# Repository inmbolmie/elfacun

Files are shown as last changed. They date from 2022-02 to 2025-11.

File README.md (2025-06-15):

# Elfacun Chess Interface Module

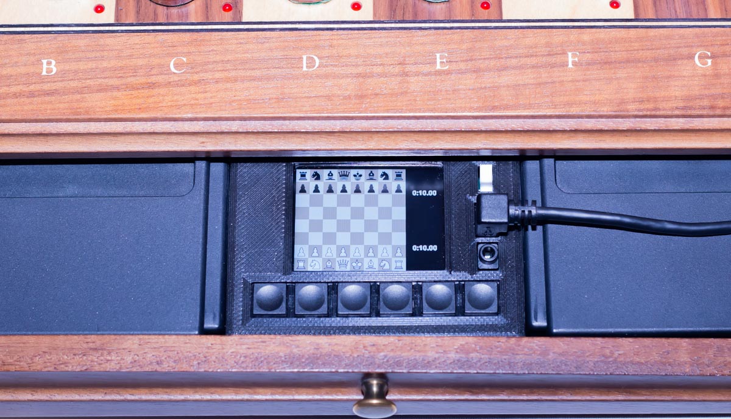
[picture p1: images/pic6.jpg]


## News

__(2025/06/15): Source code and design files for V2 module released: ----- [Make your own module](./SOURCE.md)__

## Elfacun chess module

This is an ongoing hardware project to create a chess module compatible with the old Mephisto modular boards (Exclusive, Modular, München) that will provide connectivity to a wide variety of chess apps and services.

The project currently comprises three devices:

* Elfacun chess module, that is the main module that enables the connectivity of modern apps to the Mephisto chess boards
* Brocoli power module, to be able to power Elfacun, the Mephisto board and some original modules from a regular USB power bank to get a true wireless chess board.
* Diablillo bridge adapter, that allows to connect wirelessly a physical Millennium chess module to Elfacun.

The hardware as well as software developed for it are published here under the GPL license.

To assist in the release of the module, I provide here links to some basic documentation:

* [V1 and V2 modules description and features](./DESCRIPTION.md)
* [Brocoli power module](./BROCOLI.md)
* [Diablillo bridge adapter](./DIABLILLO.md)
* [Compatibility chart](./COMPATIBILITY.md)
* [Limitations and remarks](./LIMITATIONS.md)
* [Operation manual](./MANUAL.md)
* [Make your own module](./SOURCE.md)

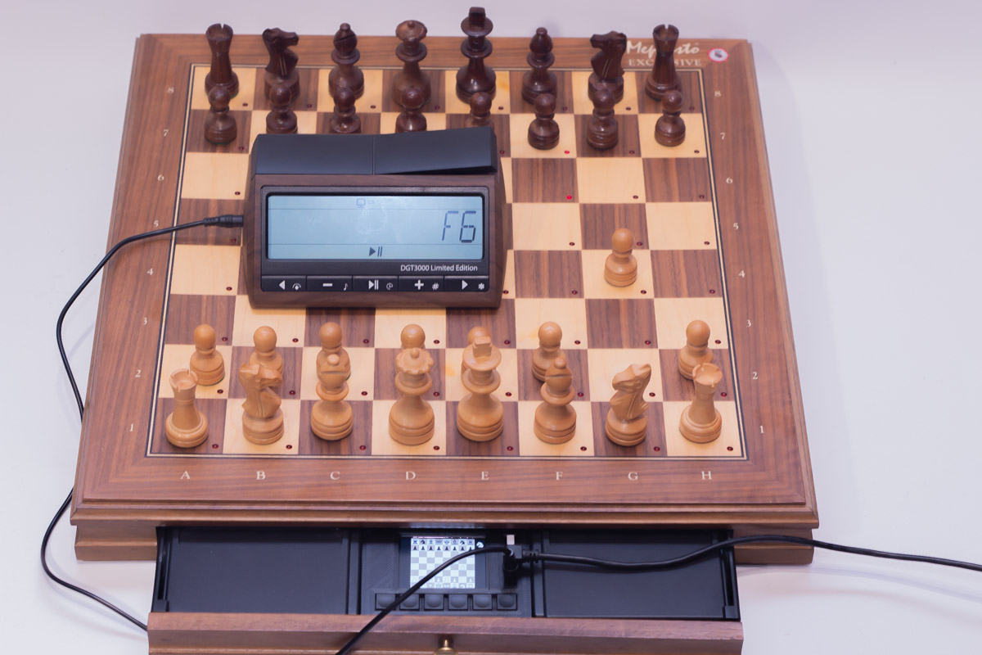
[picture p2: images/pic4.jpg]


## Old News

__(2025/02/23): Elfacun software version R15 released with chess 960 support:__ Link: ----- __[R15 files](https://github.com/inmbolmie/elfacun/releases/tag/R15)__ ----- Installation instructions: ----- __[Update Elfacun](./MANUAL.md#update-elfacun-software)__

__(2025/02/23): Diablillo software version R15 released with bug fixes:__ Link: ----- __[R15 files](https://github.com/inmbolmie/elfacun/releases/tag/R15)__ ----- Installation instructions: ----- __[Update Diabillo](./DIABLILLO.md#update-diablillo-software)__

__(2024/05/26): Elfacun software version R14 released with bug fixes:__ Link: ----- __[R14 files](https://github.com/inmbolmie/elfacun/releases/tag/R14)__ ----- Installation instructions: ----- __[Update Elfacun](./MANUAL.md#update-elfacun-software)__

__(2024/01/19): Elfacun software version R12 released with improvements for Lichess mode:__ Link: ----- __[R12 files](https://github.com/inmbolmie/elfacun/releases/tag/R12)__ ----- Installation instructions: ----- __[Update Elfacun](./MANUAL.md#update-elfacun-software)__

__(2023/09/16): Elfacun software version R11 released with new Chessnut-compatible mode:__ Link: ----- __[R11 files](https://github.com/inmbolmie/elfacun/releases/tag/R11)__ ----- Installation instructions: ----- __[Update Elfacun](./MANUAL.md#update-elfacun-software)__

__(2023/07/13): Elfacun software version R10 released with bug fixes:__ Link: ----- __[R10 files](https://github.com/inmbolmie/elfacun/releases/tag/R10)__ ----- Installation instructions: ----- __[Update Elfacun](./MANUAL.md#update-elfacun-software)__

__(2023/06/12): Elfacun software version R9 released with bug fixes:__ Link: ----- __[R9 files](https://github.com/inmbolmie/elfacun/releases/tag/R9)__ ----- Installation instructions: ----- __[Update Elfacun](./MANUAL.md#update-elfacun-software)__

__(2023/06/07): Elfacun software version R8 released with support for the new _Diablillo_ device:__ Link: ----- __[R8 files](https://github.com/inmbolmie/elfacun/releases/tag/R8)__ ----- Installation instructions: ----- __[Update Elfacun](./MANUAL.md#update-elfacun-software)__

__(2023/03/05): Elfacun software version R7 released with on-screen LED indications in passive mode, board position storage and customizable sound and BLE power level:__ Link: ----- __[R7 files](https://github.com/inmbolmie/elfacun/releases/tag/R7)__ ----- Installation instructions: ----- __[Update Elfacun](./MANUAL.md#update-elfacun-software)__

__(2023/02/08): Elfacun software version R6 released with opponent ELO range on Lichess challenges:__ Link: ----- __[R6 files](https://github.com/inmbolmie/elfacun/releases/tag/R6)__ ----- Installation instructions: ----- __[Update Elfacun](./MANUAL.md#update-elfacun-software)__

__(2023/01/30): Elfacun software version R5 released with some bug fixes:__ Link: ----- __[R5 files](https://github.com/inmbolmie/elfacun/releases/tag/R5)__ ----- Installation instructions: ----- __[Update Elfacun](./MANUAL.md#update-elfacun-software)__

__(2023/01/28): Elfacun hardware version 2 released with new features and improved compatibility with original modules:__ Links: ----- __[V2 features](./DESCRIPTION.md#features)__ ----- __[V2 manual](./MANUAL.md#new-v1-and-v2-features)__ ----- __[V2 compatibility](./COMPATIBILITY.md#v2-with-original-mephisto-modules)__

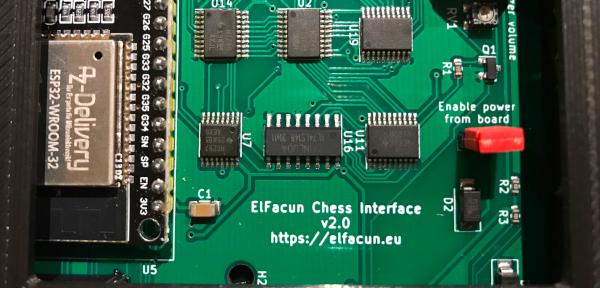
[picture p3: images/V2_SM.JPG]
V2


__(2023/01/28): Brocoli battery power module for Elfacun:__ Link: ----- __[Brocoli power module](./BROCOLI.md)__

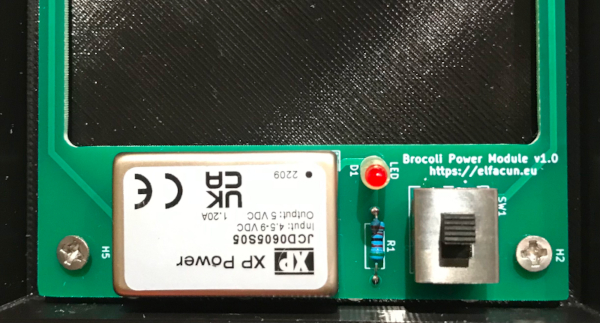
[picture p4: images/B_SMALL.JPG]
Brocoli


__(2022/05/04): Elfacun software version R4 released with some bug fixes: [R4 files](https://github.com/inmbolmie/elfacun/releases/tag/R4)__ Installation instructions: ----- __[Update Elfacun](./MANUAL.md#update-elfacun-software)__

__(2022/09/03): Source code and design files released: ----- [Make your own module](./SOURCE.md)__

_"DGT", "Millennium", "Mephisto", "Chessnut" and "IChessOne" are trademarks of their respective owners.
All the trademarks are used nominatively to indicate compatibility, and do not indicate affiliation to or endorsement by the trademark owners._

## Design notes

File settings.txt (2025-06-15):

#Elfacun settings
#Edit this file (settings.txt) and place it in the root directory of an SD card compatible with SPI mode (most micro-sd aren't)
#Power up the module with the SD inserted (you don't need to have the module inserted into the board)
#The settings will be read and stored in permanent memory
#Remove the SD card and use the module normally
#If you also want to perform a system update place in the SD card root directory the file "update.bin"

#Base MAC address. If not defined, the module will use the default MAC assigned at the factory
#so it is not recommended to modify it unless you have any problem
#Bluetooth MAC will be base MAC plus 2
#
#base.mac.address=12:34:56:78:9A:BC

#Default board mode
#This is the mode the module will boot at by default
#Valid values are: A, B, C, L
#Default value is A
#The serial port will operate at 9600 8N1 in mode A
#The serial port will operate at 38400 bauds 7O1 in mode B
#L is for Lichess mode
#To boot the module in the non-default mode, keep pressed some module buttons while booting:
#For mode A first button
#For mode B second button
#For mode C first + second buttons
#For mode L third button
#
mode.default=A

#Bluetooth name advertised in mode A
#Default value is "ELFACUN CHESS"
#
#mode.a.bt.advertised.name=ELFACUN CHESS

#Bluetooth name advertised in mode B
#Default value is "ELFACUN CHESS"
#
#mode.b.bt.advertised.name=ELFACUN CHESS

#Bluetooth name advertised in mode C
#Default value is "ELFACUN CHESS"
#
#mode.c.bt.advertised.name=ELFACUN CHESS

#Mode A board identification parameters
#Uncomment to get custom board identification values sent to the driver
#mode.a.trademark is an arbitrary string
#serial.number.long has to be exactly 10 characters long
#serial.number.short has to be exactly 5 characters long
#version numbers are numbers between 0 and 255
#
#mode.a.trademark=Elfacun https://elfacun.eu
#mode.a.version.major=0
#mode.a.version.minor=60
#mode.a.clock.version.major=2
#mode.a.clock.version.minor=0
#mode.a.serial.number.long=3.24000000
#mode.a.serial.number.short=00001

#Buzzer enabled
#Valid values are true, false
#Default value is true
#To boot the module with the opposite value, keep pressed the right-most button while booting
#
buzzer.enabled=true

#Buzzer enabled for passive led indications on screen
#Valid values are true, false
#Default value is true
#When in passive mode with original modules Elfacun cannot use the on-board leds
#so it uses the screen to indicate incoming led information. When this is enables the led
#indications on-screen are accompanied by sounds
#
buzzer.enabled.passive.led=true

#Buzzer tones setup 
#You can change the frequency and duration of the sound tones:
#Tone 1 is piece raise
#Tone 2 is piece placement
#Tone 3 is led sound for passive mode
#Frequency is in hertzs
#Duration is in milliseconds
#
#buzzer.tone.1.frequency=2000
#buzzer.tone.1.duration=100
#
#buzzer.tone.2.frequency=1000
#buzzer.tone.2.duration=100
#
#buzzer.tone.3.frequency=1500
#buzzer.tone.3.duration=20

#LEDS enabled
#Valid values are true, false
#Default value is true
#To boot the module with the opposite value, keep pressed the second right-most button while booting
#
leds.enabled=true

#DUAL LEDS enabled (Only V2 modules)
#Valid values are true, false
#Default value is false
#When a V2 module starts in passive mode and this parameter is enables, the module will scan for the
#presence of other Elfacun module (V1 or V2) using BLE. If it finds it, it will start a BLE connection to
#relay its LED status, so both modules will be able to control the board LEDs
#It is disabled by default as it only makes sense if you have two modules and with the feature disabled the
#passive mode startup will be faster
#
leds.dual.enabled=false

#REVELATION-II button order
#Valid values are true, false
#Default value is false
#If set to true, the first button will be the "change lever" button when operating in DGT mode, like in the Revelation-II board
#If set to false, the last button will be the "change lever" button
#
buttons.order.revelation=false

#Lichess mode settings
#Connection settings, you have to uncomment and complete them in order to be able to connect to lichess
#That is, you WIFI settings (ssid and password) and your lichess auth token
#
#lichess.wifi.ssid=YOUR_WIFI_NAME
#lichess.wifi.password=YOUR_WIFI_PASSWORD
#lichess.wifi.authtoken=YOUR_LICHESS_TOKEN
#
#
#Lichess board auto-reverse settings
#If auto-reverse is enabled and you play as black, the board is automatically reversed so you have to put the black pieces on the first rank
#If auto-reverse is disabled and you play as black, the board is not automatically reversed so you have to play black from the back of the board unless you manually reverse the board
#Setting is disabled by default (false)
#lichess.board.autoinvert=false
#
#
#Lichess play mode settings
#While not in a game:
#Buttons 1 to 6 are used to launch a challenge
#Once launched, you can cancel it pressing any button
#While in a game:
#Button 4 pushed twice offers take back
#Button 5 pushed twice offers a draw
#Button 6 pushed twice resigns
#You can edit the default mode definition. All the games are "standard" chess
#Game modes under 5 minutes are not allowed by Lichess being too fast for a physical board
#Game mode variables are:
# time -> Game time in minutes
# time -> Increment per move in seconds
# rated -> if the game is rated ("true") or unrated ("false")
# color -> your pieces color ("white", "black" or "random")
# elo -> The desired ELO range of the opponents ("none" to disable, or a range like "1500-1800")
#
#lichess.mode.1.time=10
#lichess.mode.1.increment=0
#lichess.mode.1.rated=true
#lichess.mode.1.color=random
#lichess.mode.1.elo=none
#
#lichess.mode.2.time=10
#lichess.mode.2.increment=5
#lichess.mode.2.rated=true
#lichess.mode.2.color=random
#lichess.mode.2.elo=none
#
#lichess.mode.3.time=15
#lichess.mode.3.increment=10
#lichess.mode.3.rated=true
#lichess.mode.3.color=random
#lichess.mode.3.elo=none
#
#lichess.mode.4.time=10
#lichess.mode.4.increment=0
#lichess.mode.4.rated=false
#lichess.mode.4.color=random
#lichess.mode.4.elo=none
#
#lichess.mode.5.time=10
#lichess.mode.5.increment=5
#lichess.mode.5.rated=false
#lichess.mode.5.color=random
#lichess.mode.5.elo=none
#
#lichess.mode.6.time=15
#lichess.mode.6.increment=10
#lichess.mode.6.rated=false
#lichess.mode.6.color=random
#lichess.mode.6.elo=none
#

#Screen brightness (Only V2 modules)
#Only for V2 modules, will be ignored on V1 modules
#Overrides the stored default screen brightness
#Valid values: 5-255
#Default value: 64
#
screen.brightness.default = 64

#Disable mode B checksum
#On R8 release checksum checking on incoming mode B messages has been enabled by default
#You can optionally disable it in case it is problematic with any app
#Valid values are true, false
#Default value is false
#
#parity.check.disabled=false

#Bluetooth power
#Set the ble and bluetooth classic power level
#it can help working with devices that are far away from the board
#It is not recommended to change this value unless you have BT reliability issues
#The valid values are 0-7
#The default value is 5
#bluetooh.power=0  -----> Corresponding to -12dbm
#bluetooh.power=1  -----> Corresponding to  -9dbm
#bluetooh.power=2  -----> Corresponding to  -6dbm
#bluetooh.power=3  -----> Corresponding to  -3dbm
#bluetooh.power=4  -----> Corresponding to   0dbm
#bluetooh.power=5  -----> Corresponding to  +3dbm
#bluetooh.power=6  -----> Corresponding to  +6dbm
#bluetooh.power=7  -----> Corresponding to  +9dbm
#
#bluetooth.power=5

#Scally homage
#Valid values are true, false
#Default value is false
#If enabled it will show a short homage screen to Alan 'Scally' Cooper on the module startup
#Alan was a key contributor to this project
#
#scally.homage=true

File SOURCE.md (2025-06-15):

# Elfacun Chess Interface Module

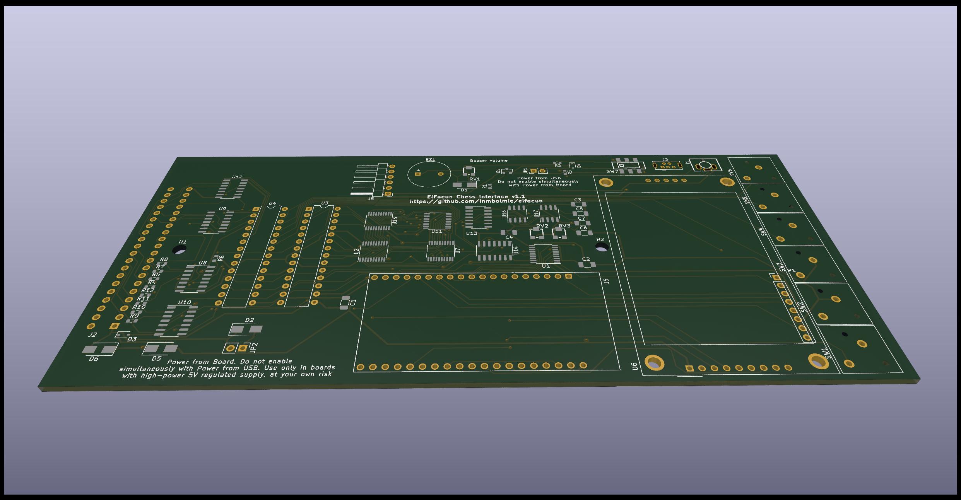
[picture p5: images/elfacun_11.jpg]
Elfacun


## Make your own module

### Introduction

I include here all the resources needed to build a module.

There are separated design files for V1 and V2 hardware. The firmware is the same for both versions though.

The V2 module main improvement is on the board date capture circuit. The board position is now stored on two dedicated RAM chips, and this allows for universal compatibility with any original Mephisto module.

Building a module from scratch is not easy. I will try to give some caveats for each step. You will need to:

* Make a PCB with the provided fabrication files, or customize one from the Kicad design files
* Get all the components and assemble the PCB
* Make a 3D-printed case
* Use the provided firmware or compile one from the Arduino source code
* Upload resources and firmware to the ESP32
* Assemble the PCB into the case

I don't recommend you to make this unless you have knowledge and equipment to debug any problem that could arise. The module is pretty hard to debug with so many SMT components. Having at hand good desoldering equipment is also recommended. The board-module connection, being deep inside the module slot is also hard to reach to be able to sample it with an oscilloscope or logic analyzer.

Anyway if you are into making this you can write me for help to the address __inmbolmie [at] gmail [dot] com__

### PCB design files

Included in the directory _Kicad_ You will need Kicad 6 to open them. I include the schematics and pcb design. [Schematics V1 PDF](./Kicad/v1.1/Elfacun_schematic_v1.1.pdf)  [Schematics V2 PDF](./Kicad/v2.1/Elfacun_schematic_v2.1.pdf)

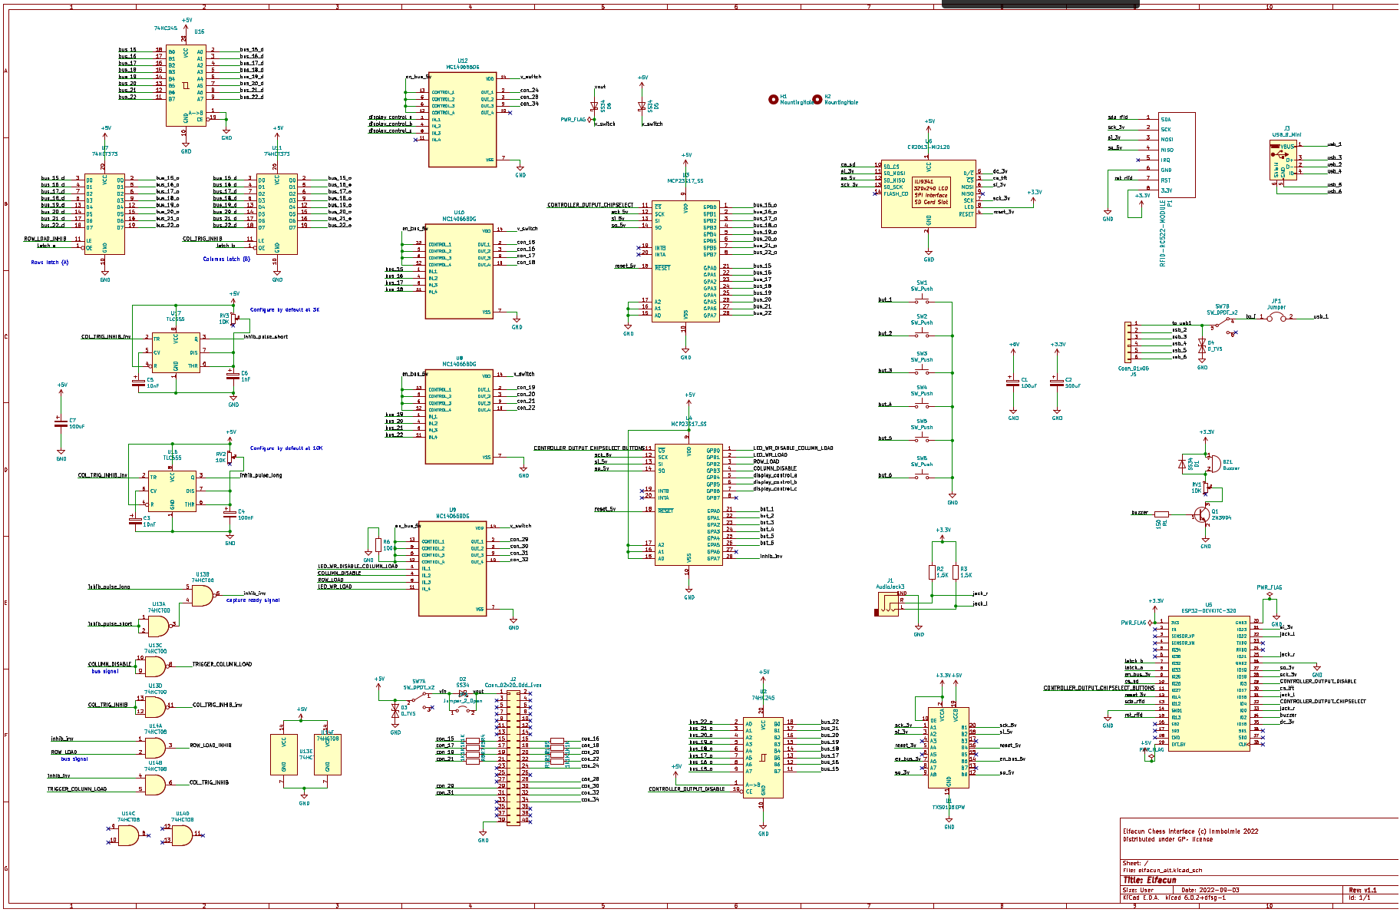
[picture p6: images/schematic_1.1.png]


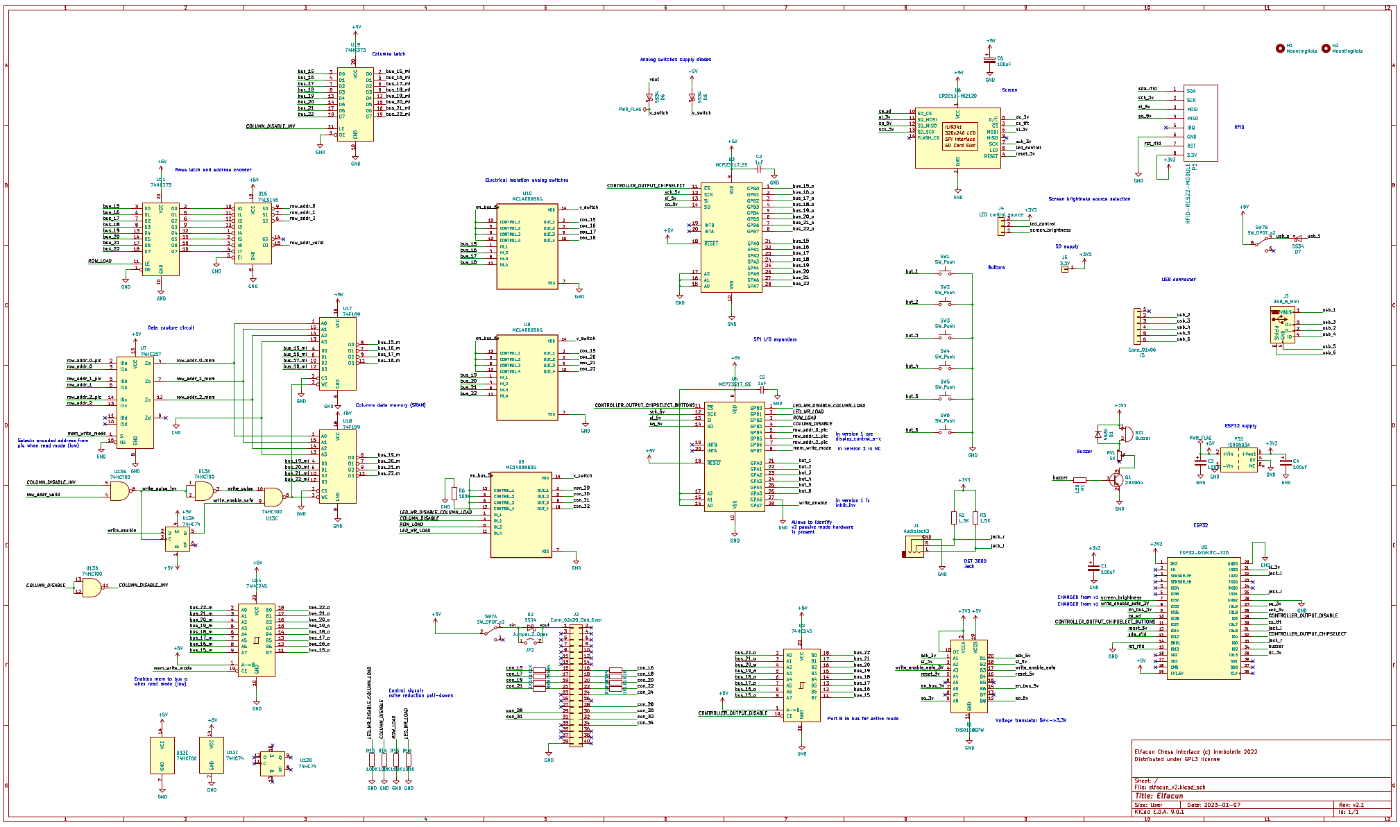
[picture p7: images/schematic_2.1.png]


### PCB Fabrication files

If you want to skip the Kicad step you can use the included gerber, cpl and bom files to order the PCBs. The files are formatted for JLCPCB use but I do not endorse JLCPCB in any way. You can generate files for other fabricators from the Kicad design files though. The SMT mounting service is optional, you can order without it and assemble everything yourself.

### Components

The boards can be ordered pre-assembled and most of the components are referenced in the bom file. Availability of components come and go so sometimes some components will need to be changed.

Those are the additional components that you need not included in the BOM file. I cannot advise or endorse a particular provider for the components

* 2x MCP23S17 DIP (through hole)
* 2x 74F189 DIP (through hole, only V2 module)
* 1x AZDelivery ESP32 WROOM-32 (be aware that there are dozens of similar boards, I cannot advise about compatibility for those)
* 1x ILI9341 2.2 inch screen module
* 6x PB13 Square 12*12mm SPST momentary buttons
* 1x 40-pin 90-degree angled card edge connector (EDAC 395-040-558-212)
* 1x electromagnetic buzzer
* 1x RFID RC522 mini module
* Approx. 1.5m of Wire-wrapping wire to make the RFID antenna
* 1x PJ-359 audio jack connector
* 1x 30cm micro-USB cable
* Angled and straight standard pin headers
* 1x Jumper

### PCB Assembly

A more detailed guide could be made in the future, but some basic steps are:

* Prepare the button assembly  gluing the buttons to the button holder
* Solder all the components except for the screen and RFID module
* Solder the wire-wrapping cable to the RFID module, removing the two central resistors and soldering each cable lead to one of the external pads
* Solder the RFID module in a way that the screen could be properly mounted
* Wrap the antenna around the buttons securing it with something like hot glue
* Solder the screen using a couple of 3D-printed screen holders to hold it at the proper height. If too high the case won't close, if too low the module will look ugly.
* Prepare the internal USB cable cutting it and attaching a 6-pin female Dupont connector with this pinout (seeing from the front of the module, from left to right):
  * Red
  * White
  * Green
  * [empty]
  * Black
  * [empty]

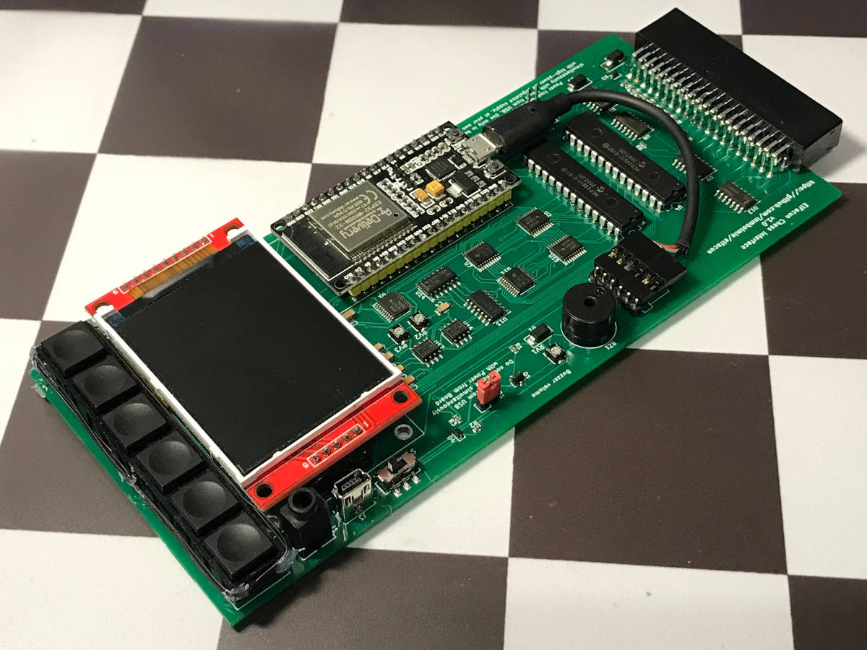
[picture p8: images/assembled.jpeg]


### 3D-printed case

I include the STL files for all the case components. The case was designed with Freecad but I won't provide the current design files as they are not properly made and it would be easier to make them from scratch that to try to modify them.

The needed parts are:

* 1x Top Case. Print (most likely) with supports
* 1x Bottom Case. Print with supports
* 6x poles to be glued to the bottom Case. Print horizontally
* 1x Button holder to raise the buttons
* 1x Switch, print horizontally
* 2x Screen holders, optional to assist in soldering the screen

The case width is critical for the module to slide properly into the board, so the printer has to be properly calibrated to get the same width or slightly less than the original modules.

### Case assembly

Be careful with the poles as the will be most likely more fragile than those in an original module

I print my cases in black PLA but it would be nice to print them in ABS.

### Software

Source code is provided in the _elfacun_ directory. I use Arduino version 1.8.18. The Arduino environment needs a ton of extra customization, I will try to complete this section in the future  with a guide to replicate it.

Needed Arduino libraries:

* ESP32 1.0.6
* BluetoothSerial version 1.0
* MCP23S17 version 1.1.3
* SPI version 1.0
* TFT_eSPI version 2.3.59
* FS version 1.0
* SPIFFS version 1.0
* WiFi version 1.0
* WiFiClientSecure version 1.0
* ArduinoJson version 6.18.5
* SD version 1.0.5
* SDConfig version 1.1
* Ethernet version 2.0.0
* BLE version 1.0.1
* MFRC522 version 1.4.8
* Update version 1.0

Before programming the board you will need to upload SPIFFS resources from the _data_ directory to the ESP32 board. You will need a 8MB ESP32 or use a custom partitioning schema with a 4MB one: __1.8MB with OTA plus 320KB SPIFFS__. The default schemas won't work.

### Additional notes

To power the module I recommend using a mini-USB angled connector to release some stress from the mini-usb connector. With a straight connector you risk ripping it accidentally from the board as it will protrude a lot. The connector has to be angled _up_ for the cable to go to the right and outside the module. A _down_ angled cable will go over the screen, and _left_ and _right_ angled cables will interfere with the on-off switch or the jack connector.

_"DGT", "Millennium", "Mephisto", "Chessnut" and "IChessOne" are trademarks of their respective owners.
All the trademarks are used nominatively to indicate compatibility, and do not indicate affiliation to or endorsement by the trademark owners._

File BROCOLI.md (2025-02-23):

# Elfacun Chess Interface Module

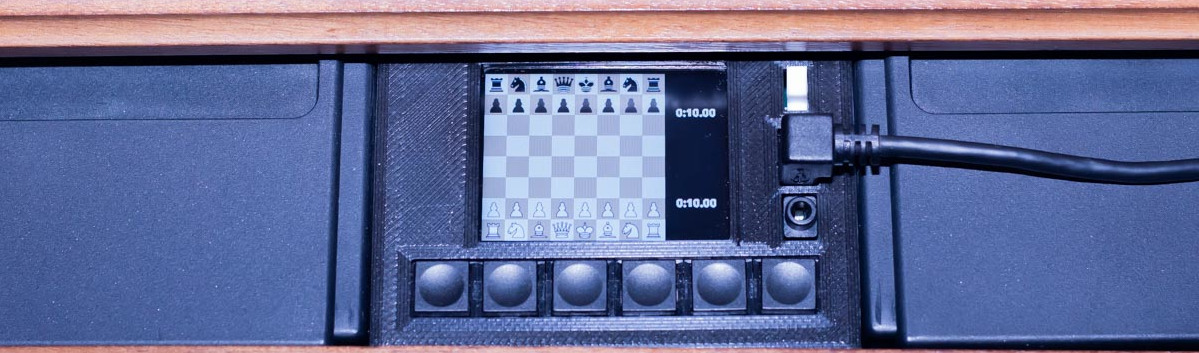
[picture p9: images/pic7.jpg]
Elfacun


## Brocoli Power Module

The Brocoli power module allows you to operate Elfacun wirelessly and in some situations operate the board with the drawer closed. It can work with V1 and V2 modules plus with most original 5V Mephisto modules. Brocoli gets its power from a user-provided standard USB power bank.

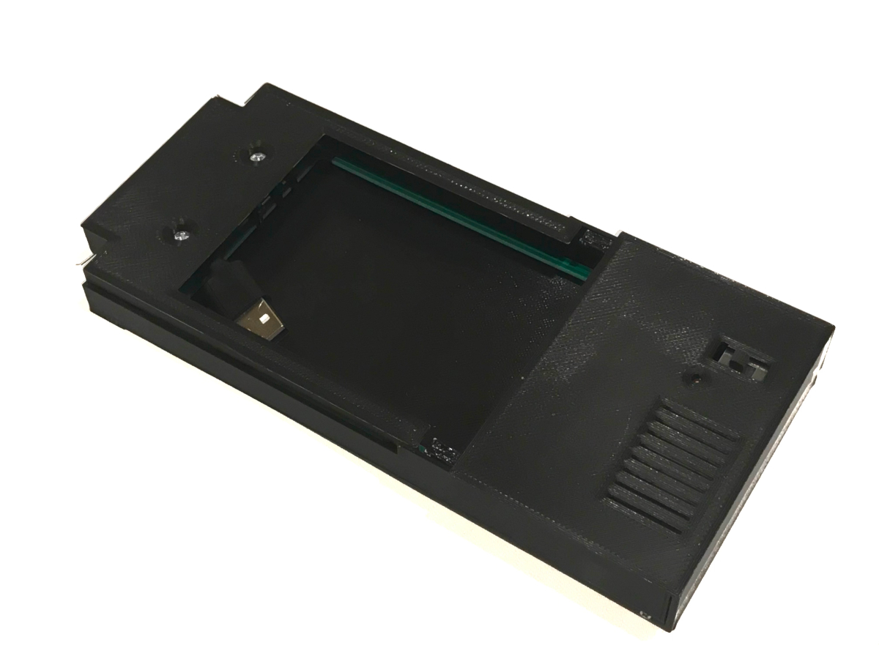
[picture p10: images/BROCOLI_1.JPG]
Brocoli


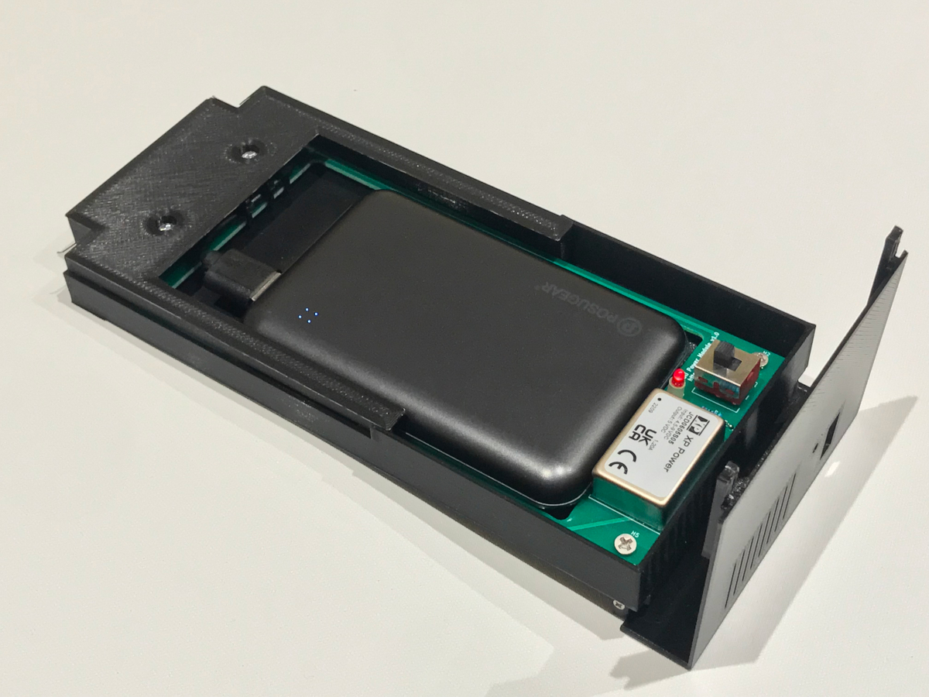
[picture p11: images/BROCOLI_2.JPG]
Brocoli


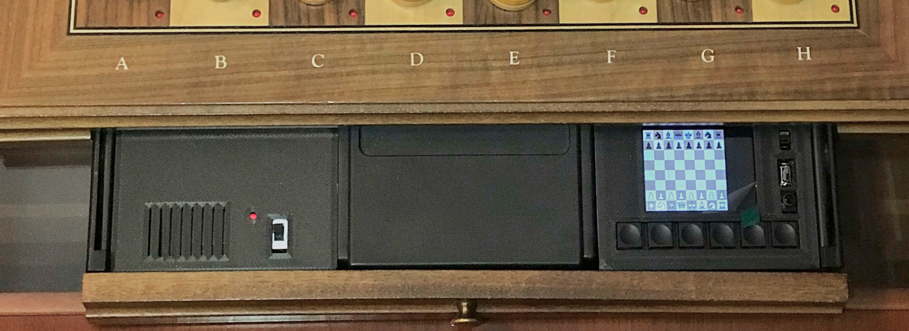
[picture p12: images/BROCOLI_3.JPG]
Brocoli


## Features

The module features are:

* Gets power from a standard USB power bank
* Gives 5V stabilized supply direct to the board and modules
* Provides up to 6W of power (1.2 amps at 5 volts)
* Gives 1.6KV isolation between the USB power bank and the board power rails
* Overcurrent protection for the USB power bank
* Short-circuit protection for the USB power bank
* On-off switch
* On led indicator

## Choosing a suitable power bank

Brocoli is provided without a power bank, the user has to provide his own.

The main limitation for choosing a power bank is that it has to fit inside the Brocoli module. The maximum dimensions for the bank are:

* Width: 68mm
* Depth: 106mm
* Height: 16mm

If the power bank exceeds any of these dimensions it may not fit inside Brocoli, or Brocoli may not fit inside the board.

Most 5.000Mah power banks will fit on these dimensions, but check always anyway. Most 10.000Mah power banks won't fix except for a few that will be a tight fit.

The power bank has to provide a USB-A connector. Also it is better if the bank has the A-type connector sided, as showed on this photo

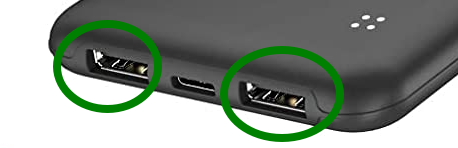
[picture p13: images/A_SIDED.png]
Connector


If the connector is centered it may work anyway but you may have to cut a zip tie on the back of the module to be able to get more play for the cable. The USB cable on the module is not detachable.

The power bank has to be able to provide at least 2 amps at full load (10W) to be on the safe side. If you are using only Elfacun 1 amp is more than enough but you won't be able to power the more power-hungry original modules with that, just Elfacun.

It is better if the power bank is of the type where you don't need to push a button to start it. That way you can just use the power button on the Brocoli module to control the power bank.

It is also a desirable feature that the power bank does not swith off with small loads. Some power banks switch themselves off if they don't detect a high load from a charging device like a phone.

## Tested power banks

These are the power banks that are tested to work.

* Posugear 10.000Mah. Only the kind that has 4 leds forming a square to indicate the charge level. This one has two power connectors on the sides. The center C connector is for charging only

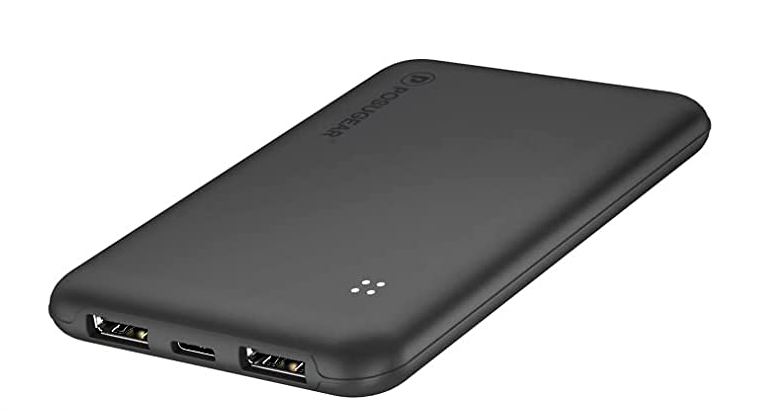
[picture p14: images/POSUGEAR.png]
Posugear


* VEGER 10.000Mah, but this has the USB connector in the center so it is not ideal but it will work.

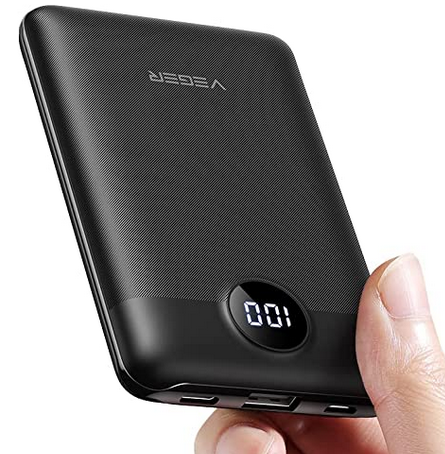
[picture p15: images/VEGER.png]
Veger


## Battery life.

With a 10.000 Mah power bank you can expect 24 hours of continous operation with Elfacun on the default screen brightness configuration, and 12 hours in Lichess mode.

In theory using the USB cable connection to the module you can switch "live" the power bank without a need to switch the module off.

## Instructions

Do not use the power module and power from the board at the same time.

If you are using Brocoli with a high-power original module it is not recommended to close the board drawer to improve cooling. That is recommended anyways with any original module that has vent holes on its case, with or without Brocoli.

## Using Brocoli with V2 modules

To use Brocoli with Elfacun V2 just make sure the front jumper is installed to enable power from the board.

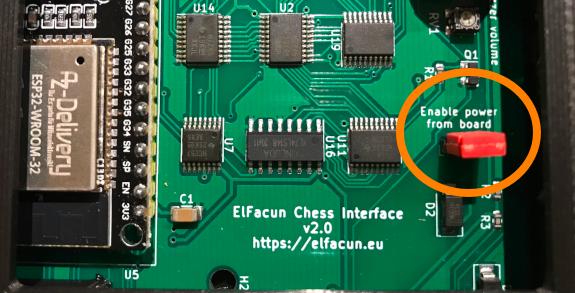
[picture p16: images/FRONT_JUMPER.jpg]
V2 jumper


## Using Brocoli with V1 modules

To use Brocoli with Elfacun V1 the power from the board jumper is on the back side so you have to open the module to install it.

First you need to open the module lid, very carefully beginning on one corner and opening first a complete side and then the other, as the 3D-printed poles are not as sturdy as on the original modules.

Then unscrew the two screws that hold the PCB to the upper case and separate the PCB from the case.

Now you can install a jumper in the pins labelled as "power from the board"

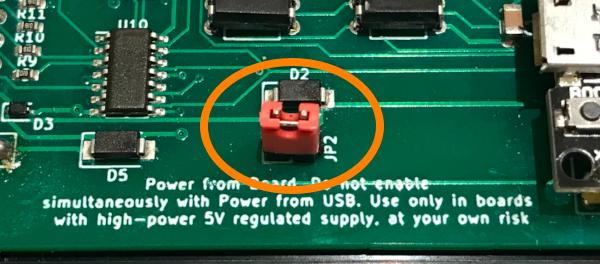
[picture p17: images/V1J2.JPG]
V1 jumper


Be warned that if you want to use later a 6V original module with "power from the board" you may have to open the module again to remove the jumper.

## Using Brocoli with original modules

Brocoli has been tested to work with most 5V original modules. Currently the only untested modules that can suppose a problem are RISC and RISC 2.0. Do not use brocoli with 6V modules unless you modifiy the module to remove the diode that drops the input voltage.

_"DGT", "Millennium", "Mephisto", "Chessnut" and "IChessOne" are trademarks of their respective owners.
All the trademarks are used nominatively to indicate compatibility, and do not indicate affiliation to or endorsement by the trademark owners._

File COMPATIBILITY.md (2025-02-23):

# Elfacun Chess Interface Module

Elfacun

## Compatibility

### Tested apps

Link to the updated compatibility list:

__Tested on 2023/01/28 the Chess.com Android app now seems to be fully functional with Elfacun__

[https://docs.google.com/spreadsheets/d/1rMWfw44kpx4Kv_j8r7nwF5NkYwYT0HwvDeeQWXStNT4/edit?usp=sharing](https://docs.google.com/spreadsheets/d/1rMWfw44kpx4Kv_j8r7nwF5NkYwYT0HwvDeeQWXStNT4/edit?usp=sharing)

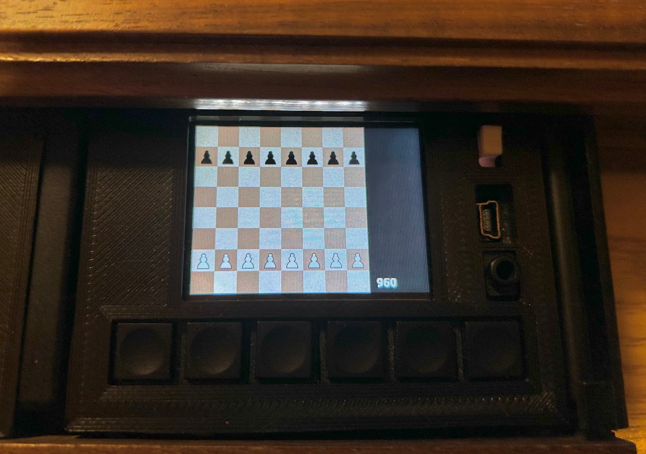
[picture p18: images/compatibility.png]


### V2 with original Mephisto modules

The passive mode on V2 is now much improved from V1 and can be considered that it will work with any original Mephisto module that physically makes sense to work alongside.

The module has been explicitly tested or reported to work with the following original modules (Thanks to the user Scally for his invaluable help in testing V1 and V2 modules):

* Glasgow 68000
* Amsterdam 68000
* Dallas 68000
* Roma 68000
* Roma II 68000
* Almería 68000
* London 68000
* Genius 68030
* Mirage
* MMI
* MMII
* B&P
* MMIV
* MMV
* MMV 10Mhz
* MMVI
* Polgar
* Senator
* Magellan
* Elfacun V1
* Elfacun V2

The V2 module also can work alongside other Elfacun unit, V1 or V2 in the same board.

If V2 is operated with V1, make sure that V1 is started before V2, as V2 has to be the module that enters into passive mode.

Boards tested to work:

* Mephisto Exclusive
* Mephisto Modular
* Mephisto München
* Mephisto Impos Royal

Some considerations about passive mode on V2 follows:

#### Original modules that need 3 slots

On modules that need 3 slots (for example Amsterdam) as you have to leave a slot for Elfacun you will have to operate without one of the modules, and either lose screen or keyboard functionality. In that case it is preferrable to lose the display, as the keyboard is normally needed to manage pawn promotion.

#### Power from USB

On V2 power from USB is always enabled.

#### 6V Boards

To operate reliably on a 6V board with 6V modules (like MMII, B&P or Rebell 5.0) you may have to [disable power from board removing the jumper](./MANUAL.md#enable-or-disable-power-from-board), and power the original module from the board with the original power supply and Elfacun via USB. Normally you can operate a 6V module on 5V boards by removing one diode on the module, but that modification is out of the scope of this document.

#### 5V Boards

With 5V boards/modules you have more options:

* Power everything from the board if the power suppy gives enough power. This most likely will only work with the more powerful original power bricks, and it is not guaranteed to work at all on a particular setup.

* Power the original module from the board with the original power supply and Elfacun from USB, with or without the jumper installed. This is the standard setup.

* Power everything from the board with the Brocoli power module. The drawback of this option is that you lose an additional board slot.

__Do not try to power an original module from USB only. The module most likely won't work and you can overload the USB port.__

#### Force passive mode

Depending on you power setup the original modules may freeze during Elfacun startup due to the sudden voltage drop. If that happens you have to [force passive mode while starting Elfacun](./MANUAL.md#force-passive-mode), and the reset the original module after Elfacun has started up.

If the original module freezes during Elfacun startup and you do not force passive mode, Elfacun will not detect the other module and will enter active mode, so the scanning will behave erratically or not work at all.

### V1 with original Mephisto modules

The passive mode on V1 (the possibility of Elfacun operating alongside the original Mephisto modules) should be considered experimental, and it cannot be guaranteed to work beyond what it has been tested.

Currently this mode has been tested to work with the following modules and boards:

Modules tested to work:

* Mephisto MMII
* Mephisto MMIV
* Mephisto MMV
* Mephisto MMV 10Mhz
* Mephisto Polgar (thanks to Scally for the testing and report)

Modules tested that DO NOT currently work:

* Mephisto Senator (thanks to Scally for the testing)
* Mephisto Glasgow (incompatible)
* Mephisto Amsterdam (incompatible)
* Mephisto Dallas (incompatible)
* Mephisto Roma (incompatible)

Boards tested to work:

* Mephisto Exclusive
* Mephisto Modular
* Mephisto München
* Mephisto Impos Royal (Thanks to Scally for the testing)

In all the cases **the original modules have been powered from the board**, while Elfacun has to be powered from USB. It is important to power up the Mephisto module before powering up Elfacun, so that Elfacun can detect that the module is operating while it is starting up.

Elfacun needs dedicated hardware to be able to capture the communication between the original module and the board. That data capture is timing-critical, and different modules will have different timings that cannot be predicted and have to be measured on the real hardware. The board scanning and LED driving signals needs also to be differentiated for proper operation, and modules beyond those that have been tested could operate differently, and be not compatible with the current implementation.

There are a couple of potentiometers on-board that can be adjusted to try to compensate for timing differences up to a point but that doesn't provide a total guarantee that you will be able to adjust them to operate with any module.

The critical timings are:

* Short delay, that is the delay from the time row data is available to the time we can start to capture column data
* Long delay, that is the time we will wait since we end capturing column data until we can start the capture process for the following row.

That delays can be adjusted with the RV2 and RV3 variable resistors

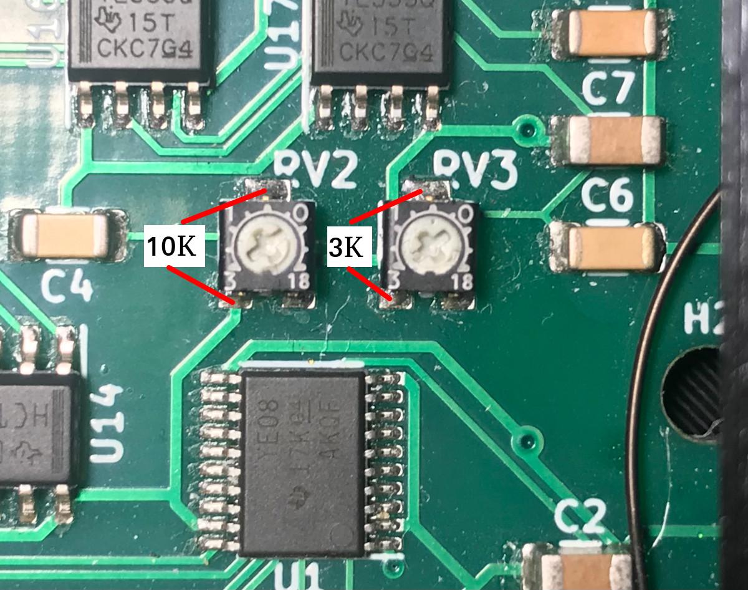
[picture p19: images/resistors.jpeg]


The default adjusted values are:

* RV2: 10Kohm (long delay)
* RV3: 3Kohm (short delay)

### ChessLink (IOS, Android)

The LED lights are not operational as they are shown with a big delay for unknown reasons. Until solved, it is recommmended to disable the LEDs if you are going to use the module with this app. That can be done by default with SD-card configuration, or temporarily booting the module with its fifth button pressed.

### HIARCS (Windows)

HIARCS Chess Explorer on Windows (versión 1.4) and MacOS have been reported to work fine with the module.

### ARENA (Windows)

The clock data doesn't work well with Arena with Elfacun in DGT mode.

### Picochess

Picochess works fine with Elfacun but you will have to force the Revelation-II mode with a small code modification if you want to have LED support enabled.

[Using Elfacun with Picochess](MANUAL.md#using-elfacun-with-picochess)

### Rabbitplugin (Windows)

Some apps like Shredder Classic don't work at all interfacing Elfacun with Rabbitplugin, but work fine with the replacement Graham O'Neill DGT or Millennium drivers. You can get them here:

[https://goneill.co.nz/chess.php](https://goneill.co.nz/chess.php)

_"DGT", "Millennium", "Mephisto", "Chessnut" and "IChessOne" are trademarks of their respective owners.
All the trademarks are used nominatively to indicate compatibility, and do not indicate affiliation to or endorsement by the trademark owners._

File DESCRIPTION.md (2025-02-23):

# Elfacun Chess Interface Module

Elfacun

## Description

Elfacun hardware is based on popular standard-of-the-shelf components. That means that it will be relatively easy for anyone to get the components to make one, and be able to fix the modules when needed in the future. The module is buit around the ESP32 microcontroller, that provides most I/O, computing and communications capabilities.

The module as initially available will be provided with the following elements:

* Elfacun chess module PCB pre-programmed and ready to use.
* 3D-printed case.
* USB to Mini-USB angled cable.
* 75 RFID tags for the chess pieces, enough to equip two piece sets.
* SD card for software update and user configuration.

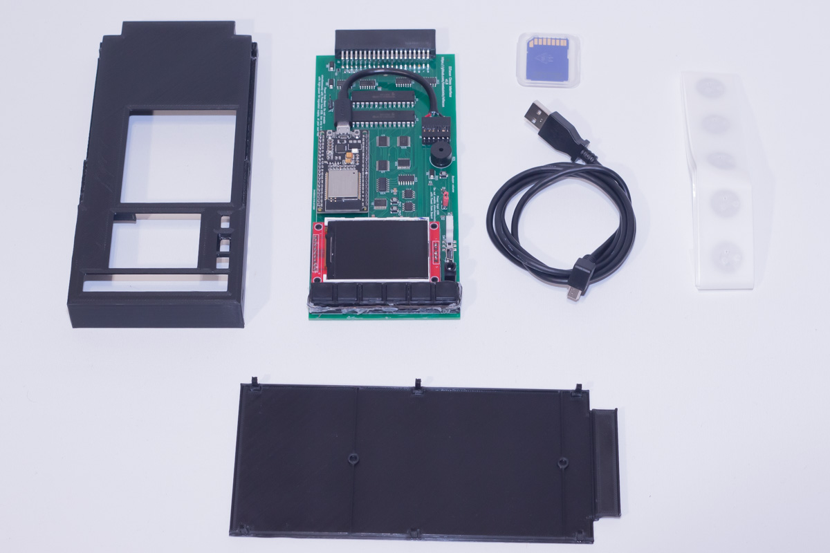
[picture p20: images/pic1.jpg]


## Features

Tha main module features are:

__V2 new features:__

* V2 is compatible with all original Mephisto modules. (V1 can play alongside some original Mephisto modules)
* On the V2 module the screen brightness can be adjusted.
* V2 is designed to be more reliably powered from the board, specially alongside the Brocoli power module, so it is more suitable to get a totally wireless Mephisto board.
* On the V2 module you have access in passive mode to the dual LED mode, where you can have two Elfacun modules controlling the board leds simultaneously. Both chess apps will be able to signal its computer moves using the board leds.

__V2 and V1 features:__

* Compatible with Modular, Exclusive, München and Impos Royal boards.
* Plug and play. The module is configurable but basic operation can be performed without any configuration.
* Compatible with most DGT-compatible apps.
* Compatible with most ChessLink-compatible apps.
* Compatible with most Chessnut-compatible apps (starting on R11 firmware)
* Supports Chess 960/Fischer Random starting positions (starting on R15 firmware)
* USB Connectivity to chess apps.
* Bluetooth Connectivity to chess apps.
* Bluetooth Low Energy (BLE) connectivity to chess apps.
* WIFI support for direct connection to Lichess.org.
* 2.2'' 320x240 TFT color screen with board position and clock info where available.
* Compatible with the DGT-3000 clock.
* Can emulate a DGT 3000 clock (mode 25 only) with DGT-compatible apps.
* Board LEDs operation supported.
* The module can scan RFID tag equipped pieces.
* The module can track the pieces over the board without a need to scan them.
* It can take back movements without a need to scan the pieces.

Video demonstrating the module functionality:

[https://youtu.be/sNqQtBvz1Ds](https://youtu.be/sNqQtBvz1Ds)

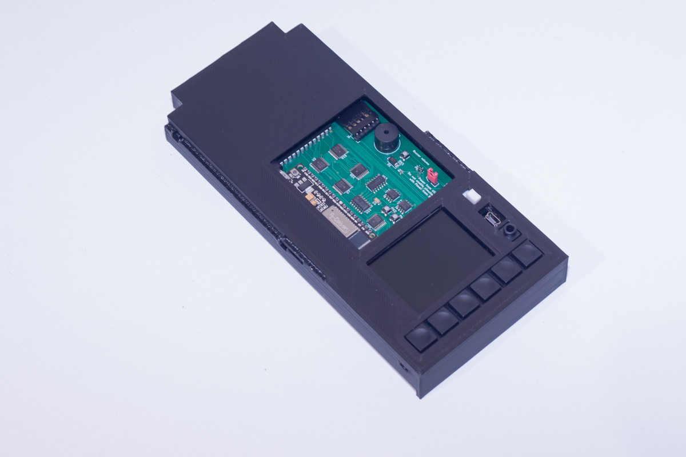
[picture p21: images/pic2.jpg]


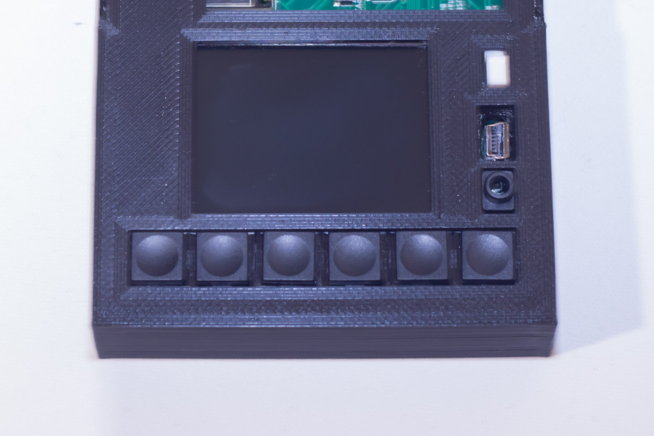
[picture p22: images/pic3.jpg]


Elfacun

_"DGT", "Millennium", "Mephisto", "Chessnut" and "IChessOne" are trademarks of their respective owners.
All the trademarks are used nominatively to indicate compatibility, and do not indicate affiliation to or endorsement by the trademark owners._

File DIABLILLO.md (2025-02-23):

# Elfacun Chess Interface Module

Elfacun

## Diablillo chess bridge adapter

The Diablillo bridge adapter allows you to connect a physical Millennium chess module to Elfacun wirelessly.

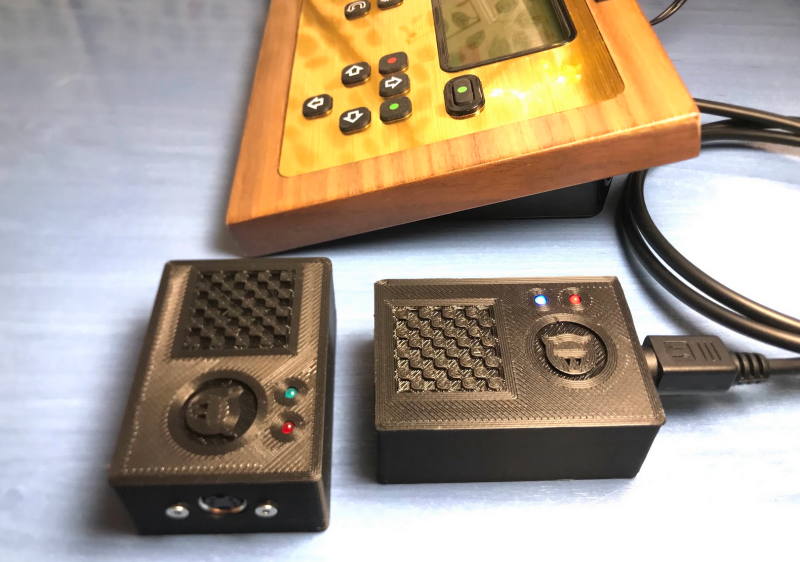
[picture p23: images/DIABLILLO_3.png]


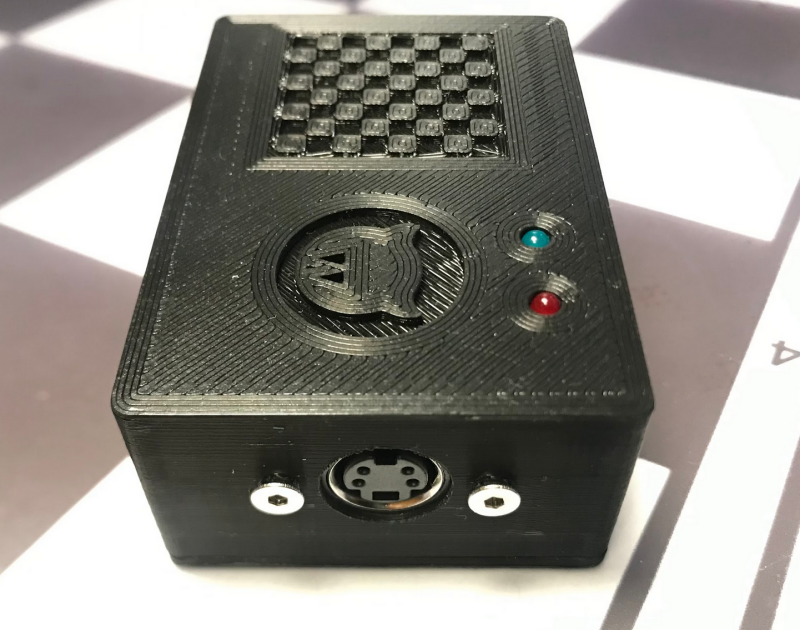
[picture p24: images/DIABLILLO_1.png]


## Usage

Diablillo is a zero-configuration device. To use it, just plug it to the Millennium using your original mini-DIN4 cable (the cable you would use to connect the Millennium module to a standard Millennium board). Then start your Elfacun module. The Diablillo will just connect to the module and you can start using it.

The module has two LED lights:

* The red light indicates that the adapter is powered on.
* The blue led when blinking slowly indicates that it is searching for a suitable board to connect to.
* The blue led when it is on all the time indicates that a connection with a board has been established.

If the connection to the board is lost it will automatically start looking for another board to connect to.

## Update diablillo software

The Diablillo module is updated through a Elfacun module using its SD card reader.

The update file for Diablillo will look like "remote_0xcfcfbb2f.bin" The update files will be deleted from the SD card by the module after each successful update.

To update it simply boot Elfacun in mode A with the SD card inserted containing the "remote_0xXXXXXXXX.bin" update file, and then connect the Diablillo to any Millennium module to power it on.

The diablillo will connect to Elfacun and start updating. Elfacun will be freezed during the process. While updating, the Diablillo blue LED will blink fast indicating that an update is in process. The process will take between 2 and 4 minutes. __The Diablillo shouldn't be too far away from Elfacun and try to keep the mini-DIN4 cable tightly plugged and the power on for both Elfacun and the Diablillo during the process__.

When finished one of two things may happen:

* The Diablillo reboots, starts searching for a module and connects back to Elfacun, at that point the blue LED will stay on solid. This indicates a successful update.
* The blue LED stays off and nothing happens. This indicates an update error. It can be a transmission error or that the file on the SD card is corrupted.

After a successful update you can start using the Diablillo normally.

_"DGT", "Millennium", "Mephisto", "Chessnut" and "IChessOne" are trademarks of their respective owners.
All the trademarks are used nominatively to indicate compatibility, and do not indicate affiliation to or endorsement by the trademark owners._

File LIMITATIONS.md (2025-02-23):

# Elfacun Chess Interface Module

Elfacun

## Known Limitations

### General operation

Piece sliding is not recommended at this point, you should always lift and place the pieces you move. Future updates could allow or improve piece sliding support.

For taking pieces it is irrelevant if you lift first the taking or the taken piece, it will work both ways. To take back movements where a piece has been taken, you have to undo the movement before placing back the taken piece though.

### 3D-printed case

A custom 3D printed case is provided for the module. It has been designed to be mechanically similar to the original module cases, but adapted to the button and screen layout of Elfacun.

A 3D printed case is easy and cheap to produce for a small-scale project like this, but has some drawbacks:

* Aesthetically will be always worse than a injection-molded case

* The small hooks that fit together the top and bottom parts are more fragile than in the original modules. For that reason the module has an opening on top of the case for the user to have access to the SD card slot and adjustable potentiometers withoud a need to remove the module from the case. So it is better not to try to open the case, or at least being very careful if it needs to be done. In case some of the hooks snapped, it wouldn't affect the module integrity at all, because when inserted into the board slot the two parts will be held in place together anyway.

### Connectivity

Elfacun uses the on-board USB, WIFI and Bluetooth resources of the ESP32 module, so it will be able to connect to any system as far as that system is compatible with the ESP32 WIFI and Bluetooth modes. More details can be found here:

[http://esp32.net/](http://esp32.net/)

    Wi-Fi: 802.11 b/g/n/e/i (802.11n @ 2.4 GHz up to 150 Mbit/s)
    Bluetooth: v4.2 BR/EDR and Bluetooth Low Energy (BLE)

### Passive mode operation

Pasive mode is disabled while in Lichess mode, as it would be against their rules to receive computer assistance from a module while in a game.

While in passive mode it can be tricky to fix mangled board positions or take back movements. Think that you have two separate systems (Elfacun and the original module) listening to the piece movements, so anything you make will be applied equally in both sides at the same time, and can be interpreted differenty by the modules if they have different rules. So when in passive mode try to be very careful moving pieces and try not to make worng movements or drop any pieces, because that mistakes could be difficult to fix while in a game.

For pawn promotion, usually the original modules will require you to press a button to indicate the piece you promote to.

In passive mode the original module controls the board leds, so you need to get the opposing movements somewhere else, like in the app you have connected to Elfacun or in the DGT3000 clock messages if operating in DGT mode.

### Lichess mode

Lichess mode is based on the public Lichess Board API. This API has some limitations. Other limitations come from the limited resources available in the ESP32 to implement this mode. These limitations only apply to the native Lichess mode (via WIFI), so if you play Lichess through a connected app (like White Pawn) the limitations don't apply.

The Lichess Board API doesn't allow to launch games with blitz time controls. The minimum recommended time control to play on a board is 10+0 and over. If you try to launch a challenge with an invalid time control from the board, the challenge could be rejected or launched on a different time control.

The Lichess TV stream does not contain game result data, and it would be complicated to make additional requests to get that data, so no game results are displayed in Lichess.tv mode. When a game ends the module will simply start to show the next game.

### Updating software

Software update through USB is not directly supported. Part of the ESP32 module programming hardware has been disabled due to incompatibilities with some apps in Windows when connecting to them through USB. If you ever want to program the ESP32 via USB you would have to manually enter programming mode and reset the module. This should not be a problem to regular users because the module supports software update using the SD card reader.

### V2 PCB

The first revision of V2 PCB has two patched mistakes that doesn't affect the module functionality, and will be fixed in subsequent releases.

### PCB

The first version PCB has two patched mistakes that doesn't affect the module functionality, and will be fixed in subsequent releases:

* The buzzer transistor had to be reversed as it was installed in the wrong orientation
* There is a patch wire that enables the bus switches directly from +5V. It was found during testing that the original 3,3V signal was not high enough to enable them in some cases (when using on 6V board power supplies).

_"DGT", "Millennium", "Mephisto", "Chessnut" and "IChessOne" are trademarks of their respective owners.
All the trademarks are used nominatively to indicate compatibility, and do not indicate affiliation to or endorsement by the trademark owners._

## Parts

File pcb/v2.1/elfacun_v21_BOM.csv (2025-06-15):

Comment | Designator | Footprint | LCSC
100uF | C1,C3,C4,C6 | Capacitor_SMD:C_1206_3216Metric | C15008
1uF | C2,C5 | Capacitor_SMD:C_0603_1608Metric | C15849
SS34 | D1,D2,D5,D6,D7 | Diode_SMD:D_SMA | C8678
USB_B_Mini | J3 | Connector_USB:USB_Mini-B_Tensility_54-00023_Vertical | C13453
2N3904 | Q1 | Package_TO_SOT_SMD:SOT-23 | C18536
150 | R1 | Resistor_SMD:R_0603_1608Metric | C22808
1,5K | R2,R3 | Resistor_SMD:R_0603_1608Metric | C22843
1K | R4,R5,R7,R8,R9,R10,R11,R12 | Resistor_SMD:R_0603_1608Metric | C21190
100K | R6,R13,R14,R15,R16 | Resistor_SMD:R_0603_1608Metric | C25803
5K | RV1 | potent:RES-ADJ-SMD_G32AT | C128119
SW_DPDT_x2 | SW7 | dpdt_2:SW-TH_K3-2235S-K1 | C145845
TXS0108EPW | U1 | Package_SO:TSSOP-20_4.4x6.5mm_P0.65mm | C53406
74HC373 | U11,U19 | Package_SO:TSSOP-20_4.4x6.5mm_P0.65mm | C132998
74HC74 | U12 | Package_SO:SO-14_3.9x8.65mm_P1.27mm | C39990
74HCT00 | U13 | Package_SO:SOIC-14_3.9x8.7mm_P1.27mm | C6764
74LS148 | U16 | Package_SO:SOP-16_3.9x9.9mm_P1.27mm | C521196
74HC245 | U2,U14 | mis_partes:SOIC-20_L13.3-W5.5-P1.27-LS7.8-BL | C133641
74HC257 | U7 | Package_SO:SOIC-16_3.9x9.9mm_P1.27mm | C7645
MC14066BDG | U8,U9,U10 | Package_SO:SOIC-14_3.9x8.7mm_P1.27mm | C52828

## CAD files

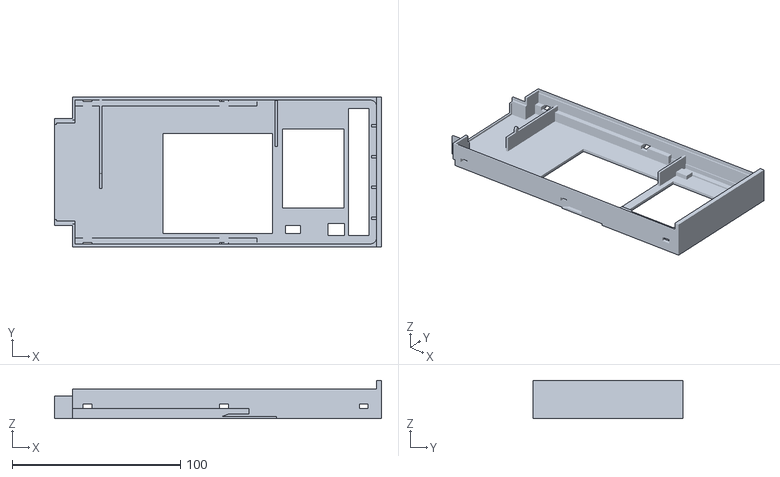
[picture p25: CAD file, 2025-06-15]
3dcase/v2/top.stl
194.6 x 89.0 x 22.7

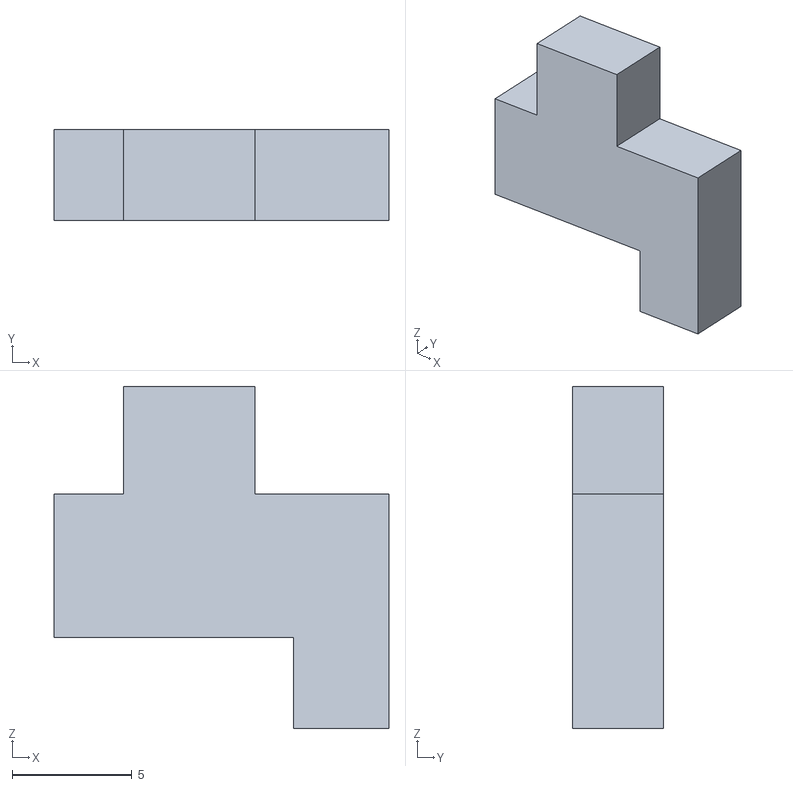
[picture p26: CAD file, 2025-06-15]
3dcase/v2/switch.stl
14.0 x 3.80 x 14.3

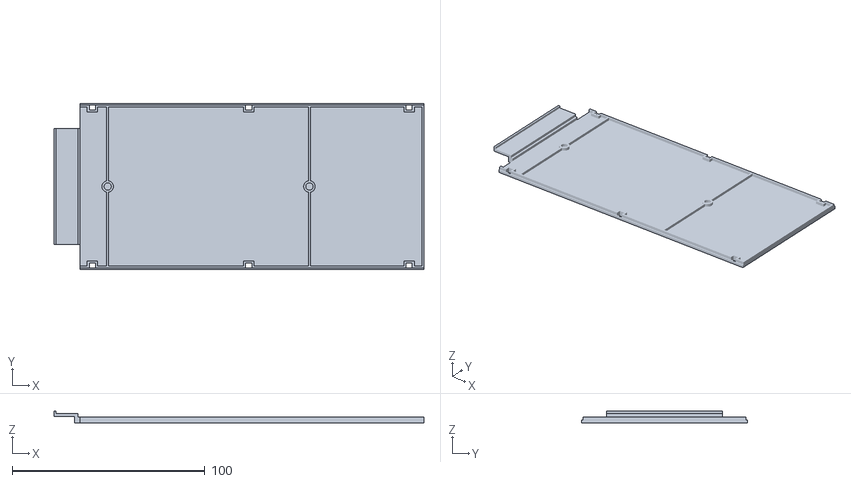
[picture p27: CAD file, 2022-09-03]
3dcase/v2/bottom.stl
192.0 x 86.2 x 6.40

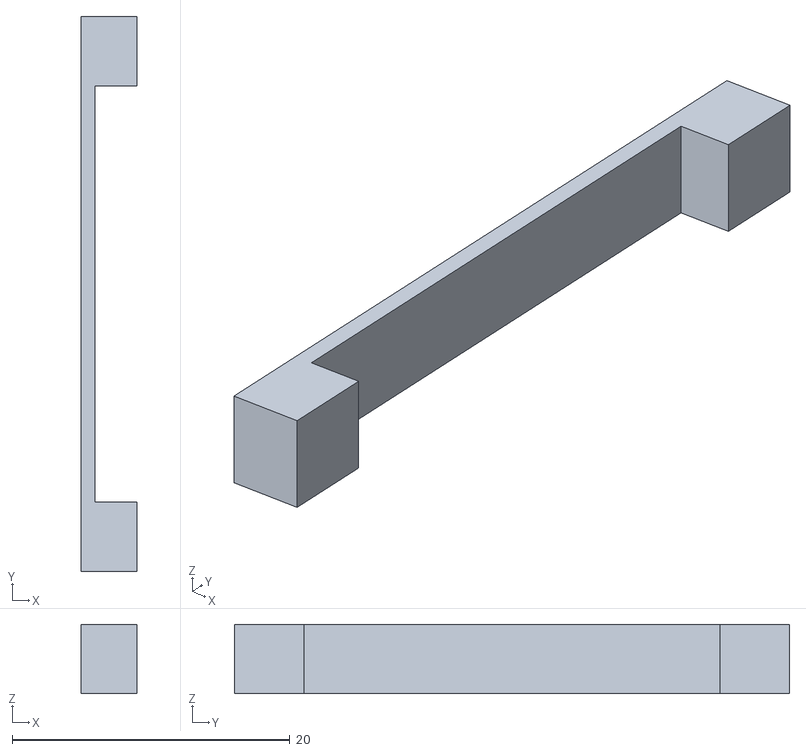
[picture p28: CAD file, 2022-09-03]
3dcase/v2/screen holder.stl
4.00 x 40.0 x 5.00

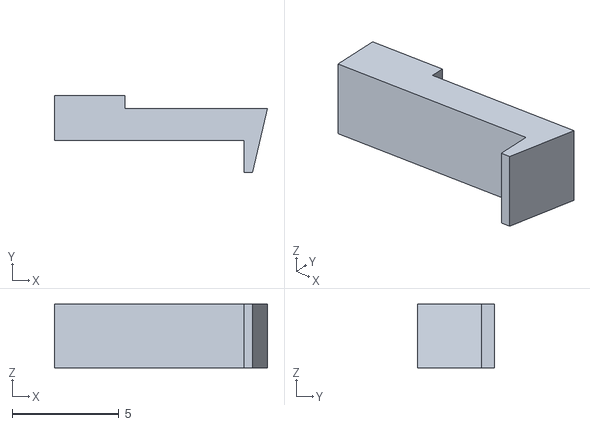
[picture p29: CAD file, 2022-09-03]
3dcase/v2/pole.stl
10.0 x 3.60 x 3.00

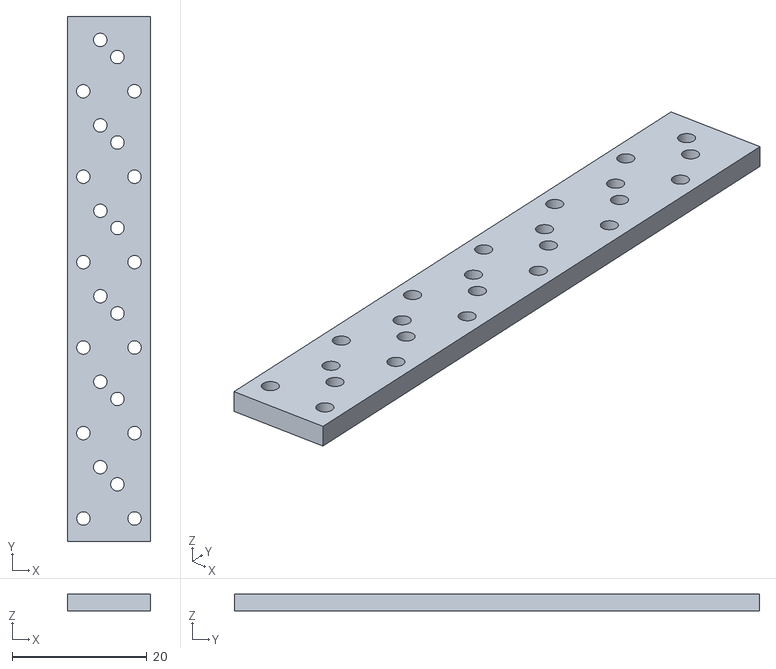
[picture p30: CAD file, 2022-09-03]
3dcase/v2/buttons_support.stl
12.4 x 78.0 x 2.50

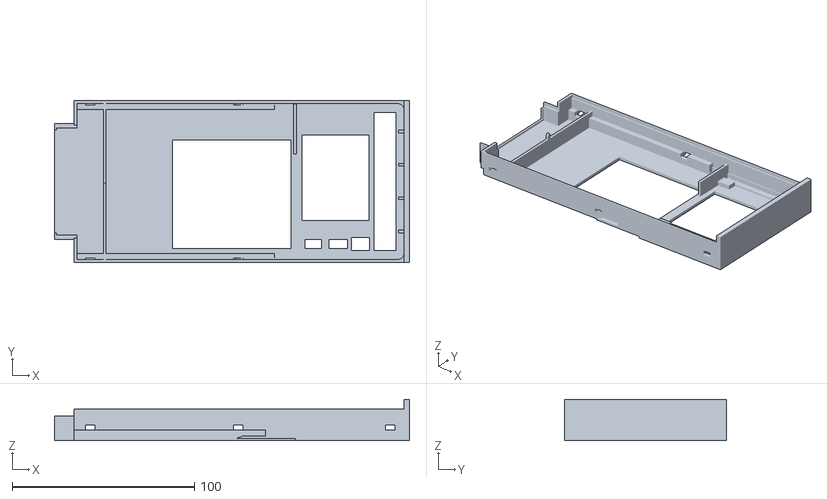
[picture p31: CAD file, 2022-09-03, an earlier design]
3dcase/v1/top.stl
194.6 x 89.0 x 22.7

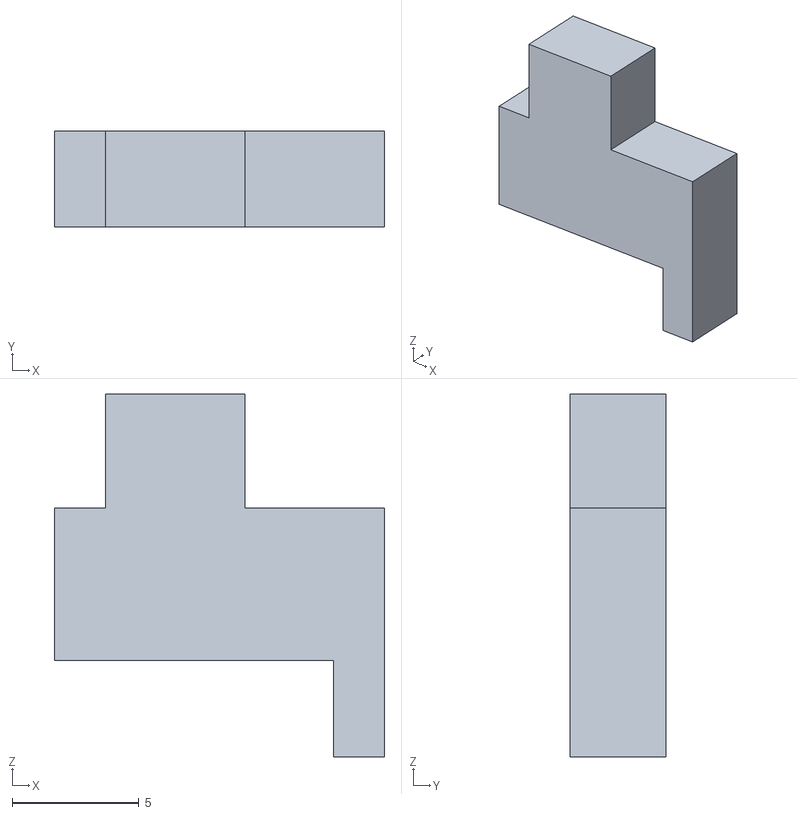
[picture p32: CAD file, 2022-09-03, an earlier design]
3dcase/v1/switch.stl
13.0 x 3.80 x 14.3

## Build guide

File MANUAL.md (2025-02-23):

# Elfacun Chess Interface Module

Elfacun

## Operation manual

### Table of contents:

1. [Powering the module](#powering-the-module)
2. [Startup and modes of Operation](#startup-and-modes-of-operation)
3. [Configure the module](#configure-the-module)
4. [Piece preparation](#piece-preparation)
5. [Piece programming](#piece-programming)
6. [Setting up the board](#setting-up-the-board)
7. [Play with Reversed board](#play-with-reversed-board)
8. [Moving pieces](#moving-pieces)
9. [Promotion](#promotion)
10. [Take back movements](#take-back-movements)
11. [Using with a DGT 3000 clock](#using-with-a-dgt-3000-clock)
12. [Lichess mode](#lichess-mode)
13. [Using Elfacun with Picochess](#using-elfacun-with-picochess)
14. [Connecting via USB](#connecting-via-usb)
15. [Connecting via Bluetooth](#connecting-via-bluetooth)
16. [Connecting via BLE](#connecting-via-ble)
17. [Adjusting buzzer volume](#adjusting-buzzer-volume)
18. [Update Elfacun Software](#update-elfacun-software)
19. [Using Elfacun with Graham O'Neill drivers](#using-elfacun-with-graham-oneill-drivers)
20. [Force passive mode](force-passive-mode)
21. [Hold mode](#hold-mode)
22. [Adjust BLE power](#adjust-ble-power)
23. [Adjust sound tones](#adjust-sound-tones)
24. [On-screen led indications](#on-screen-led-indications)
25. [Chessnut mode](#chessnut-mode)
26. [Scally homage screen](#scally-homage-screen)
27. [Chess 960 mode](#chess-960-mode)
28. [Dual leds mode](#dual-leds-mode)
29. [Adjust screen brightness](#adjust-screen-brightness)
30. [Enable or disable power from board](#enable-or-disable-power-from-board)

### Powering the module

Once inserted into the board, there are two major possible configurations to power the module:

In __standalone mode__, you will have only Elfacun plugged into the board. You need to __power the module from its USB port__, regarless of if you are connecting an app via USB or you aren't. The module can be powered from a computer USB port as well as from a regular USB wall adapter. You can also have the board powered if you want to, but power from the board won't be used by the module.

In __passive mode__ you will have Elfacun plugged alongside an original module. In that situation you will need __both, power from Elfacun USB port and powering the board__ as you would regulary do to operate the original module. Be sure that you start the original module before you start Elfacun, because it will need to detect that the original module is operating to be able to enter in this special mode. If you start Elfacun before starting the original module, both will be trying to scan the board at the same time and neither will work properly.

There are some Mephisto boards (identified as type 4b in the schach-computer.info wiki) that aren't voltage-regulated and put the full wall adapter voltage into the modules. I don't recommend using Elfacun with those boards powered, as it will have to support an unknown voltage and cannot be guaranteed to work or not to be damaged. More information about the boards power supplies can be found here: [https://www.schach-computer.info/wiki/index.php?title=Stromversorgung_Mephisto_Modulare_Reihe](https://www.schach-computer.info/wiki/index.php?title=Stromversorgung_Mephisto_Modulare_Reihe)

### Startup and modes of Operation

The module can be started in three different modes:

* __Mode A__, compatible with most apps (except Millennium-compatible apps via USB)
* __Mode B__, compatible with most __Millennium-compatible__ apps, including USB
* __Lichess mode__

The main difference between modes A and B is that in mode A the serial port is initialized to 9600 bauds, while in mode B it is initialized to 38400 bauds. If you are using the module with Bluetooth or BLE, all the apps should work the same on mode A, as the appropiate protocol will be automatically detected.

So it is recommended to start the module on mode A unless you want to use __Millennium-compatible apps via USB__, in wich case mode B is mandatory.

The default mode can be changed by the user (see "Configuration"). If you want to boot the module in a non-default mode you can make so by __keeping pressed while starting__ one or more of the module buttons:

* Keep pressed __first button__: Start in __mode A__
* Keep pressed __second button__: Start in __mode B__
* Keep pressed __third button__: Start in __Lichess mode__

Additionally you can keep pressed the following buttons to modify sound and LED operation

* Keep pressed __fifth button__: Start with __board LEDs disabled__
* Keep pressed __sixth button__: Start with __sound disabled__

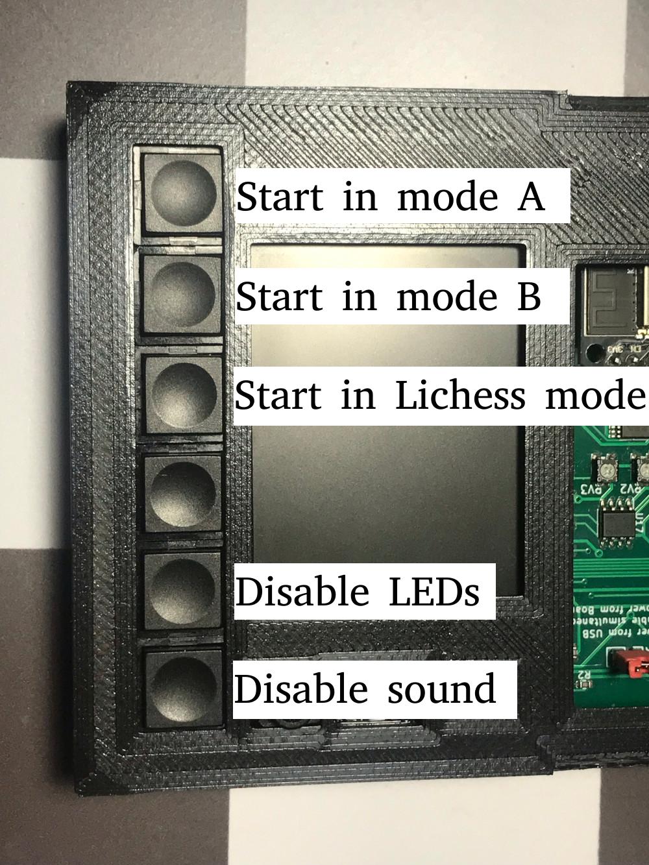
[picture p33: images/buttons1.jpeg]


### Configure the module

You can make permanent changes to the module configuration by editing a [settings.txt](./settings.txt) text file, putting it into the SD card and starting the module with the card inserted. When started, the values from the file will be permanently stored in the module.

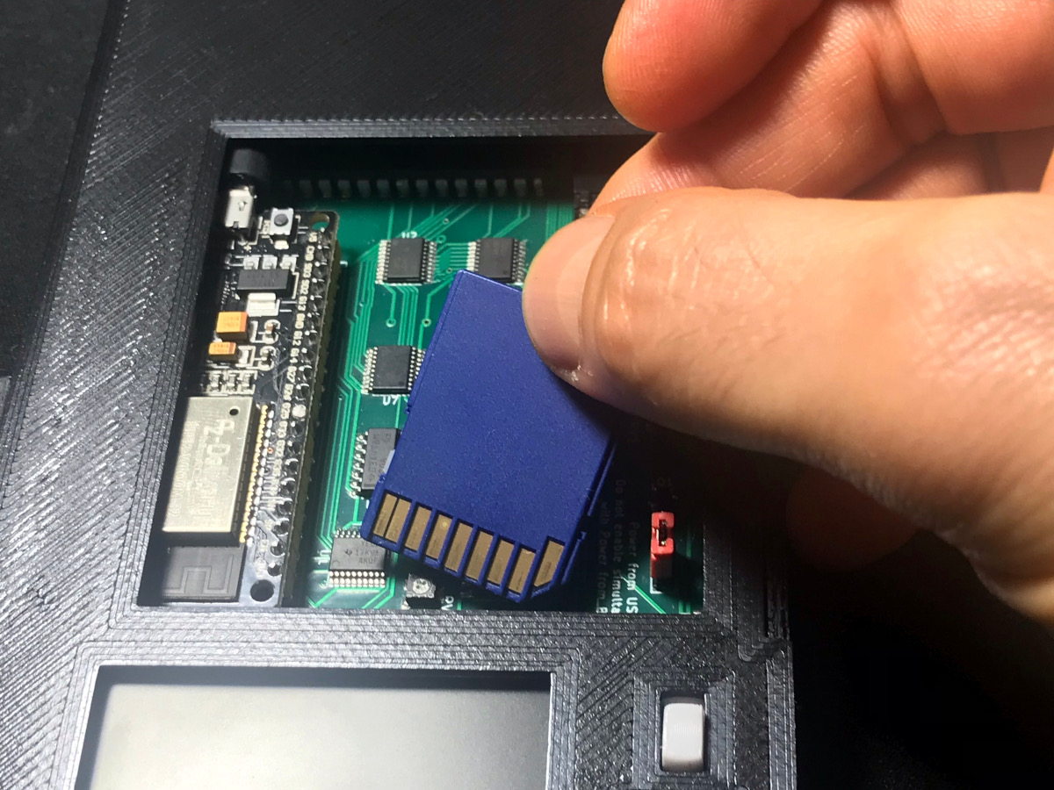
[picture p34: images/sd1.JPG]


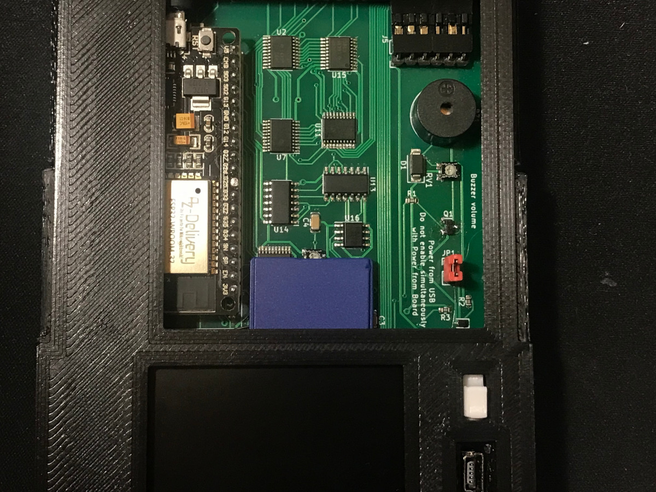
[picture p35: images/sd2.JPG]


__The piece scanning won't work while the SD card is inserted, so please remove the card after successfully configuring the module.__

A minimal configuration is needed if you want to use Lichess mode, that is your WIFI ssid and credentials, and your Lichess API token.

The values you can edit in that file are:

* __base.mac.address__: If you want to change the hardware address of the module
* __mode.default__: default mode
* __mode.a.bt.advertised.name__: The name you will see when pairing the module via Bluetooth in mode A
* __mode.b.bt.advertised.name__: The name you will see when pairing the module via Bluetooth in mode B
* __buzzer.enabled__: Enable or disable sound by default
* __leds.enabled__: Enable or disable the board LEDs by default

Some parameters that modify how Elfacun identifies itself in mode A. Usually you won't need to change this:

* __mode.a.trademark__
* __mode.a.version.major__
* __mode.a.version.minor__
* __mode.a.clock.version.major__
* __mode.a.clock.version.minor__
* __mode.a.serial.number.long__
* __mode.a.serial.number.short__

Settings needed for Lichess mode, see Lichess Mode manual section for more information

* __lichess.wifi.ssid__
* __lichess.wifi.password__
* __lichess.wifi.authtoken__
* __lichess.board.autoinvert__

Settings to customize each of the 6 pre-defined challenges for Lichess. When in Lichess.TV you can launch one of those predefined challenges using the corresponding key (the first key is the leftmost one).

* __lichess.mode.X.time__
* __lichess.mode.X.increment__
* __lichess.mode.X.color__
* __lichess.mode.X.rated__
* __lichess.mode.X.elo__

A more detailed description and a list of valid values for each parameter are included in the sample [settings.txt](./settings.txt) file

When you edit _settings.txt_, do not leave spaces between the keys, equals and values. This is OK:

    lichess.board.autoinvert=false

This is NOT OK:

     lichess.board.autoinvert = false

_While experimenting with Lichess settings, I recommend you have at hand a connected app or the session initiated on the web site, as if you launch challenges repeatedly and don't play the games, you could be temporarily banned._

### Piece preparation

This is optional and only required if you want to be able to scan your pieces with the module.

You have been provided with 50 RFID tags that can be programmed and read by the module. You need to modify your pieces to place one tag under each piece.

In case you want to buy more tags, the tag specification is __NTAG213, 18mm diameter__.

The provided tags are 18mm. wide, so they are a good fit for the Exclusive and München original pieces, but maybe a little big for the Modular pieces, specially for the pawns.

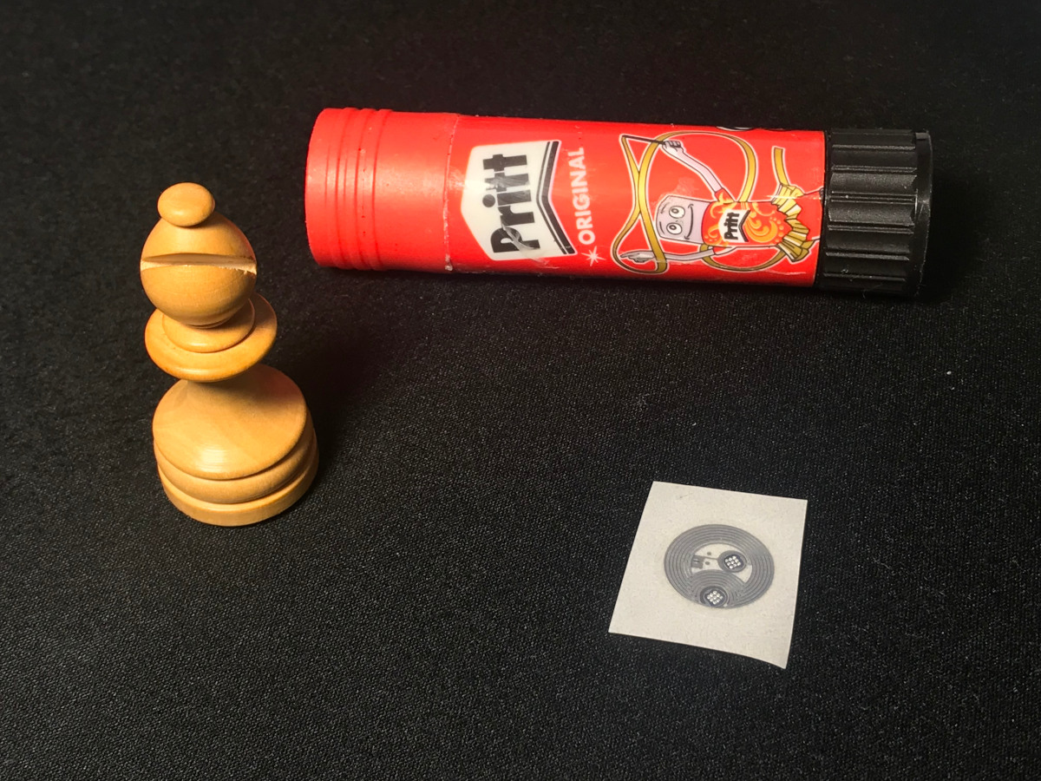
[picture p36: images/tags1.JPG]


For fitting the tags you need to remove the felt under your piece. If you are careful you will be able to glue back the same felt later. You can use something like a small flat screwdriver to gently pull the felt in little steps without shredding the felt or damaging the piece.

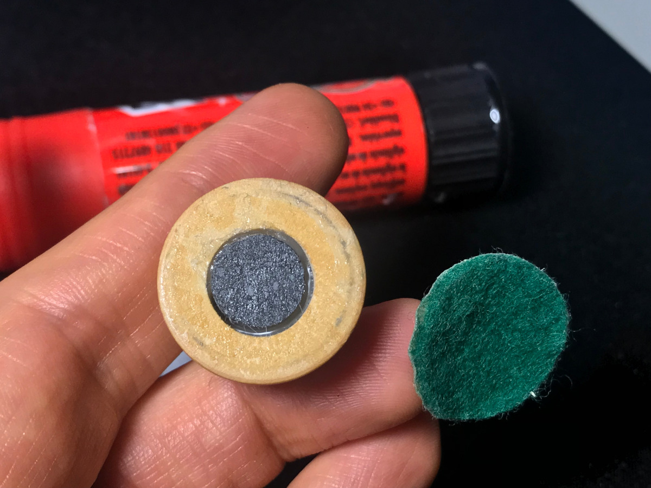
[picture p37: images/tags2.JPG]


With the felt removed, stick one tag under the piece. The tags are auto-adhesive.

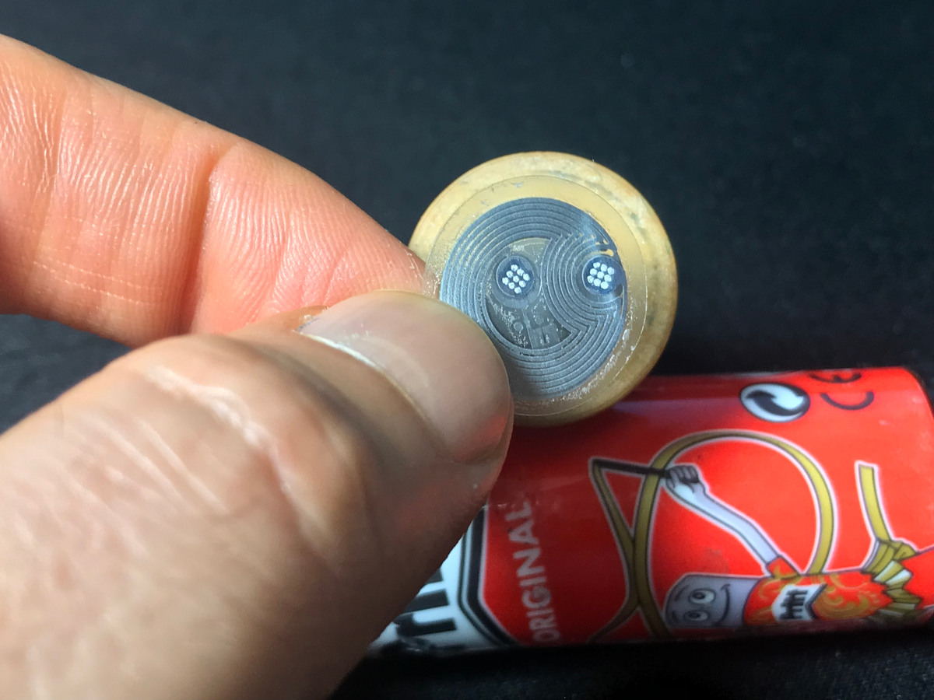
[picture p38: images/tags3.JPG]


Finally glue the felt back under your piece, and that piece is ready to be used with the module. Of course you can also replace the old felt with new felt if you want to.

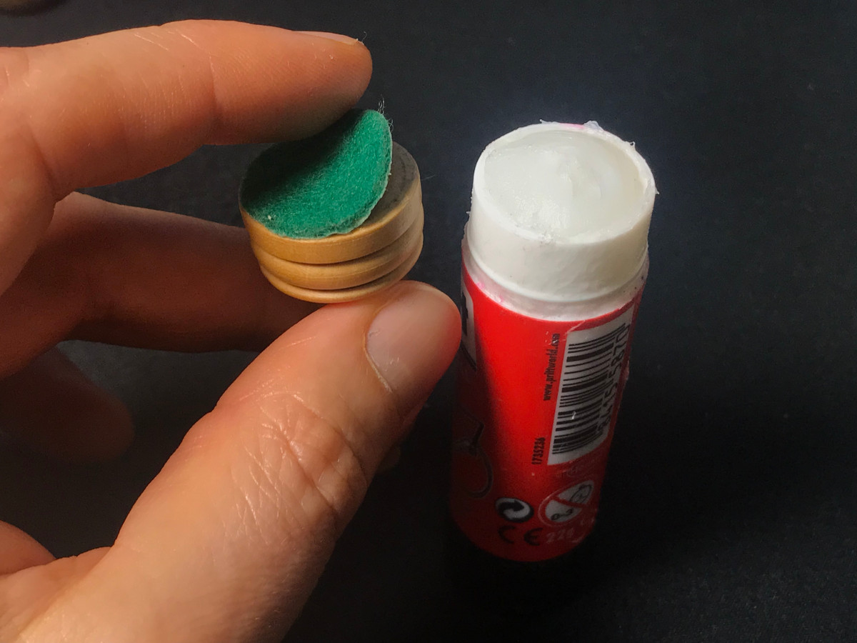
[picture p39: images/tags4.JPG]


### Piece programming

Once you pieces have been RFID-equipped, place them in the regular starting position on the board and switch on the module. Once the module is started, take one piece and place it near the module. You will hear a triple beep sound that indicates that the piece has been programmed. Place the piece back into its position and repeat the operation with the other 31 pieces.

This procedure needs to be done only once as the tags keep their programming forever, but the tags can be programmed as many times as you want.

You can test the piece programming by clearing the board, taking a piece, placing it near the module, then you will hear a single beep sound that indicates that the piece has been scanned. Then place it on the board and the correct piece should show up on the screen.

### Setting up the board

When you start the module, if the pieces are placed in the regular starting position the module will recognize them all, and you can play normally from there.

Anytime the module detects that all the 32 pieces are in the 1st,2nd,7th and 8th rows, it will assume that you are setting up the starting position and recognize all the pieces, and you can play normally from there.

Anytime the module detects that there are no pieces outside the 1st,2nd,7th and 8th rows, and you are placing more unknown pieces in the 1st,2nd,7th and 8th rows, after 4 unknown pieces have been placed it will assume that you are setting up a starting position, and the pieces will be automatically recognized from that point on.

Of course you can set-up a different position by clearing all the board, taking one piece, scanning it and placing it on the board. Repeat the operation with as many pieces as you want to set-up the complete position.

### Play with Reversed board

To play with a reversed board (play with black pieces in the first rows) place the pieces normally on the board with the black pieces in front of you. Then take the two kings off the board and place them back. The board will then be reversed and that will be shown on the screen, and you can play normally from there.

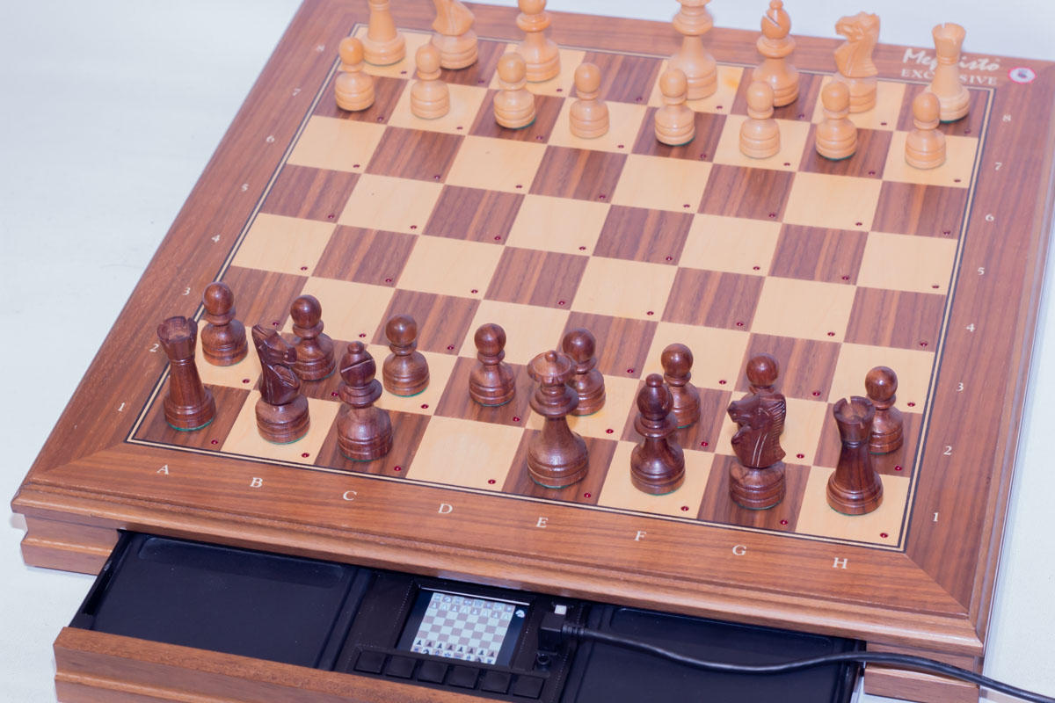
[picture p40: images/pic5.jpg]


### Moving pieces

Try to place the pieces as centered as possible in its squares. This is a general requirement for Mephisto boards.

The module will make a beep sound everytime you lift a piece and everytime you place a piece. If you play logical movements it will always identify correctly the piece at its destination square and show it accordingly on the screen.

Piece slide is not recommended at this point, you should always lift and place the pieces you move. Future updates could allow or improve piece sliding support.

For taking pieces it is irrelevant if you lift first the taking or the taken piece, it will work both ways.

### Promotion

When promoting a pawn to a queen, advance the pawn to the last row and then take it off the board and place the queen (or any other piece that will act as a queen) in its place.

When promoting a pawn to a piece diffent than a queen, advance the pawn to the last row and then take it off the board. Then you need to scan with the module the piece you want to promote to. Take that piece and place it on the module, you will hear a beep sound to indicate that it has been scanned. Then place it on the board in the appropiate square.

When promoting a pawn to a piece diffent than a queen in a situation where you don't hava a piece to scan (for example, to promote to a knight when you already have your two knights on the board) you can temporary take a similar piece to scan (in the example one of your knights), scan it, place it back and then place any other piece instead of the promoted pawn. That other piece will act as the desired piece.

### Take back movements

The module will detect all the played movements and you will be able to take them back. When taking back a capture, complete first the back movement and then place the taken piece back. The taken piece will appear on the screen when you complete then back movement to indicate it has to be placed on the board. Be careful not to misplay any back movement, as the module may lose track of the movements in that case.

### Using with a DGT 3000 clock

You can use a DGT-3000 clock with DGT-compatible apps like Picochess. With Elfacun turned off connect the clock to the module using a stereo mini-jack to mini-jack cable. Shorter cables are recommended as the I2C signal will not work with longer cables. Someting like a 50cm cable will work. Someting like a 2m cable won't work. Something in between may or may not work.

When you turn on the module, the clock will be automatically detected and used with the apps.

To indicate the correct clock orientation, the clock lever should be up at white's side at module startup. This cannot be changed when the module is already started. If you play with a [reversed position](#play-with-reversed-board) the clock times will be automatically switched to the right side.

The clock buttons will be functional, as well as the module buttons emulating the clock buttons.

The first 5 module buttons (stating on the leftmost) emulate the 5 DGT-3000 front buttons. The sixth module button emulates the clock lever (changes the lever position with every button press).

If you don't plug a real DGT-3000 clock, the module will emulate one while in mode A. The module buttons will be fully operational and messages and times will be shown on the screen.

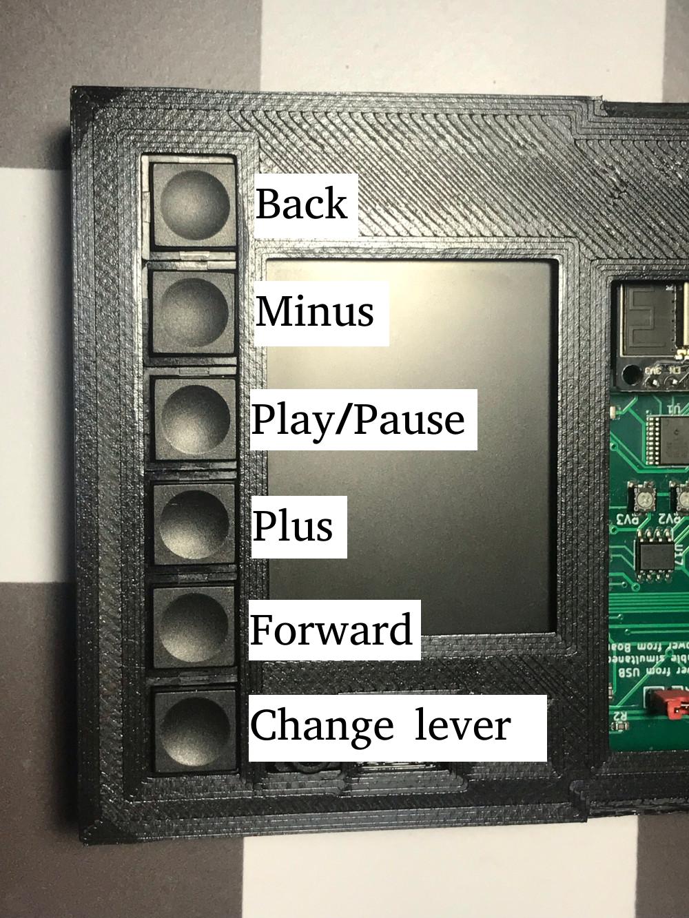
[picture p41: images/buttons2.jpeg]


### Lichess mode

To use Lichess mode you will need to generate an authentication token in the website.

Log into lichess.org and enter into your "preferences" menu option:

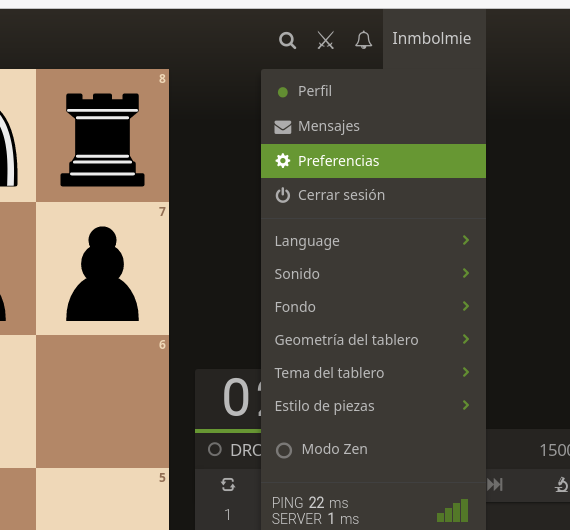
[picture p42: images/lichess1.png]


On the side menu select "API access tokens"



Click on "generate a personal access token"

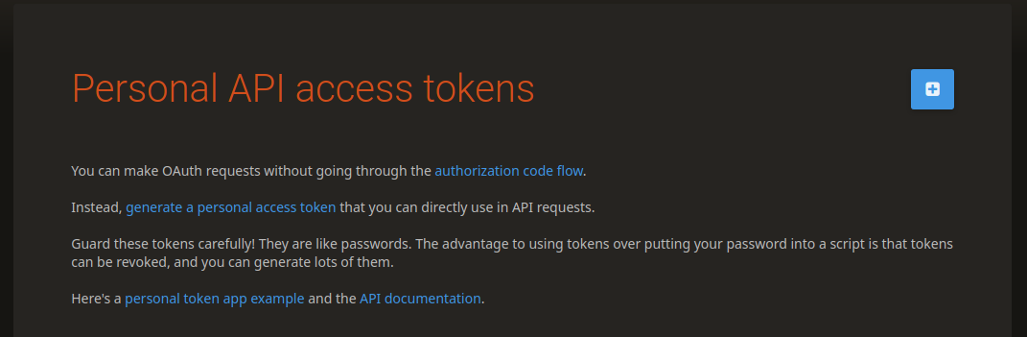
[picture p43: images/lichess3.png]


Give the token access to the following features:

* Read preferences
* Read incoming challenges
* Create, accept, decline challenges
* Play Games with the board API

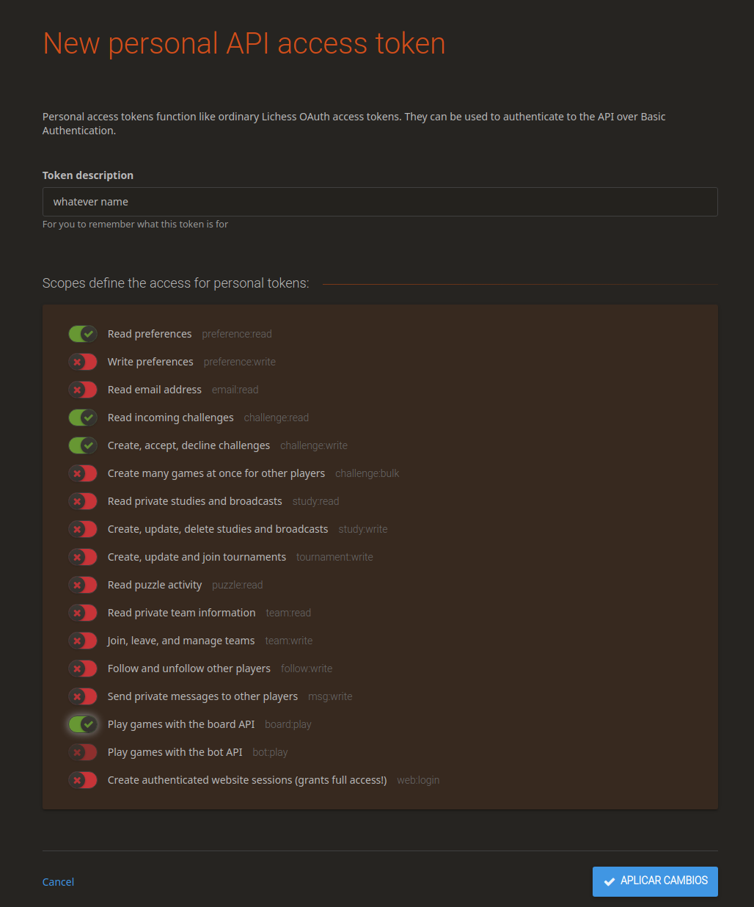
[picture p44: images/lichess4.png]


Press "apply" and now you have generated your access token, that you will have to copy into Elfacun configuration. Make sure you write it down somewhere as you won't be able to see it again on the website.

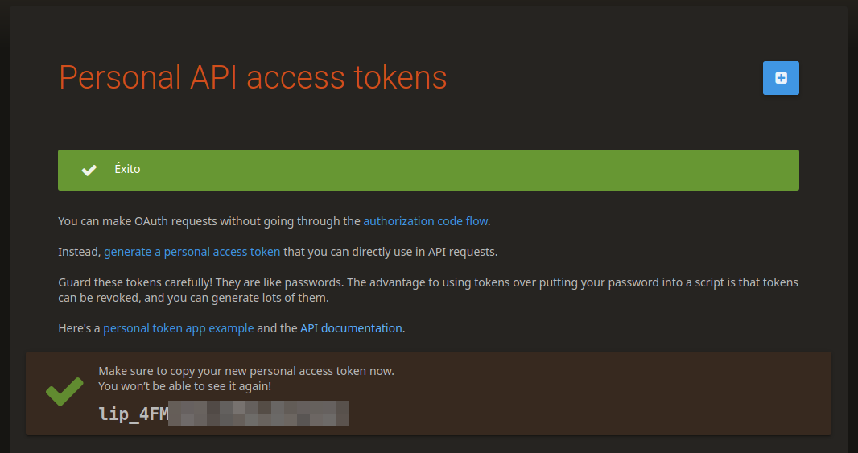
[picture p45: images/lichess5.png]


Now that you have a token, you will have to configure it [using the _settings.txt_ file in a SD card](###Configure-the-module). The mandatory parameters for Lichess mode are:

* __lichess.wifi.ssid__: Your WIFI ssid
* __lichess.wifi.password__: Your WIFI password
* __lichess.wifi.authtoken__: Authentication token generated from your lichess.org account
* __lichess.board.autoinvert__: If board will be automatically inverted when you play as black

After configuring that parameters, when starting in Lichess mode, the module will automatically connect and start streaming Lichess.tv games. The stream will continue until a new game is detected. A new game can be started by:

* Starting a game outside the module, for example on the web or in a mobile app.
* Launching a challenge from the module.

You can launch a challenge from LichessTV pressing twice one of the six module buttons. Every button represents one play mode that can be configured by the user via _settings.txt_ and SD card.

Only "rapid" and "classic" games are supported on the Lichess board interface. The "blitz", "bullet" or "correspondence" games cannot be played on Elfacun and won't be shown on the module, even if you start a game on another interface. Also only the "standard" chess games are supported.

For example, to configure the first button to lauch a rated 10+0 game as random colour you will configure in _settings.txt_:

    lichess.mode.X.time=10
    lichess.mode.X.increment=0
    lichess.mode.X.color=random
    lichess.mode.X.rated=true

__Note that after September 2024, non-random coloured challenges are no longer supported by Lichess, so if you configure a non-random coloured challenge it will be launched as a random-coloured one.__

If you pressed one button but don't want to launch the challenge, simply press a different button to cancel.

After the challenge is launched, if is successfully paired the game will be automatically detected and started.

While in a game, you can control with the module buttons some actions:

* __Fourth button__: Ask the opponent for __taking back__ the last movement.
* __Fifth button__: Offer draw to the opponent.
* __Sixth button__: __Resign__.

You need to push the button twice for the action to be effective.

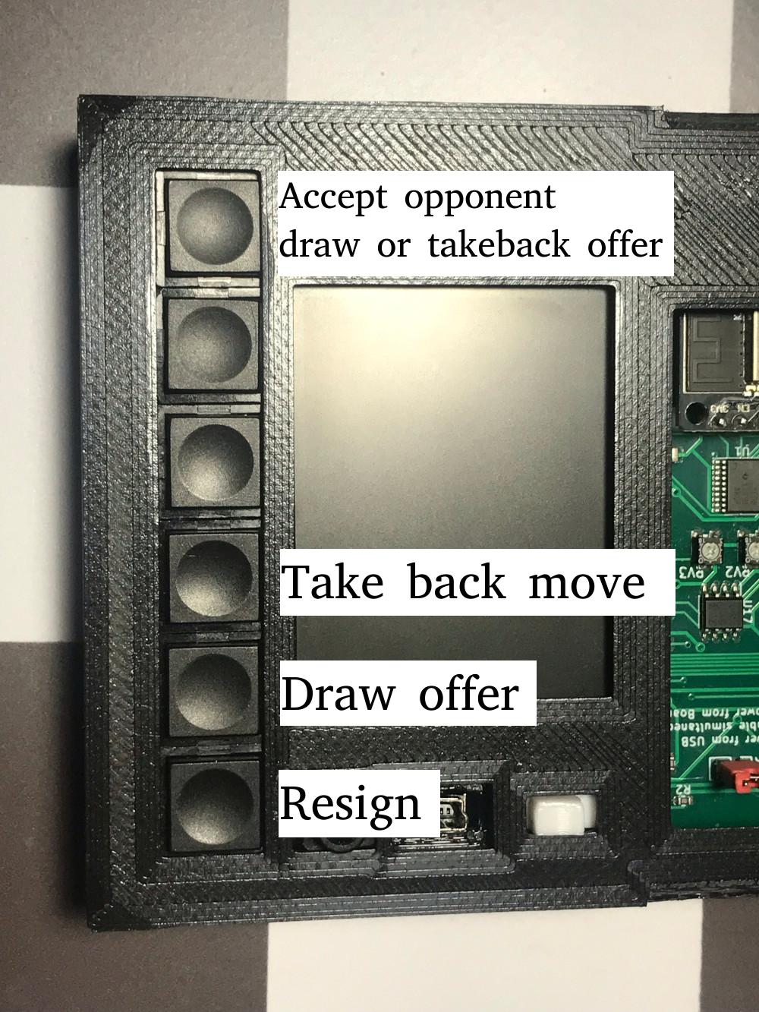
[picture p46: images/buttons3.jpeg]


The opponent draw and takeback offers will be shown on the screen as well. You can accept them using the first button or decline it with any other button or making a piece movement.

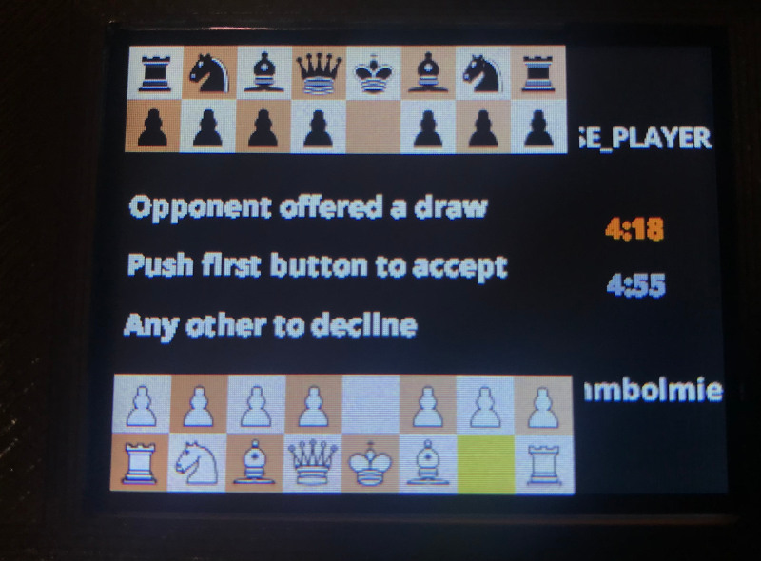
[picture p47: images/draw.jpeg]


When a game ends, the module will show the result and LichessTV mode will automatically start again. You have to reach the final position for that to happen or press any module button after the game result has been shown.

While experimenting with Lichess settings, I recommend you have at hand a connected app or the session initiated on the web site, as if you launch challenges repeatedly and don't play the games, you could be temporarily banned. Also if you want to accept or offer a rematch you won't have time to set-up the board and make the first movement before the game is cancelled, so in that case you have to make the first move on the other interface and then you can set-up the board with that position that will be indicated on the screen.

On Lichess mode there is no "piece recognition" as such. The pieces simply have to be in the same positions that the screen shows, that is the position on Lichess servers.

The LEDs will flash:

* To indicate an incoming movement (origin square, destination square)
* When a piece is on a square that should be empty
* When no piece is on a square that should be occupied

On Lichess mode your movements are not instantly reflected on the screen because the screen is updated only after the new position is received from Lichess and the confirmed position received back by the module. A good WIFI signal strength is recommended to make this process faster.

Note that sometimes if you make a valid move, even if the rest of the position is bad on the board, the move will be accepted and made on Lichess. Afterwards the true position on Lichess will be reflected on the screen, as the screen has to show what is on Lichess servers. So it is important while on Lichess mode to be careful moving your pieces and the opponent pieces as you are playing against humans and all the moves you make are definitive.

**Promotion and underpromotion**

About promotion in Lichess by default when you put the pawn in the eight rank the module will assume that you want to promote it to a queen. If you want to underprote it to a different piece, you have to scan with the module the piece you want to promote to before placing the piece on the last rank. __It is important to remember that you have to scan the piece BEFORE placing it on the last rank, and do not place the pawn__, just place the piece instead of the pawn. Once placed, if you haven't scanned the piece beforehand, the module will assume that you want to promote a queen and will be too late to change your mind as the movement will be already sent.

To scan the destination piece, you actually can use a piece of the other colour. So for example, to promote to a white knight you can scan a white knight as well as a black knight if you want to.

**On-screen Wifi signal quality indicator**

It is vital for the module to operate properly to have proper Wifi signal strength. This is a particular device in the sense that the Wifi antenna is located very inconveniently, as it lies flat inside the module that is inserted in the board under a very thick chessboard PCB that blocks part of the signal coming from and going to the Wifi access point. So in general you can expect a much lower range for the module than you can get on other devices like your mobile phone and so.

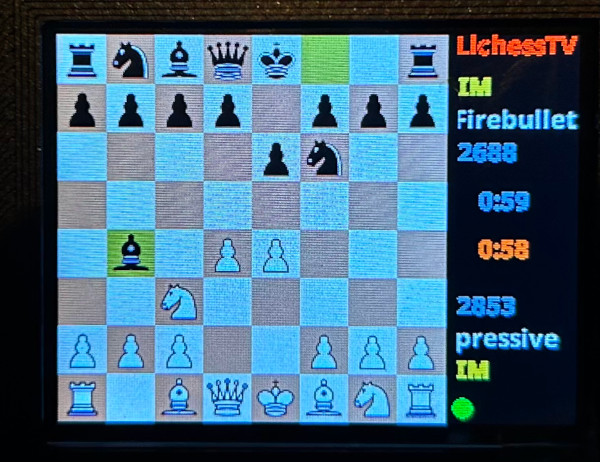
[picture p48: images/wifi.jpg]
wifi quality


So to have good feedback about the signal quality the module is experiencing I have added an on-screen signal quality indicator when on Lichess mode. It is a coloured dot next to the lower part of the board picture:

- Green dot indicates good signal
- Orange dot indicates weak signal
- Red dot indicated bad or intermittent signal

This way you will be able to distinguish if an issue is just a signal quality issue and you just have to be closer to your access point, or if it is something else:

You objective should be to get a green most of the time, mostly green with some orange will be OK
Mostly orange means you may have issues, the module can operate slower than ideal.
If you see red, you most likely will have problems. If you can’t get closer to the access point you should consider switching to an external app like White Pawn, or installing a Wifi repeater in the room where you have the board.

**Automatic recovery of Lichess games**

In the event of power loss or module reboot while on a Lichess game, the module will automatically start on Lichess mode and reconnect to continue the game where it was, no need to press any button. You still can force it to boot on another mode by pressing the buttons if you want to.

### Using Elfacun with Picochess

We will show how Picochess can be configured to connect to Elfacun using Bluetooth. A Raspberry pi 3B+ or 4 is recommended for running Picochess. Of course you can also connect Elfacun to picochess using USB.

For this test an image of Picochess V3 on a Raspberry PI 3B+ has been used.

[https://groups.google.com/g/picochess/c/jCuWSm0EDH8?pli=1](https://groups.google.com/g/picochess/c/jCuWSm0EDH8?pli=1)

You will need access to a Picochess command line, you can get it on its desktop, or remotely via VNC or SSH.

First you need to know the module MAC address. With Elfacun started in mode A, open a console in Picochess and execute the following command:

    sudo hcitool -i hci0 lescan

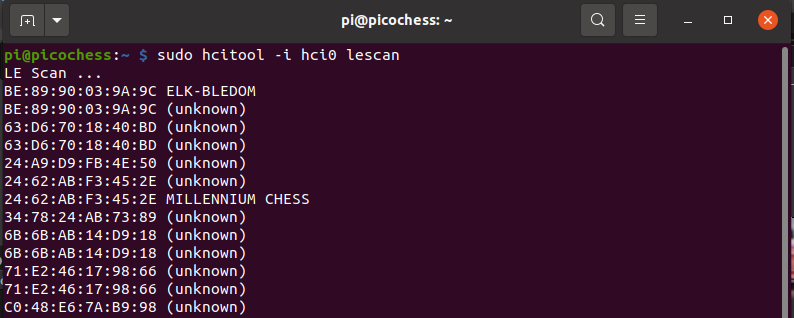
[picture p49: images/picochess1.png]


Here you see that Elfacun MAC address is 24:62:AB:F3:45:2E. The address will be different on each Elfacun module.

Into the same console execute the following command where you need to indicate your module MAC address.

    sudo rfcomm bind 0 XX:XX:XX:XX:XX:XX

For example if your module MAC were 11:22:33:44:55:66 you would need to execute:

    sudo rfcomm bind 0 11:22:33:44:55:66

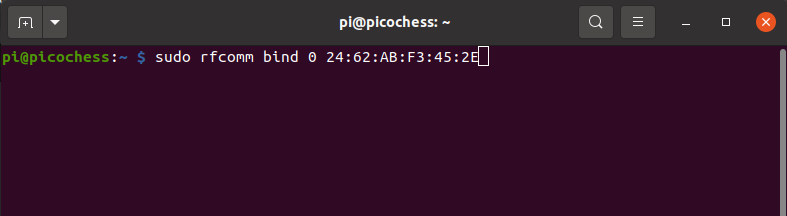
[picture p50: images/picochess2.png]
    

And now Picochess should detect the module, if it isn't, restart picochess

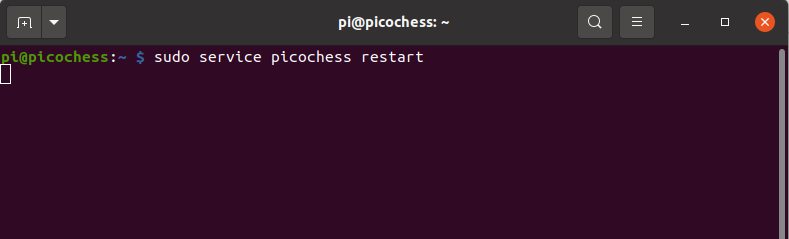
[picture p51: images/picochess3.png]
  

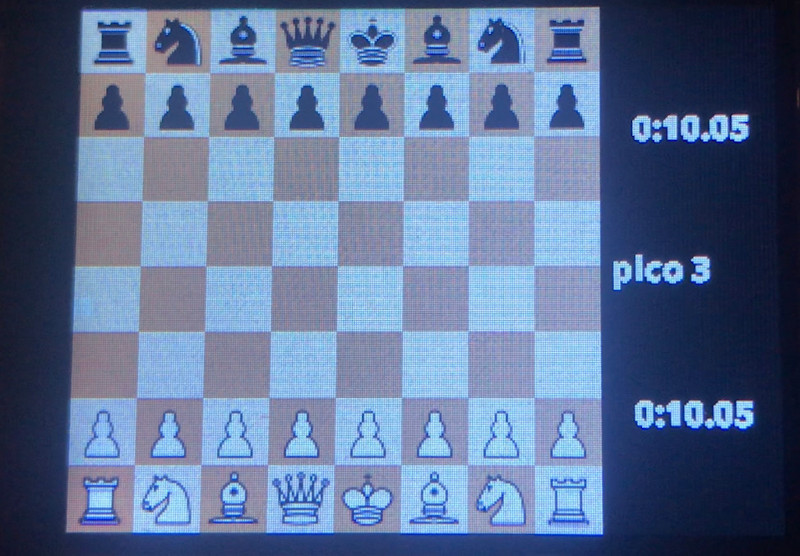
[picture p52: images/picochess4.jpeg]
  

If you want Revelation-II leds to be enabled you need to make a small code modification in Picochess.

Open a text editor with _vi_ or the text editor of your choice and edit this file:

    /opt/picochess/dgt/board.py

You need to modify this line so that self.is_revelation = True and self.is_pi = True

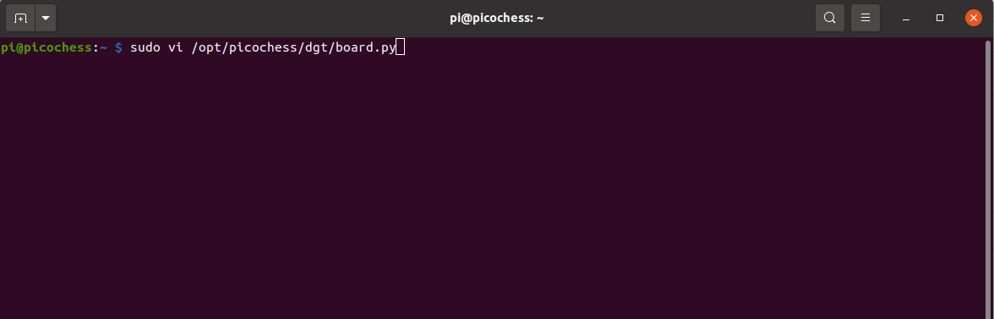
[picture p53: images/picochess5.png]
  

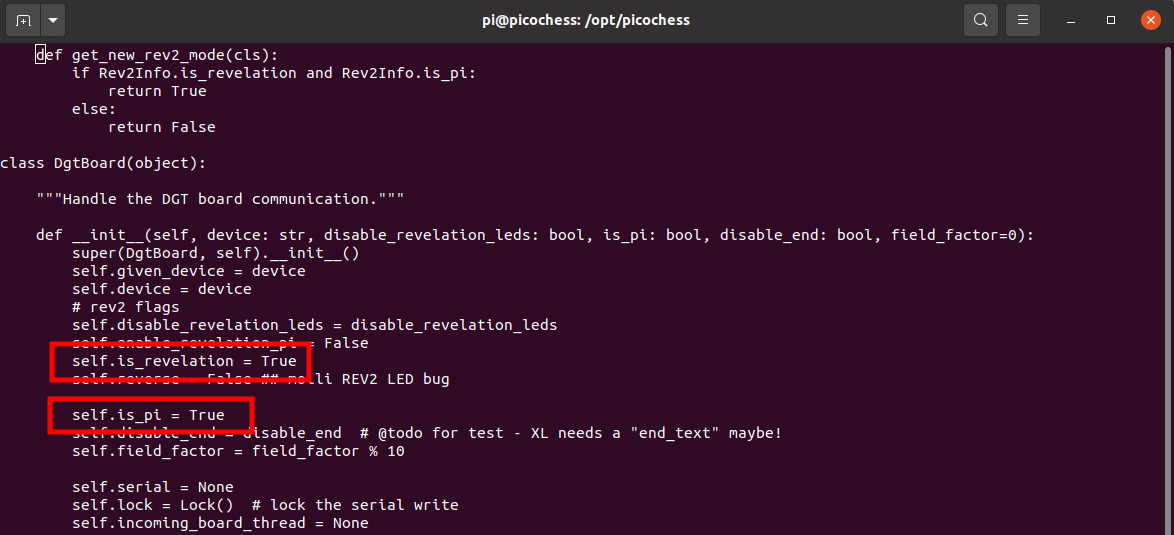
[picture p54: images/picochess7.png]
  

Once modified, save the file and restart Picochess, and now Revelation II LED support should be enabled and the computer movements will be indicated on the board.

### Connecting via USB

No special configuration is needed. Simply start the module in mode A or B depending on the protocol you want to use.

On windows machines you may need to install the USB-to-serial driver for the ESP32. If so, follow the instructions here to install it: [https://docs.espressif.com/projects/esp-idf/en/latest/esp32/get-started/establish-serial-connection.html](https://docs.espressif.com/projects/esp-idf/en/latest/esp32/get-started/establish-serial-connection.html). For the ESP32 boards I've been using so far, the relevant driver is the CP210x driver.

### Connecting via Bluetooth

We will show an example of how to configure a Bluetooth connection in LucasChess Windows. The configuration for Rabbitplugin or other programs should be similar.

Open the Bluetooth configuration and push the button to add a new device. Start Elfacun in mode A.

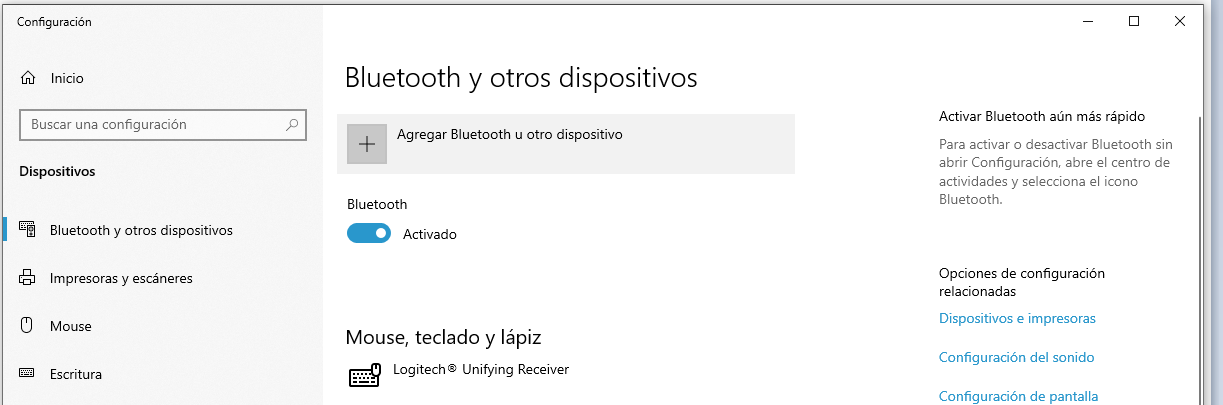
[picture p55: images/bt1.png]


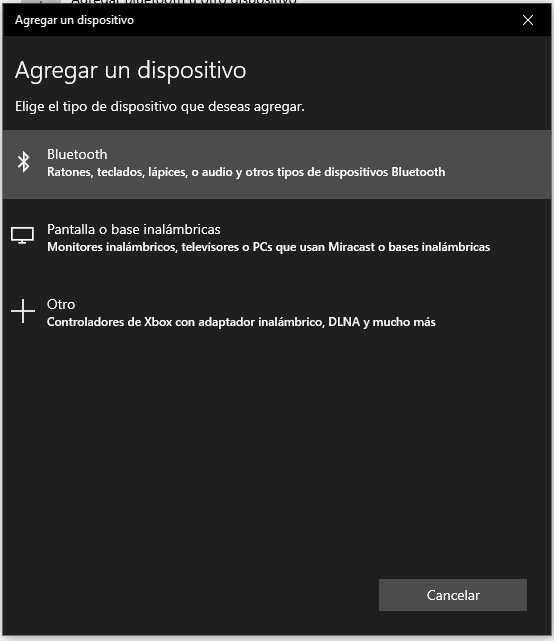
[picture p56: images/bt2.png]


The module should appear on the list of detected devices. If more than one device appears it should be that one marked with a "computer" icon

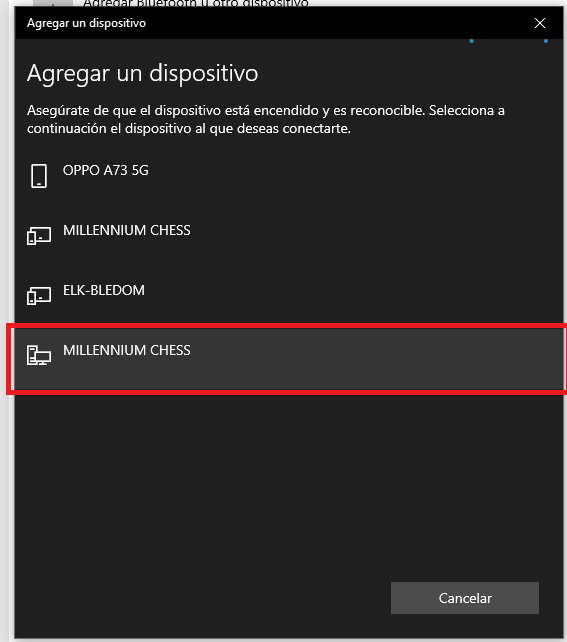
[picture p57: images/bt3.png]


Push the device to add it.

Now that the module has been paired, a couple of serial ports should have appeared in the device manager under "COM and LPT ports" section. One of those ports is the port you have to indicate in the driver configuration.

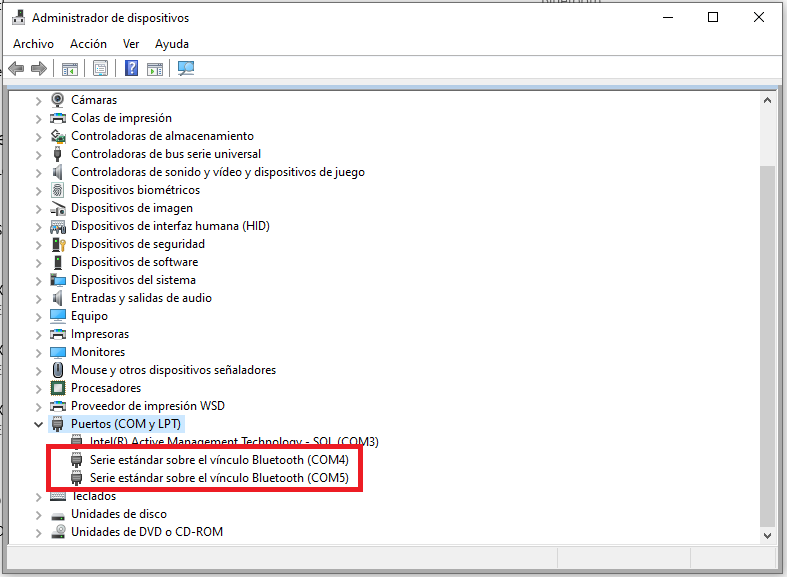
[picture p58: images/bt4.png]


Once we have configured the port in LuchasChess it detects the module and it is ready to go.

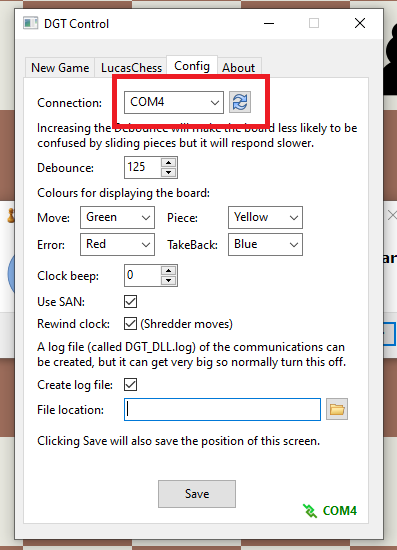
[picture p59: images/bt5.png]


### Connecting via BLE

Using Elfacun with BLE connectivity cannot be easier. Just turn on the module in mode A or mode B and the module will be detected by any compatible application. Be warned that some applications expect the module to identify with a specific Bluetooth name. The name that the device uses to identify itself can be configured by the user.

### Adjusting buzzer volume

The buzzer volume can be modified adjusting the variable resistor RV1. It can also be entirely turned off via configuration. The resistor is a little tricky to adjust as it is very sensitive, so it can be difficult to get it to the desired volume.

### Update Elfacun Software

You can update the module software putting an update file into an SD card, inserting the SD into the module and turning the module on.

It is recommended that the module is not inserted into the board for the update, you only need to power it up from the USB cable.

__Make sure the SD card you are using is NOT write-protected__.

Download the update file and place it in the root directory of the SD card. The update file name will be something like _update_0x6ee0d617.bin_. Make sure you download the file in its entirety.

Insert the SD card into its slot behind the module screen with the contacts facing upwards like this:

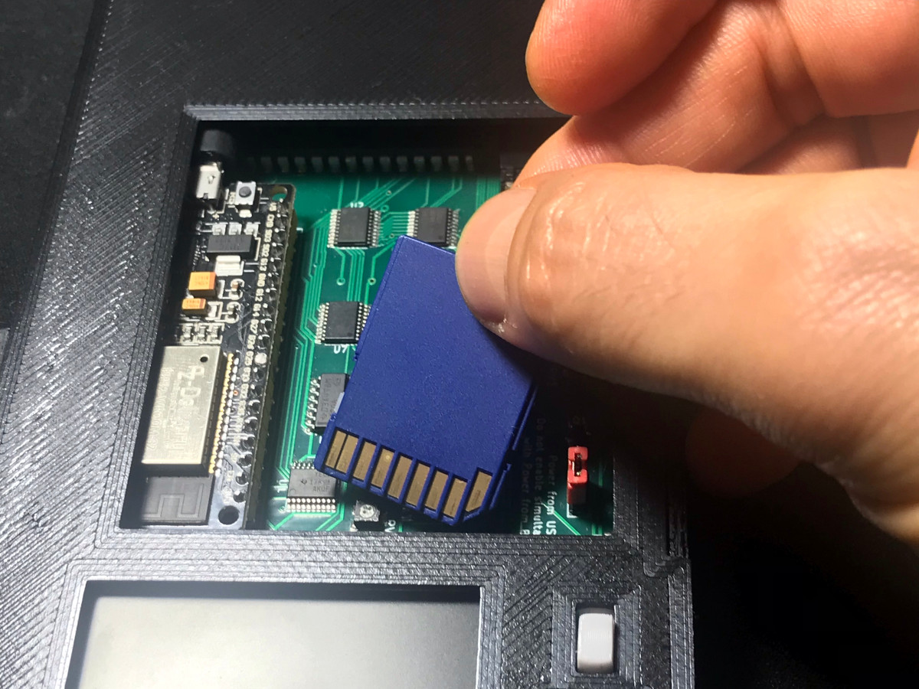
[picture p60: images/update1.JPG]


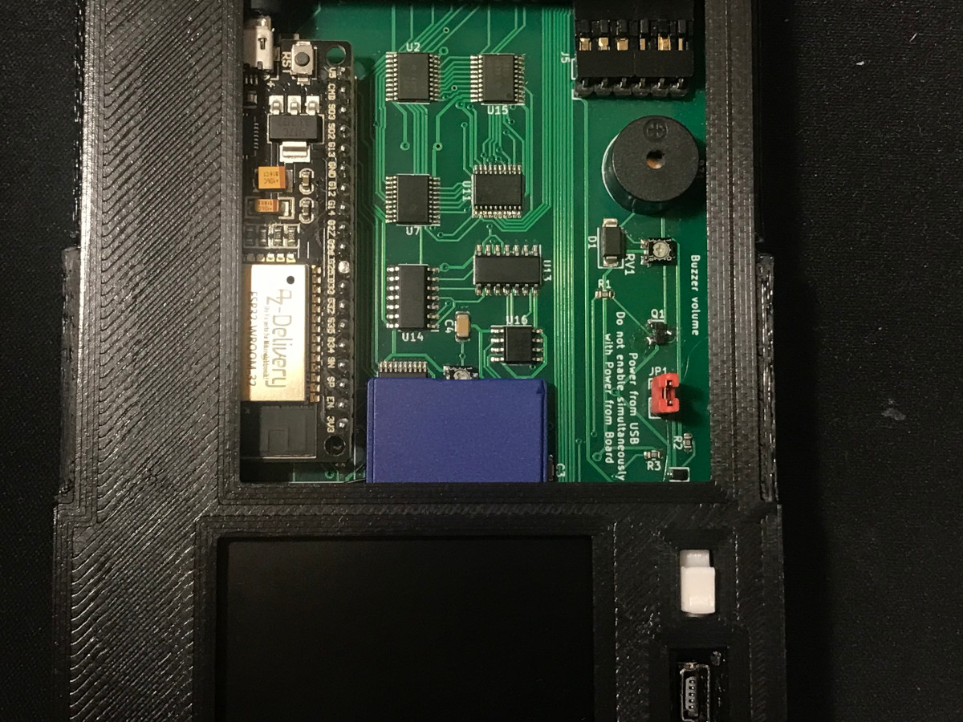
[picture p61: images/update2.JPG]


Plug the USB cable and turn the module on, if the module finds an update file into the SD card it will check it for integrity. If the integrity check failes make sure you download the correct file in its entirety. The checking process will take some time.

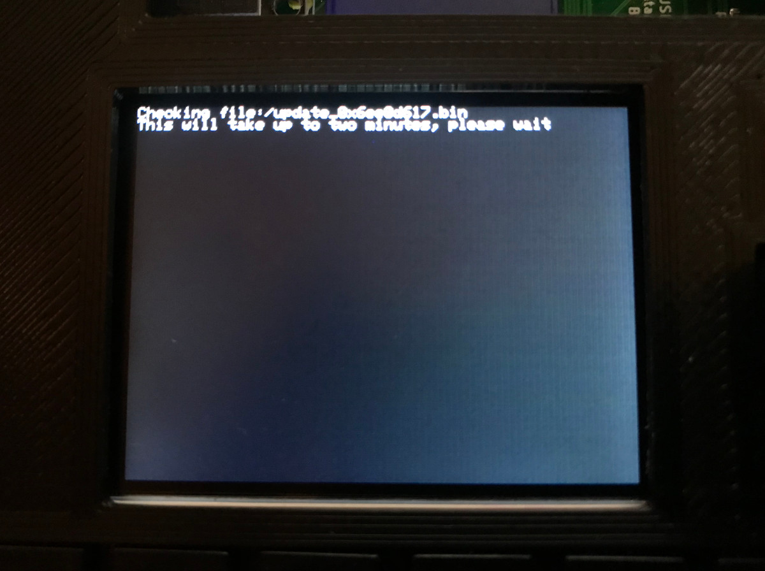
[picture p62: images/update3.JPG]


If the update file is correct, you will be prompted to confirm the update. To do so press __simultaneously__ the two leftmost module buttons. The update process will begin.

__While updating please, do not turn off the module or remove its power, as you can brick the module doing so__.

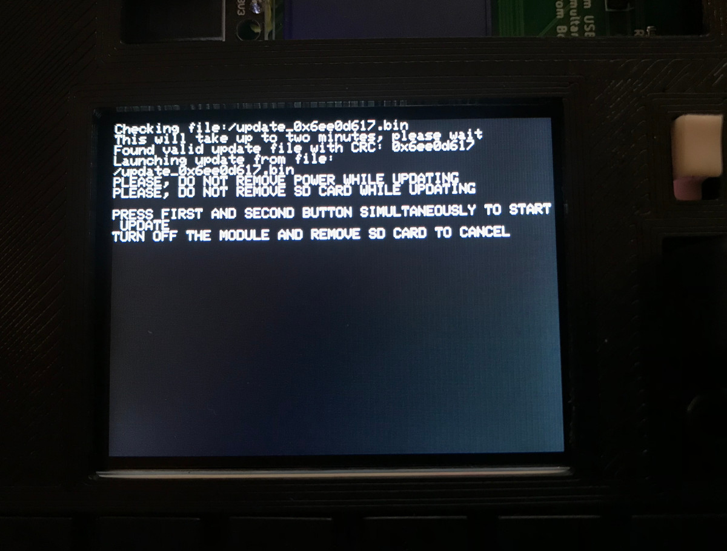
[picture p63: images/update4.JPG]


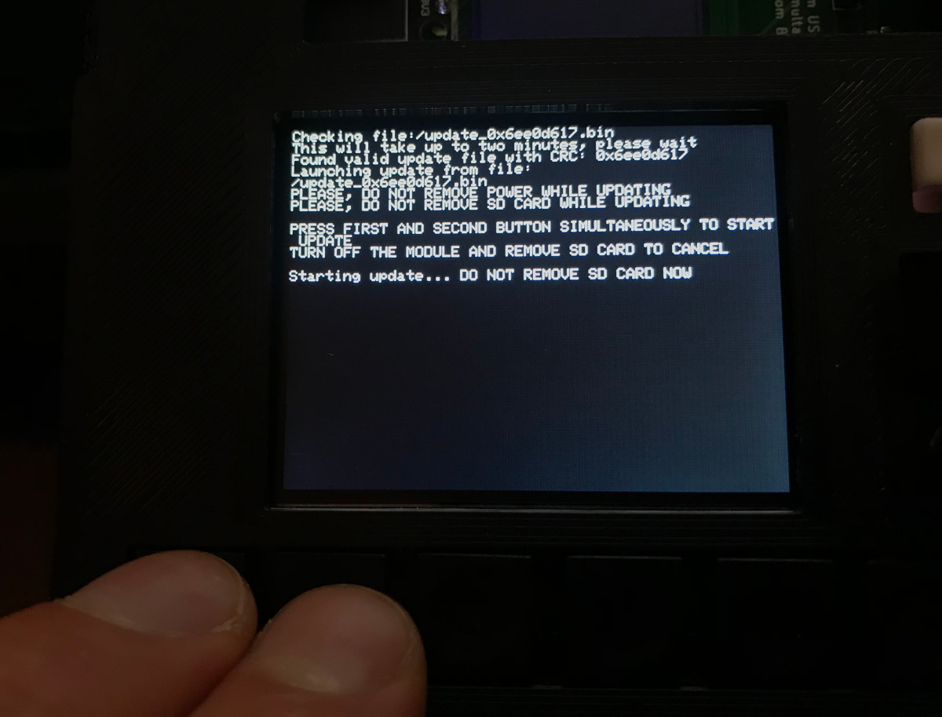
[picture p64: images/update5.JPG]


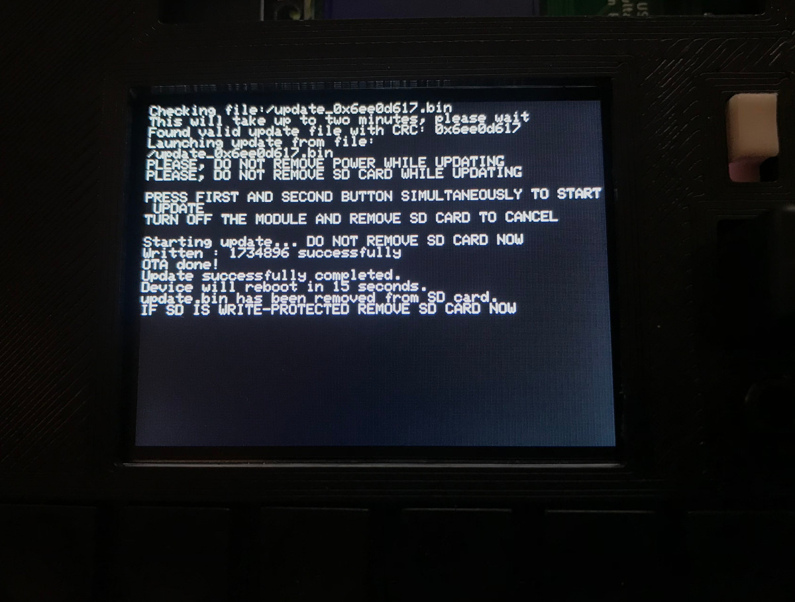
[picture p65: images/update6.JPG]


When the update is finished, the module will remove the _update.bin_ file from the SD card, and reboot after 15 seconds. Now you can remove the SD card and use the updated module normally.

Be careful when removing the card, as it is a tight fit and can take some time. Pull it backwards in small steps grabbing it from the sides.

The SD card should not be left inserted into the module, as it could prevent the RFID reader from operating correctly.

### Using Elfacun with Graham O'Neill drivers

Elfacun is compatible with Grahan O'Neill drivers via USB, Bluetooth and BLE. You can get them here:

[https://goneill.co.nz/chess.php](https://goneill.co.nz/chess.php)

_"DGT", "Millennium" and "Mephisto" are trademarks of their respective owners.
All the trademarks are used nominatively to indicate compatibility, and do not indicate affiliation to or endorsement by the trademark owners._

## New V1 and V2 features

### Force passive mode

You can force passive mode if you start the module keeping the fourth leftmost button pressed. You can release the button when you see the "mode logo" screen ("mode a" or "mode b").

Forcing passive mode is useful if Elfacun has problems to identify an external module, or if the external module freezes on startup.

### Hold mode

You can enter "hold mode" by keeping at any time for a couple of seconds the second leftmost button pressed. While on hold mode, the module will stop scanning the board, keep the position and a message will be displayed that indicates that the module can be removed from the board.

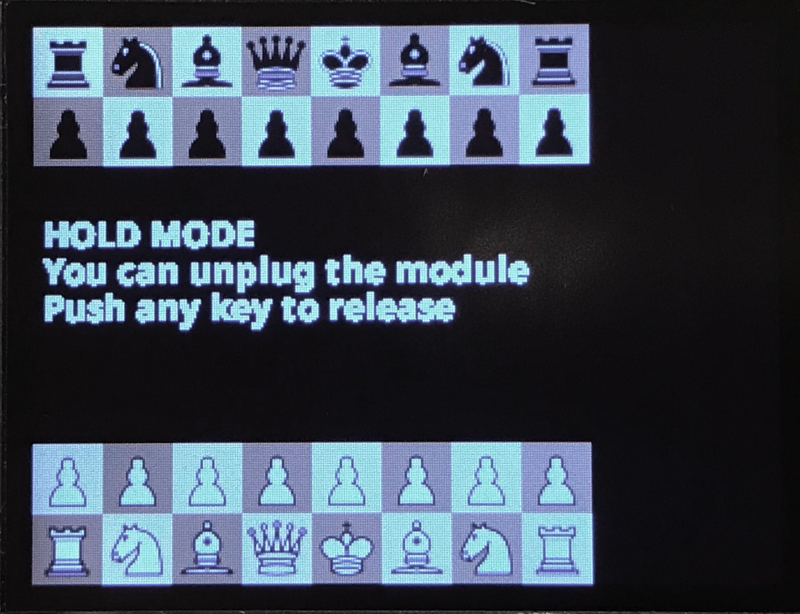
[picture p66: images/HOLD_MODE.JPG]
Hold mode


The module has to be connected to power with the USB cable to be able to be safely removed.

When you insert the module back in the board you can re-enable board scanning by pressing any button. When inserting back the module make sure that the pieces over the board are still on the same positions.

__If you have software version R7 or higher as a plus if you turn off the module while on "hold mode" it will remember and restore the position on the next module startup, as long as you don't move the pieces on the board while the module is off__. To use this feature you have to remove any SD card you have inserted in the module because the stored position will be deleted on startud in that case.

### Adjust BLE power

With software release R7 or higher you can now adjust the BLE signal power on the SD configuration adding this section:

    #Bluetooth power
    #Set the ble and bluetooth classic power level
    #it can help working with devices that are far away from the board
    #It is not recommended to change this value unless you have BT reliability issues
    #The valid values are 0-7
    #The default value is 5
    #bluetooh.power=0  -----> Corresponding to -12dbm
    #bluetooh.power=1  -----> Corresponding to  -9dbm
    #bluetooh.power=2  -----> Corresponding to  -6dbm
    #bluetooh.power=3  -----> Corresponding to  -3dbm
    #bluetooh.power=4  -----> Corresponding to   0dbm
    #bluetooh.power=5  -----> Corresponding to  +3dbm
    #bluetooh.power=6  -----> Corresponding to  +6dbm
    #bluetooh.power=7  -----> Corresponding to  +9dbm
    #
    #bluetooth.power=5

The default signal level is 5 for +3dbm. A higher level could help getting more range for a BLE connection. It is not recommended to change this value unless you have any problem with BLE range. The default level should work fine for devices on the same room as the module.

### Adjust sound tones

With software release R7 or higher you can adjust the tone and duration of the sounds emitted by the module on the SD configuration adding this section:

    #Buzzer tones setup
    #You can change the frequency and duration of the sound tones:
    #Tone 1 is piece raise
    #Tone 2 is piece placement
    #Tone 3 is led sound for passive mode
    #Frequency is in hertzs
    #Duration is in milliseconds
    #
    #buzzer.tone.1.frequency=2000
    #buzzer.tone.1.duration=100
    #
    #buzzer.tone.2.frequency=1000
    #buzzer.tone.2.duration=100
    #
    #buzzer.tone.3.frequency=1500
    #buzzer.tone.3.duration=20

### On screen LED indications

With software release R7 or higher when the module is operating in passive mode alongside an original module, the flashing LEDs from the remote app connected to Elfacun will be indicated on-screen as flashing squares and sounds.

When Elfacun is used with an original module, the original module is in full control of the board leds so it is not possible to show the remote app LEDs onboard. Now you will be able to watch them on-screen so that you can have remote movement indications without looking at the remote app interface.

If you don't want the sounds that indicate the remote flashing leds you can disable them on the SD `settings.txt` adding or modifying this section:

    #Buzzer enabled for passive led indications on screen
    #Valid values are true, false
    #Default value is true
    #When in passive mode with original modules Elfacun cannot use the on-board leds
    #so it uses the screen to indicate incoming led information. When this is enables the led
    #indications on-screen are accompanied by sounds
    #
    buzzer.enabled.passive.led=true

### Chessnut mode

With software release R11 or higher you can enable at startup a new mode of operation "Mode C". While on "Mode C" any Chessnut-compatible app should be able to connect to the module via Bluetooth BLE.

To start the module in "Mode C" Keep pressed simultaneously the first and second buttons while booting.

While on "Mode C" you won't be able to connect to the module using the Chesslink protocol.

Then once started you should be able to connect using BLE from any Chessnut-compatible app.

### Scally homage Screen

Alan 'Scally' Cooper was a key contributor of this project. His help was crucial to get the V2 universal compatibility, the Diablillo interface and a lot of the firmware improvements over the time. He sadly passed away in 2024, and as a homage to him I have included a brief homage screen to appear on every module startup starting on release R14. To enable this screen you have to add this to your settings.txt configuration and load it on the module with the SD card:

    scally.homage=true

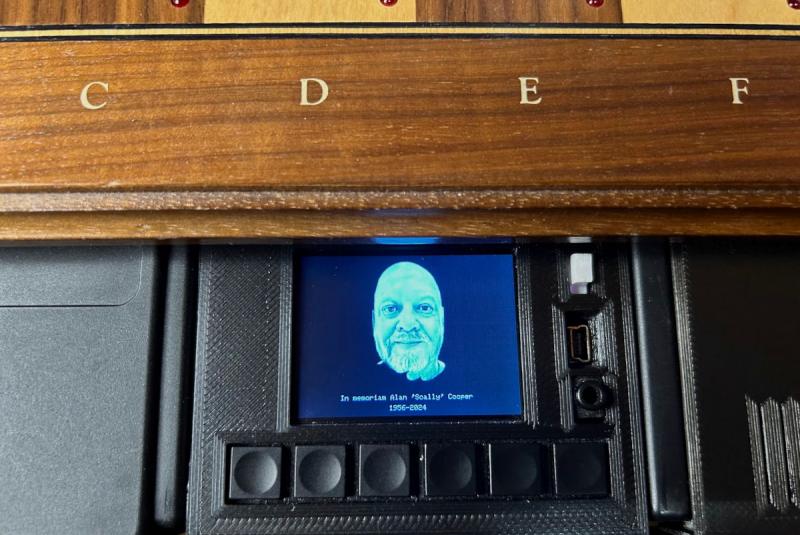
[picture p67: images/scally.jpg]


### Chess 960 mode

With software release R15 or higher you can enable the Chess 960 mode and play Chess 960/Fischer Random starting positions with any compatible app.

To enable this mode you have to keep pushed the third leftmost button for 1-2 seconds. The screen will indicate "960" when this mode is activated. If you want to play with the black pieces on front, you have to keep the button pushed for longer, like 4-5 seconds to enter the "board inverted 960 mode".

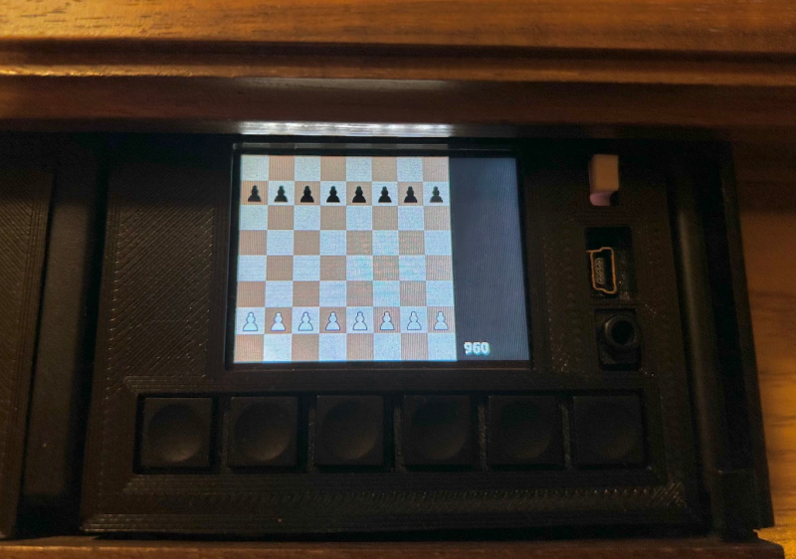
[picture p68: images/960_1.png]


To configure the starting position, once in 960 mode you have to place first all the pawns, white and black on the second and seventh ranks, like this:

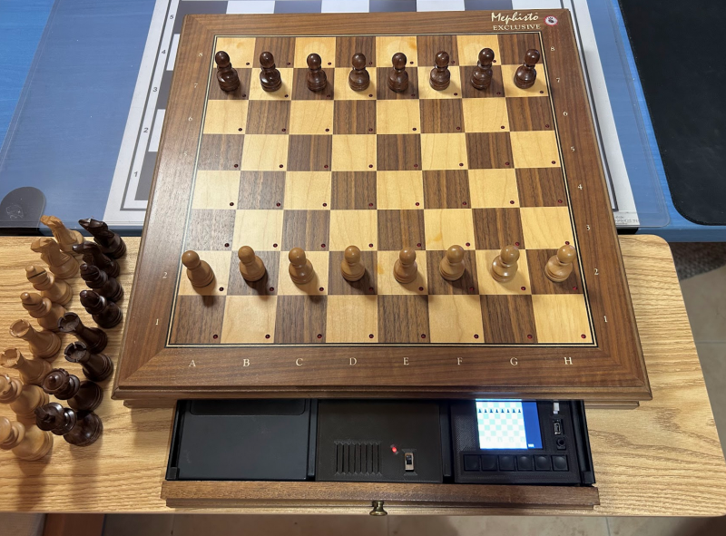
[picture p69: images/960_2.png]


Now you can place all the pieces, but you have to do it __exactly in the following order__:

1. King
2. Queen
3. Both rooks
4. Both bishops
5. Both knights

You can place first the white pieces or first the black pieces, the orden in colour doesn't matter.

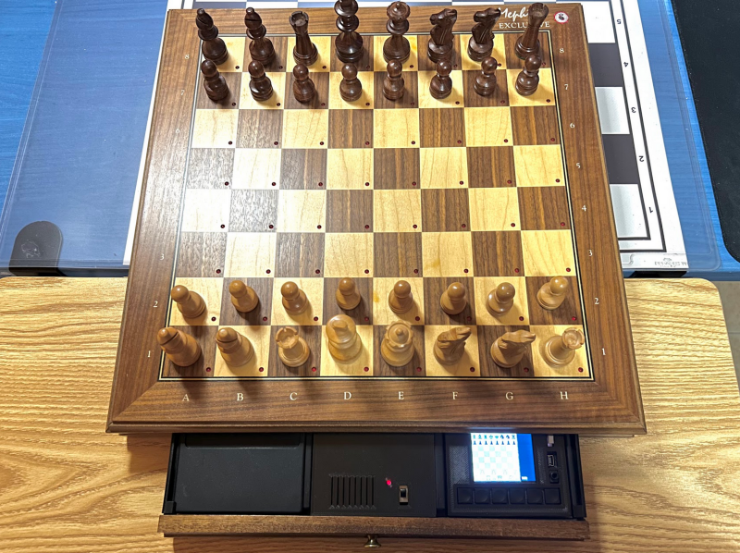
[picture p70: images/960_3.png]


Once placed, if you got it wrong or you want to change the position, you have to remove the pieces and start again from the "only pawns" position and follow again the indicated order.

There are several online sites where you can generate Chess 960/Fischer Random positions like this one: https://wlabe.com/chess960

You can return to the "regular chess" mode by keeping pushed again the third leftmost button for 1-2 seconds.

## V2 only features

### Dual leds mode

_To use dual leds, you need at least one V2 module. Dual leds will work with V1+V2 or V2+V2, but not with two V1 modules._

When you use two Elfacun modules compatible with this feature in the same board, the passive module will recognize the active one on startup and it will send to it LED updates via BLE during the game. That way both chess apps willbe able to indicate their moves on the board leds.

If you are using V1 and V2 modules you have to start V1 first. If using only V2 modules the boot order is irrelevant .

You have to make sure that no app connects to the modules via BLE before both modules are fully started. If that happens the feature won't work but the modules will work otherwise fine. When the connection is established you will see an "X" LED pattern for a couple of seconds, then all the LEDs will turn off. After that you are free to connect apps to the modules the way you want.

You have to enable this feature using a new parameter on the SD card's `settings.txt` file. This feature is disabled by default because it makes the module startup a little slower.

    #DUAL LEDS enabled (Only V2 modules)
    #Valid values are true, false
    #Default value is false
    #When a V2 module starts in passive mode and this parameter is enables, the module will scan for the
    #presence of other Elfacun module (V1 or V2) using BLE. If it finds it, it will start a BLE connection to
    #relay its LED status, so both modules will be able to control the board LEDs
    #It is disabled by default as it only makes sense if you have two modules and with the feature disabled the
    #passive mode startup will be faster
    #
    leds.dual.enabled=false

### Adjust screen brightness

* To increase screen brightness keep pressed the module's rightmost button.
* To decrease screen brightness keep pressed the module's leftmost button.
* The setting will be stored and remembered on startup.

You can override the stored setting using a new parameter on the SD card's `settings.txt` file.

    #Screen brightness (Only V2 modules)
    #Only for V2 modules, will be ignored on V1 modules
    #Overrides the stored default screen brightness
    #Valid values: 5-255
    #Default value: 64
    #
    screen.brightness.default = 64

### Enable or disable power from board

On V2 modules you can enable power from board installing a jumper clearly marked on the user-accesible side of the PCB.

On V1 modules follow the instructions [here](./BROCOLI.md#using-brocoli-with-v1-modules)

_"DGT", "Millennium", "Mephisto" and "Chessnut" are trademarks of their respective owners.
All the trademarks are used nominatively to indicate compatibility, and do not indicate affiliation to or endorsement by the trademark owners._

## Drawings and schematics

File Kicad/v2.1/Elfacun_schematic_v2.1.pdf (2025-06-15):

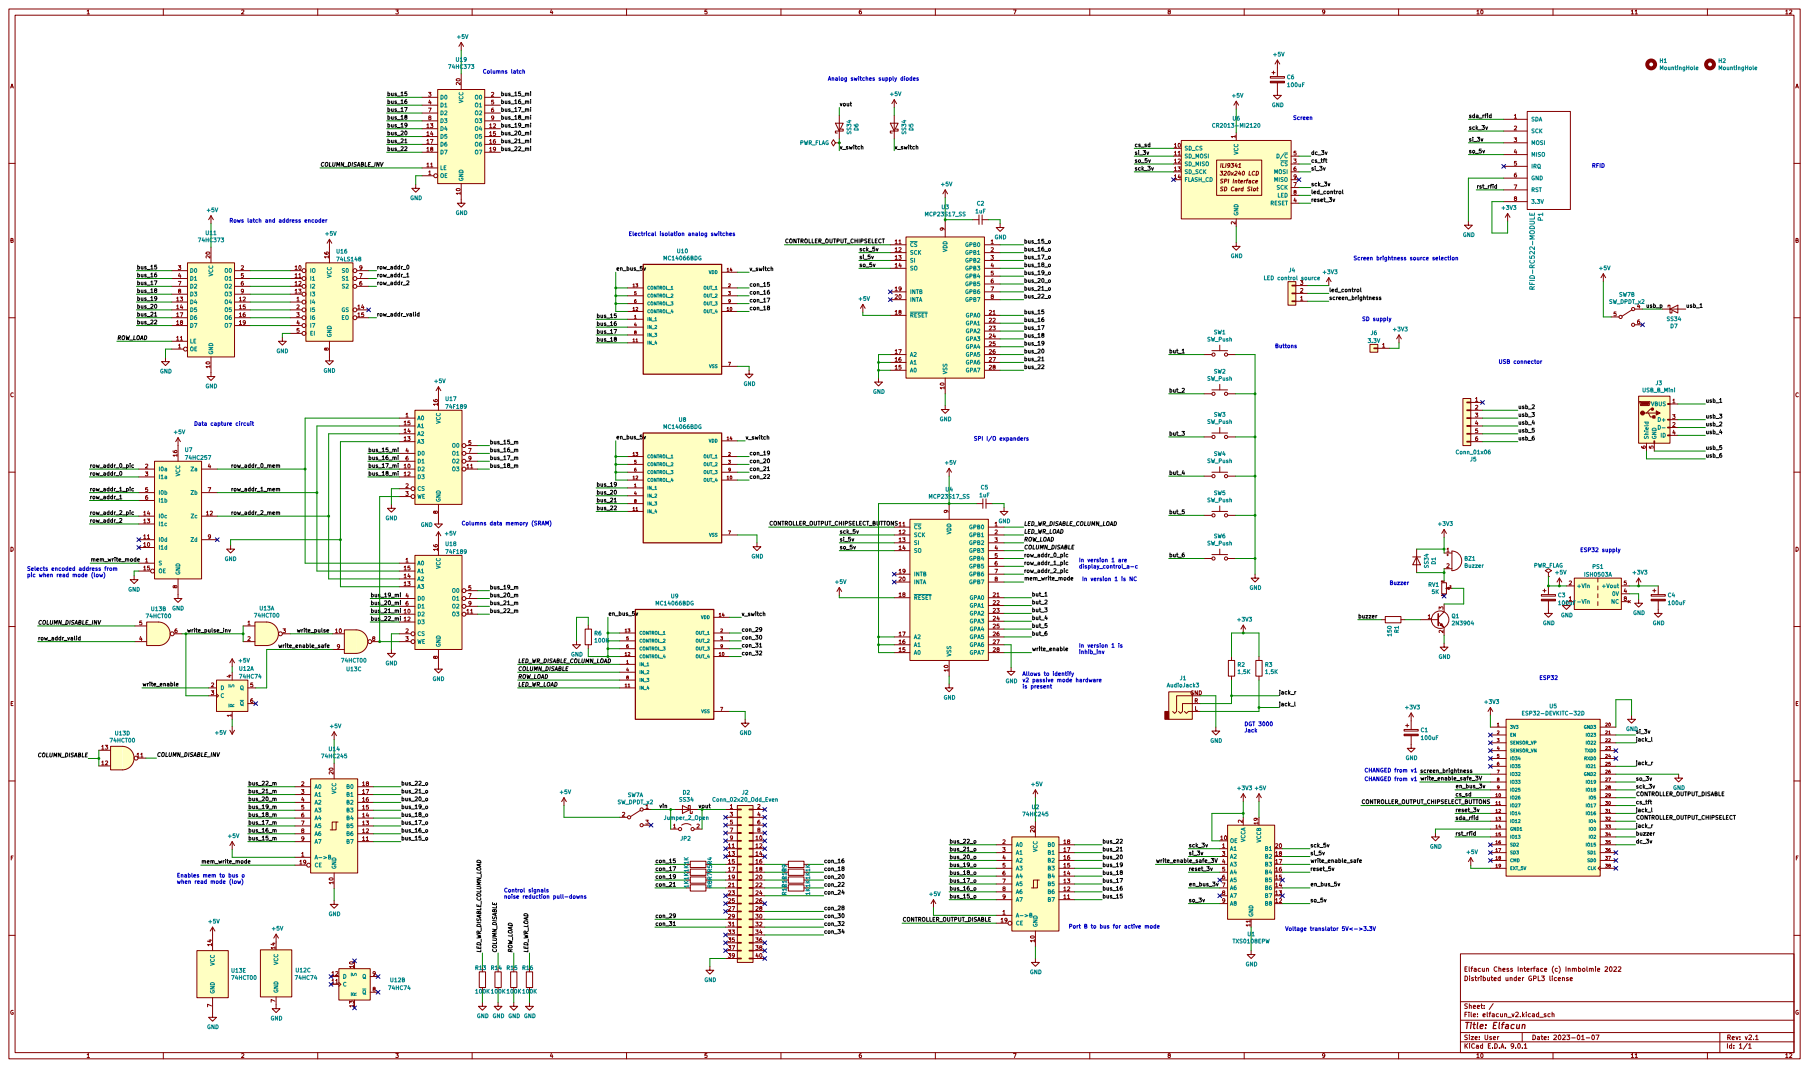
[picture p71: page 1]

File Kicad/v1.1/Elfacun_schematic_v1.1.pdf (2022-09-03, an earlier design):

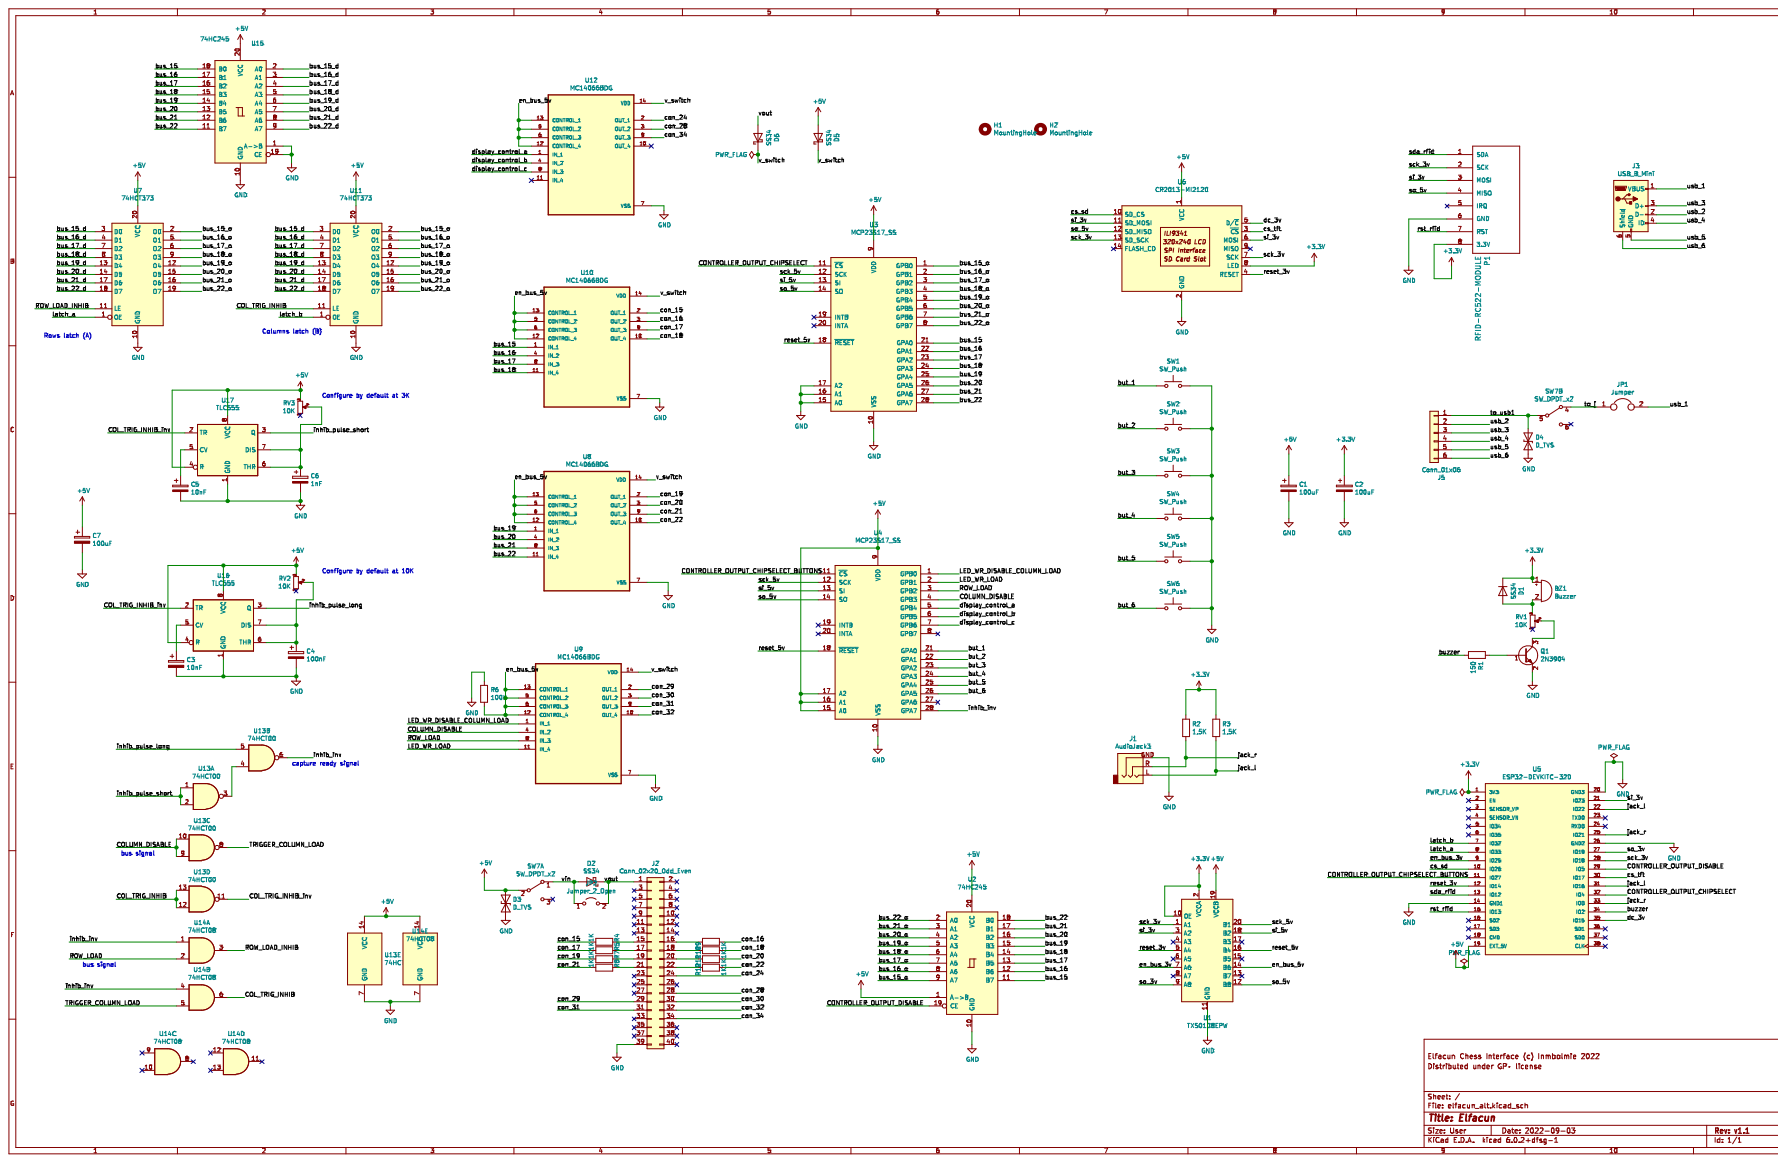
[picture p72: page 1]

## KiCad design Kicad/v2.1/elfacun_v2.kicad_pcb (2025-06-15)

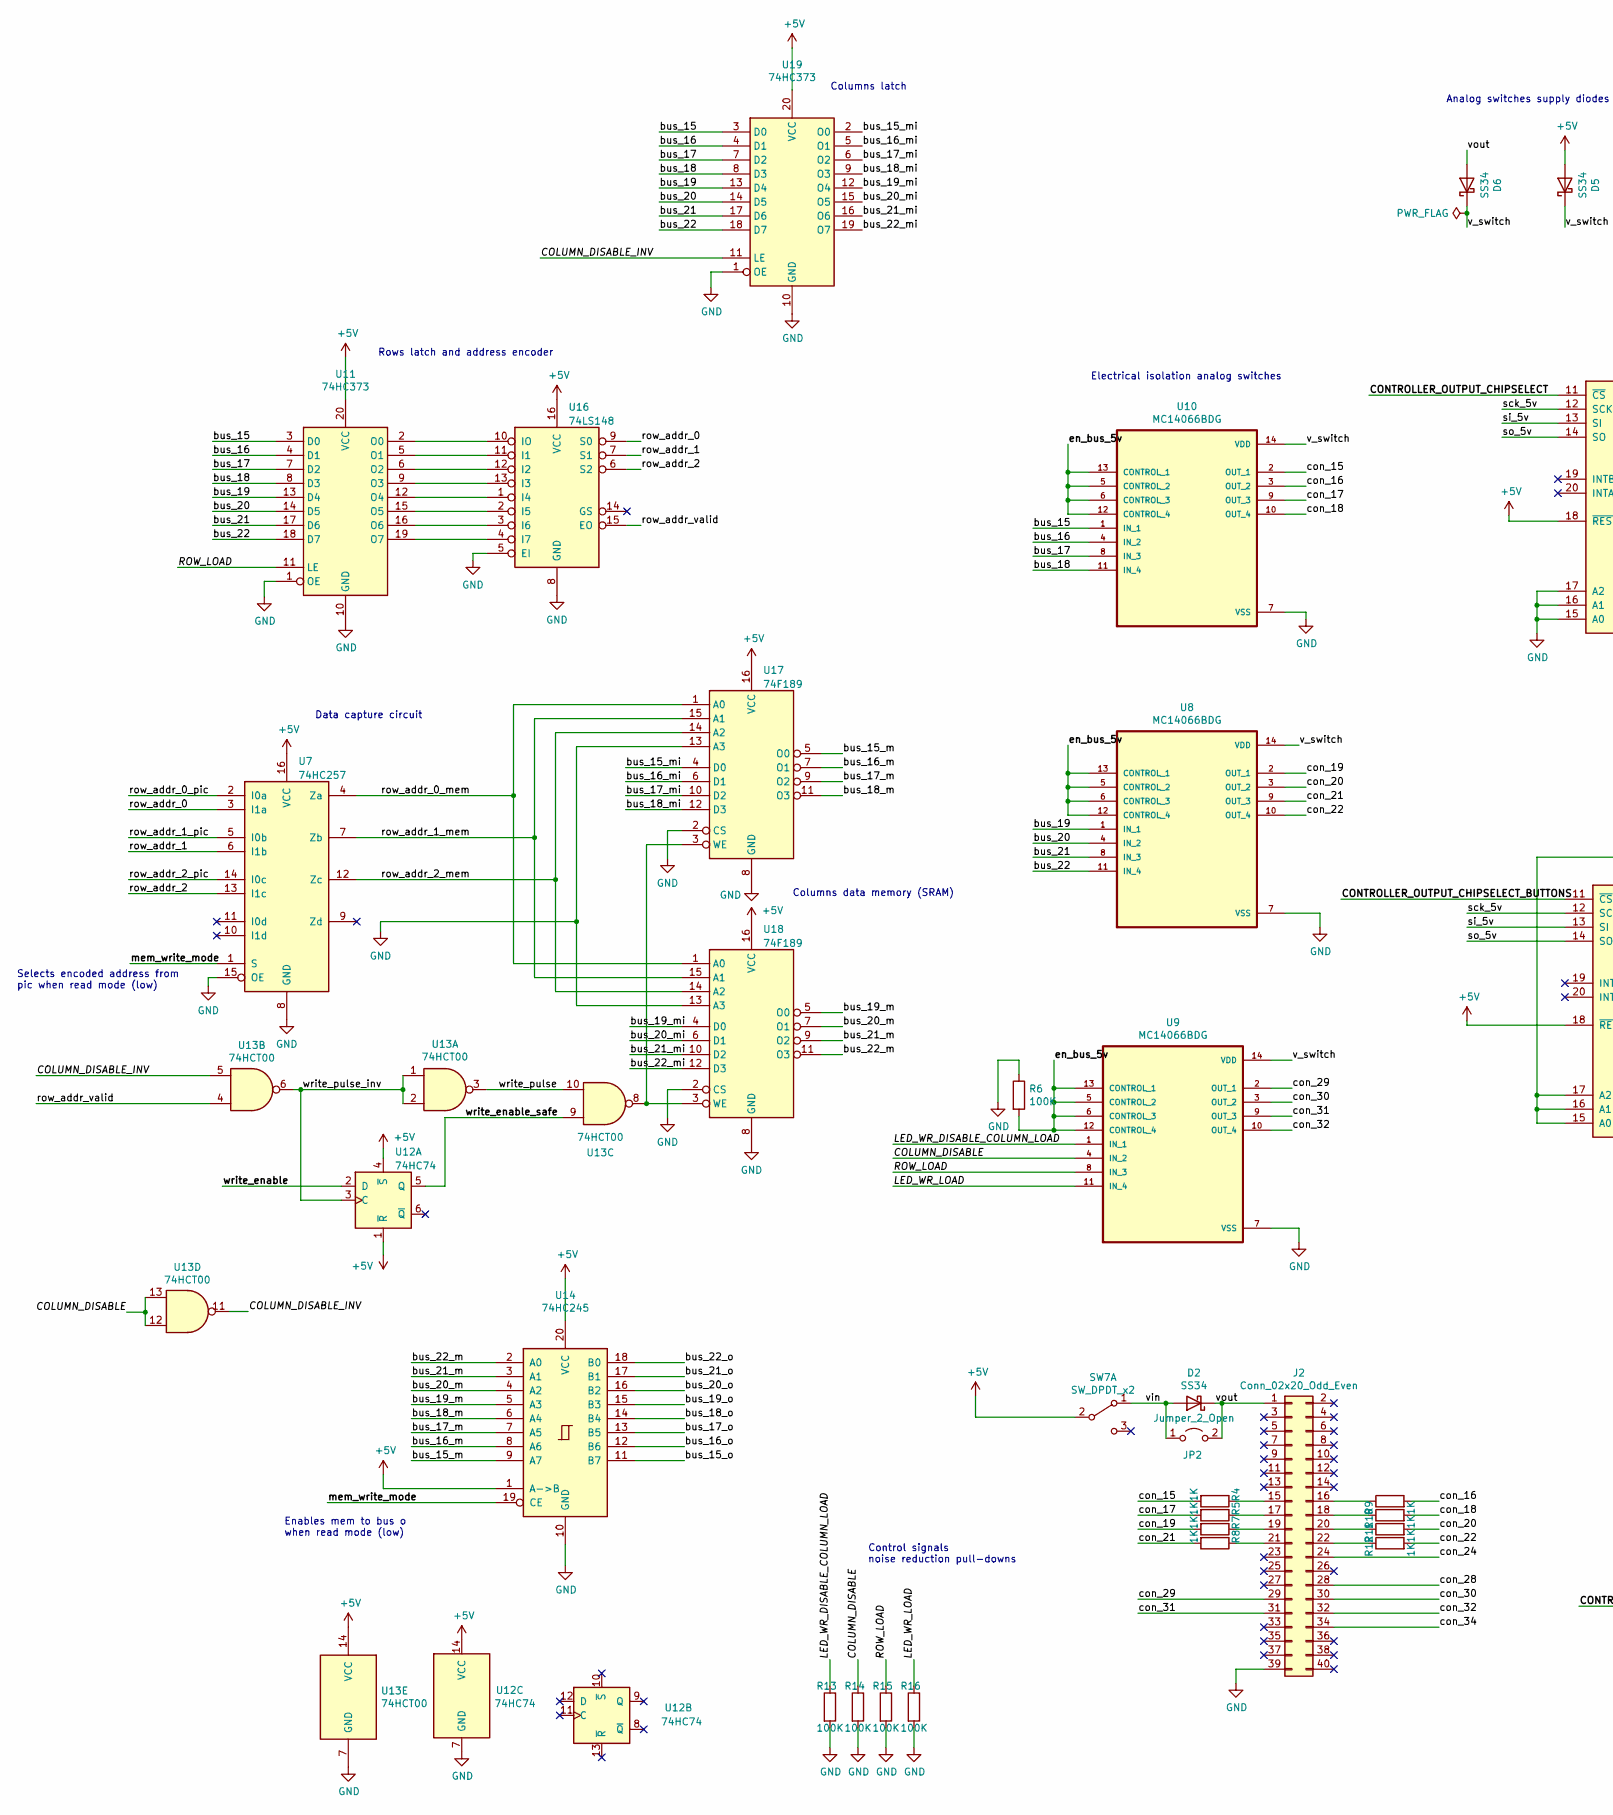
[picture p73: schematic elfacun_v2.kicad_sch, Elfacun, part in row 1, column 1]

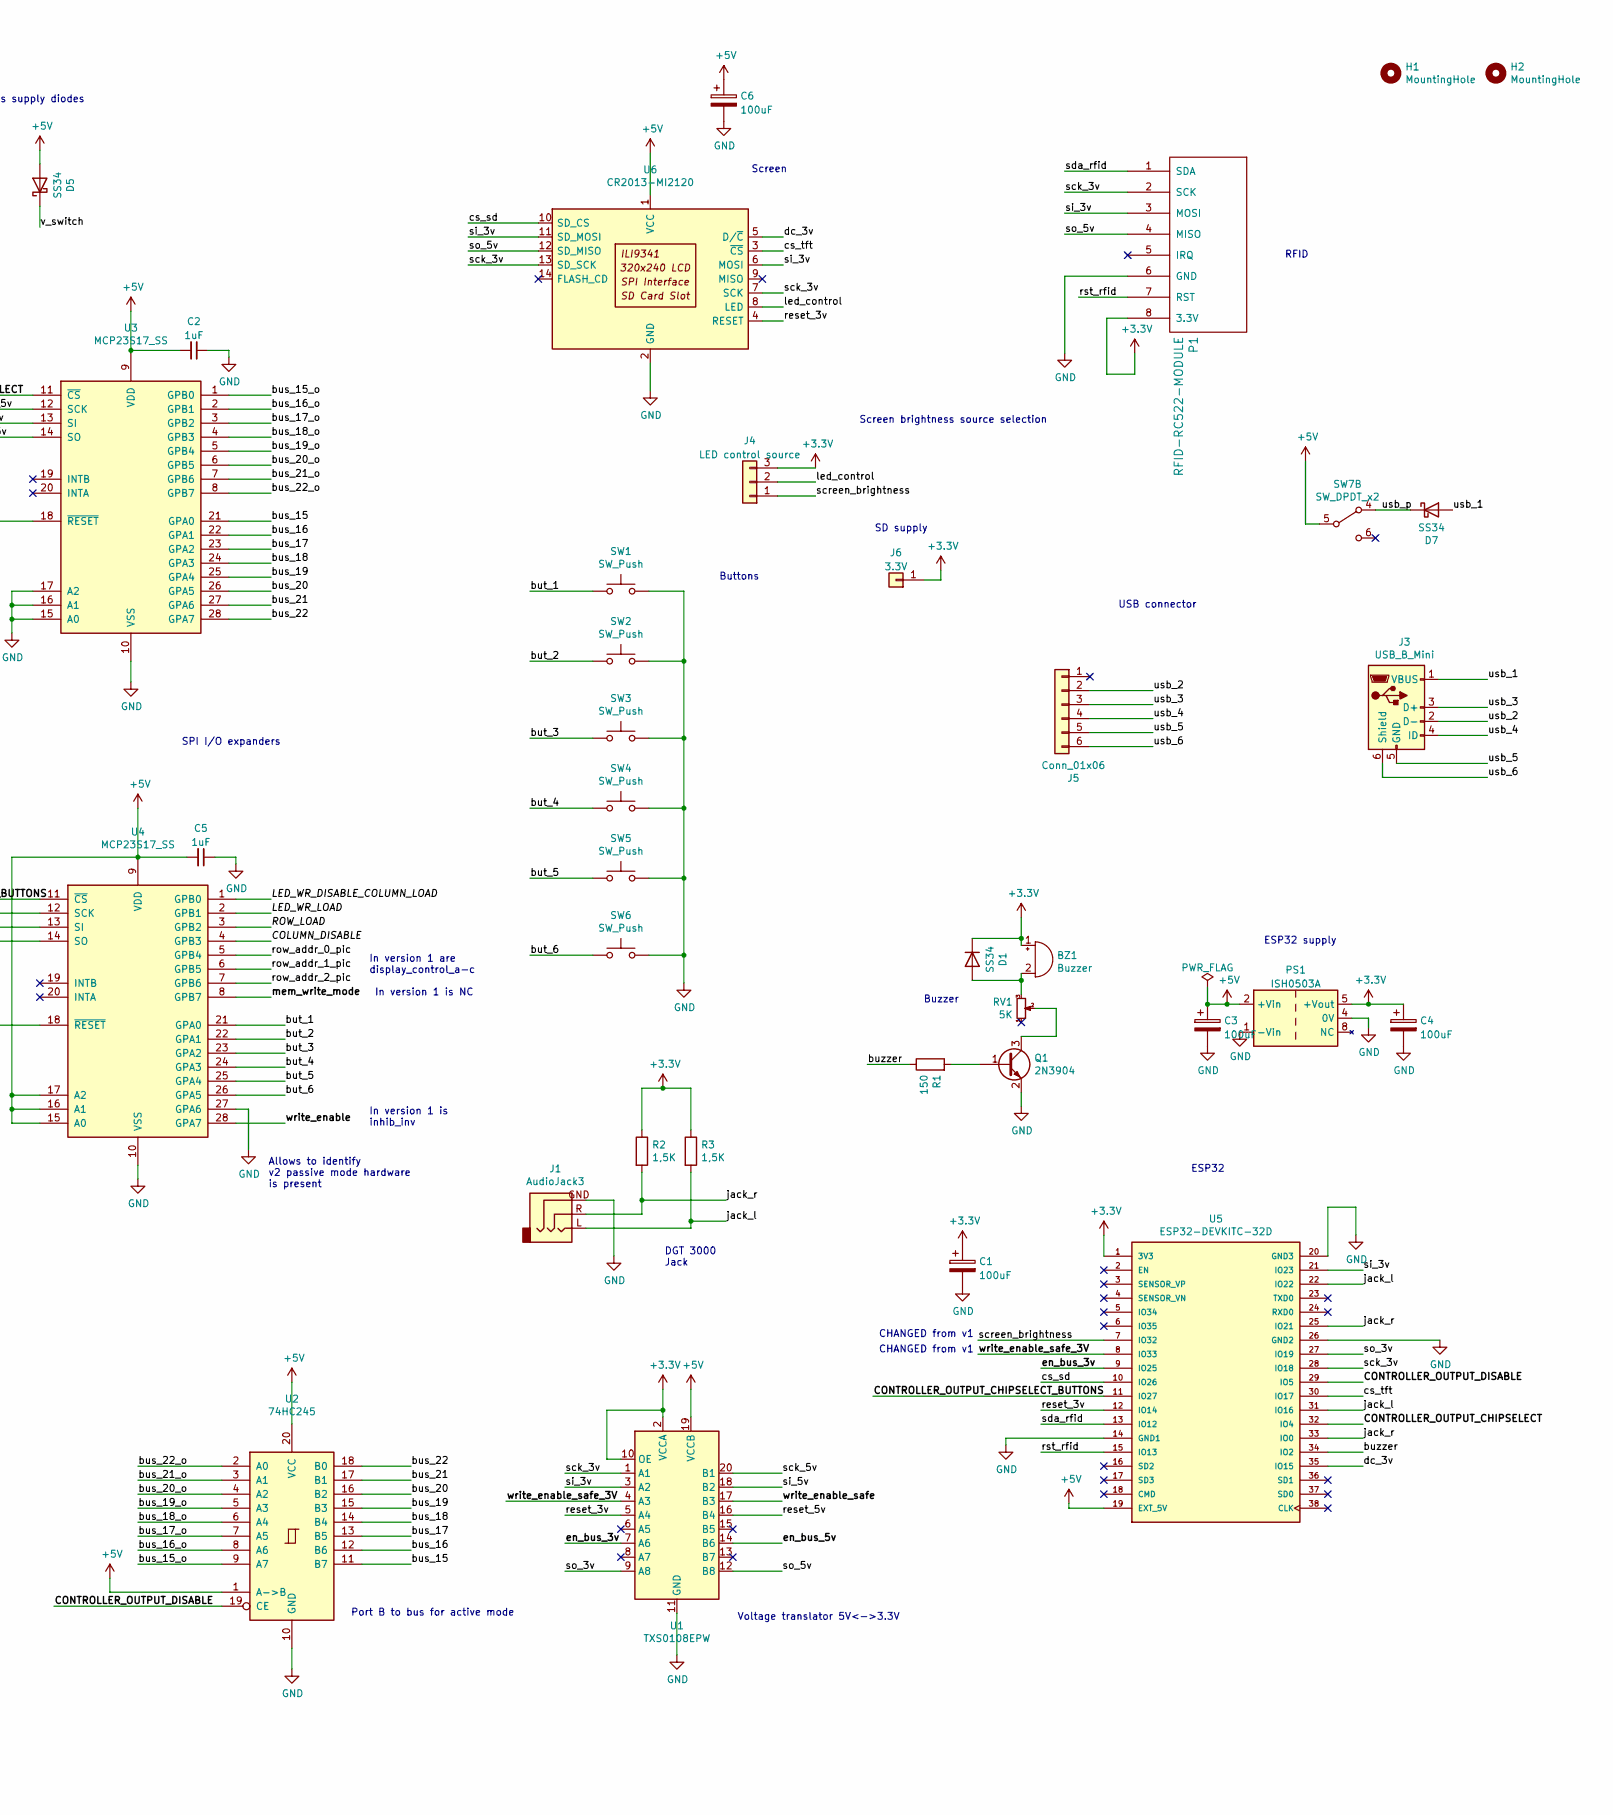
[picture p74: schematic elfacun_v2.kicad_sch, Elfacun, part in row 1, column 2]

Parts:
BZ1: Buzzer; MagneticBuzzer_ProSignal_ABT-410-RC
C1, C3, C4, C6: 100uF; C_1206_3216Metric; LCSC C15008
C2, C5: 1uF; C_0603_1608Metric; LCSC C15849
D1, D2, D5, D6, D7: SS34; D_SMA; LCSC C8678
H1, H2: MountingHole; MountingHole_3.5mm
J1: AudioJack3; AUDIO-TH_PJ-3059-X; LCSC C319114
J2: Conn_02x20_Odd_Even; PinHeader_2x20_P2.54mm_Horizontal
J3: USB_B_Mini; USB_Mini-B_Tensility_54-00023_Vertical; LCSC C13453
J4: LED control source; PinHeader_1x03_P2.54mm_Vertical
J5: Conn_01x06; PinHeader_1x06_P2.54mm_Horizontal
J6: 3.3V; PinHeader_1x01_P2.54mm_Horizontal
JP2: Jumper_2_Open; PinHeader_1x02_P2.54mm_Vertical
P1: RFID-RC522-MODULE; PinHeader_1x08_P2.54mm_Vertical
PS1: ISH0503A; ISE0303A
Q1: 2N3904; SOT-23; LCSC C18536
R1: 150; R_0603_1608Metric; LCSC C22808
R2, R3: 1,5K; R_0603_1608Metric; LCSC C22843
R4, R5, R7, R8, R9, R10, R11, R12: 1K; R_0603_1608Metric; LCSC C21190
R6, R13, R14, R15, R16: 100K; R_0603_1608Metric; LCSC C25803
RV1: 5K; RES-ADJ-SMD_G32AT; LCSC C128119
SW1, SW2, SW3, SW4, SW5, SW6: SW_Push; honyone_pb13_switch
SW7: SW_DPDT_x2; SW-TH_K3-2235S-K1
U1: TXS0108EPW; TSSOP-20_4.4x6.5mm_P0.65mm; LCSC C53406
U2, U14: 74HC245; SO-20_5.3x12.6mm_P1.27mm; LCSC C133641
U3, U4: MCP23S17_SS; DIP-28_W7.62mm; LCSC C145413
U5: ESP32-DEVKITC-32D; MODULE_ESP32-DEVKITC-32D
U6: CR2013-MI2120
U7: 74HC257; SOIC-16_3.9x9.9mm_P1.27mm; LCSC C7645
U8, U9, U10: MC14066BDG; SOIC-14_3.9x8.7mm_P1.27mm; LCSC C52828
U11, U19: 74HC373; TSSOP-20_4.4x6.5mm_P0.65mm; LCSC C132998
U12: 74HC74; SO-14_3.9x8.65mm_P1.27mm; LCSC C39990
U13: 74HCT00; SOIC-14_3.9x8.7mm_P1.27mm
U16: 74LS148; SOP-16_3.9x9.9mm_P1.27mm; LCSC C521196
U17, U18: 74F189; DIP-16_W7.62mm

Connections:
+3V3: BZ1.1 (-), C1.1, C4.1, D1.1 (K), J4.3, J6.1, P1.8 (3.3V), PS1.5 (+Vout), R2.1, R3.1, U1.2 (VCCA), U1.10 (OE), U5.1 (3V3)
+5V: C2.2, C3.1, C5.2, C6.1, D5.2 (A), PS1.2 (+Vin), SW7.2 (B), SW7.5 (B), U1.19 (VCCB), U2.1 (A->B), U2.20 (VCC), U3.9 (VDD), U3.18 (~RESET), U4.9 (VDD), U4.15 (A0), U4.16 (A1), U4.17 (A2), U4.18 (~RESET), U5.19 (EXT_5V), U6.1 (VCC), U7.16 (VCC), U11.20 (VCC), U12.1 (~R), U12.4 (~S), U12.14 (VCC), U13.14 (VCC), U14.1 (A->B), U14.20 (VCC), U16.16 (VCC), U17.16 (VCC), U18.16 (VCC), U19.20 (VCC)
/COLUMN_DISABLE: R14.1, U4.4 (GPB3), U9.4 (IN_2), U13.12, U13.13
/COLUMN_DISABLE_INV: U13.5, U13.11, U19.11 (LE)
/CONTROLLER_OUTPUT_CHIPSELECT: U3.11 (~CS), U5.32 (IO4)
/CONTROLLER_OUTPUT_CHIPSELECT_BUTTONS: U4.11 (~CS), U5.11 (IO27)
/CONTROLLER_OUTPUT_DISABLE: U2.19 (CE), U5.29 (IO5)
/LED_WR_DISABLE_COLUMN_LOAD: R13.1, U4.1 (GPB0), U9.1 (IN_1)
/LED_WR_LOAD: R16.1, U4.2 (GPB1), U9.11 (IN_4)
/ROW_LOAD: R15.1, U4.3 (GPB2), U9.8 (IN_3), U11.11 (LE)
/bus_15: U2.11 (B7), U3.21 (GPA0), U10.1 (IN_1), U11.3 (D0), U19.3 (D0)
/bus_15_m: U14.9 (A7), U17.5 (O0)
/bus_15_mi: U17.4 (D0), U19.2 (O0)
/bus_15_o: U2.9 (A7), U3.1 (GPB0), U14.11 (B7)
/bus_16: U2.12 (B6), U3.22 (GPA1), U10.4 (IN_2), U11.4 (D1), U19.4 (D1)
/bus_16_m: U14.8 (A6), U17.7 (O1)
/bus_16_mi: U17.6 (D1), U19.5 (O1)
/bus_16_o: U2.8 (A6), U3.2 (GPB1), U14.12 (B6)
/bus_17: U2.13 (B5), U3.23 (GPA2), U10.8 (IN_3), U11.7 (D2), U19.7 (D2)
/bus_17_m: U14.7 (A5), U17.9 (O2)
/bus_17_mi: U17.10 (D2), U19.6 (O2)
/bus_17_o: U2.7 (A5), U3.3 (GPB2), U14.13 (B5)
/bus_18: U2.14 (B4), U3.24 (GPA3), U10.11 (IN_4), U11.8 (D3), U19.8 (D3)
/bus_18_m: U14.6 (A4), U17.11 (O3)
/bus_18_mi: U17.12 (D3), U19.9 (O3)
/bus_18_o: U2.6 (A4), U3.4 (GPB3), U14.14 (B4)
/bus_19: U2.15 (B3), U3.25 (GPA4), U8.1 (IN_1), U11.13 (D4), U19.13 (D4)
/bus_19_m: U14.5 (A3), U18.5 (O0)
/bus_19_mi: U18.4 (D0), U19.12 (O4)
/bus_19_o: U2.5 (A3), U3.5 (GPB4), U14.15 (B3)
/bus_20: U2.16 (B2), U3.26 (GPA5), U8.4 (IN_2), U11.14 (D5), U19.14 (D5)
/bus_20_m: U14.4 (A2), U18.7 (O1)
/bus_20_mi: U18.6 (D1), U19.15 (O5)
/bus_20_o: U2.4 (A2), U3.6 (GPB5), U14.16 (B2)
/bus_21: U2.17 (B1), U3.27 (GPA6), U8.8 (IN_3), U11.17 (D6), U19.17 (D6)
/bus_21_m: U14.3 (A1), U18.9 (O2)
/bus_21_mi: U18.10 (D2), U19.16 (O6)
/bus_21_o: U2.3 (A1), U3.7 (GPB6), U14.17 (B1)
/bus_22: U2.18 (B0), U3.28 (GPA7), U8.11 (IN_4), U11.18 (D7), U19.18 (D7)
/bus_22_m: U14.2 (A0), U18.11 (O3)
/bus_22_mi: U18.12 (D3), U19.19 (O7)
/bus_22_o: U2.2 (A0), U3.8 (GPB7), U14.18 (B0)
/but_1: SW1.1, U4.21 (GPA0)
/but_2: SW2.1, U4.22 (GPA1)
/but_3: SW3.1, U4.23 (GPA2)
/but_4: SW4.1, U4.24 (GPA3)
/but_5: SW5.1, U4.25 (GPA4)
/but_6: SW6.1, U4.26 (GPA5)
/buzzer: R1.1, U5.34 (IO2)
/con_15: R4.2, U10.2 (OUT_1)
/con_16: R9.2, U10.3 (OUT_2)
/con_17: R5.2, U10.9 (OUT_3)
/con_18: R10.2, U10.10 (OUT_4)
/con_19: R7.2, U8.2 (OUT_1)
/con_20: R11.2, U8.3 (OUT_2)
/con_21: R8.2, U8.9 (OUT_3)
/con_22: R12.2, U8.10 (OUT_4)
/con_24: J2.24
/con_28: J2.28
/con_29: J2.29, U9.2 (OUT_1)
/con_30: J2.30, U9.3 (OUT_2)
/con_31: J2.31, U9.9 (OUT_3)
/con_32: J2.32, U9.10 (OUT_4)
/con_34: J2.34
/cs_sd: U5.10 (IO26), U6.10 (SD_CS)
/cs_tft: U5.30 (IO17), U6.3 (~CS)
/dc_3v: U5.35 (IO15), U6.5 (D/~C)
/en_bus_3v: U1.7 (A6), U5.9 (IO25)
/en_bus_5v: R6.2, U1.14 (B6), U8.5 (CONTROL_2), U8.6 (CONTROL_3), U8.12 (CONTROL_4), U8.13 (CONTROL_1), U9.5 (CONTROL_2), U9.6 (CONTROL_3), U9.12 (CONTROL_4), U9.13 (CONTROL_1), U10.5 (CONTROL_2), U10.6 (CONTROL_3), U10.12 (CONTROL_4), U10.13 (CONTROL_1)
/jack_l: J1.L, R3.2, U5.22 (IO22), U5.31 (IO16)
/jack_r: J1.R, R2.2, U5.25 (IO21), U5.33 (IO0)
/led_control: J4.2, U6.8 (LED)
/mem_write_mode: U4.8 (GPB7), U7.1 (S), U14.19 (CE)
/reset_3v: U1.5 (A4), U5.12 (IO14), U6.4 (RESET)
/reset_5v: U1.16 (B4)
/row_addr_0: U7.3 (I1a), U16.9 (S0)
/row_addr_0_mem: U7.4 (Za), U17.1 (A0), U18.1 (A0)
/row_addr_0_pic: U4.5 (GPB4), U7.2 (I0a)
/row_addr_1: U7.6 (I1b), U16.7 (S1)
/row_addr_1_mem: U7.7 (Zb), U17.15 (A1), U18.15 (A1)
/row_addr_1_pic: U4.6 (GPB5), U7.5 (I0b)
/row_addr_2: U7.13 (I1c), U16.6 (S2)
/row_addr_2_mem: U7.12 (Zc), U17.14 (A2), U18.14 (A2)
/row_addr_2_pic: U4.7 (GPB6), U7.14 (I0c)
/row_addr_valid: U13.4, U16.15 (EO)
/rst_rfid: P1.7 (RST), U5.15 (IO13)
/sck_3v: P1.2 (SCK), U1.1 (A1), U5.28 (IO18), U6.7 (SCK), U6.13 (SD_SCK)
/sck_5v: U1.20 (B1), U3.12 (SCK), U4.12 (SCK)
/screen_brightness: J4.1, U5.7 (IO32)
/sda_rfid: P1.1 (SDA), U5.13 (IO12)
/si_3v: P1.3 (MOSI), U1.3 (A2), U5.21 (IO23), U6.6 (MOSI), U6.11 (SD_MOSI)
/si_5v: U1.18 (B2), U3.13 (SI), U4.13 (SI)
/so_3v: U1.9 (A8), U5.27 (IO19)
/so_5v: P1.4 (MISO), U1.12 (B8), U3.14 (SO), U4.14 (SO), U6.12 (SD_MISO)
/usb_1: D7.2 (A), J3.1 (VBUS)
/usb_2: J3.2 (D-), J5.2
/usb_3: J3.3 (D+), J5.3
/usb_4: J3.4 (ID), J5.4
/usb_5: J3.5 (GND), J5.5
/usb_6: J3.6 (Shield), J5.6
/usb_p: D7.1 (K), SW7.4 (A)
/v_switch: D5.1 (K), D6.1 (K), U8.14 (VDD), U9.14 (VDD), U10.14 (VDD)
/vin: D2.2 (A), JP2.1 (A), SW7.1 (A)
/vout: D2.1 (K), D6.2 (A), J2.1, JP2.2 (B)
/write_enable: U4.28 (GPA7), U12.2 (D)
/write_enable_safe: U1.17 (B3), U12.5 (Q), U13.9
/write_enable_safe_3V: U1.4 (A3), U5.8 (IO33)
/write_pulse: U13.3, U13.10
/write_pulse_inv: U12.3 (C), U13.1, U13.2, U13.6
GND: C1.2, C2.1, C3.2, C4.2, C5.1, C6.2, J1.GND, J2.39, P1.6 (GND), PS1.1 (-Vin), PS1.4 (0V), Q1.2 (E), R6.1, R13.2, R14.2, R15.2, R16.2, SW1.2, SW2.2, SW3.2, SW4.2, SW5.2, SW6.2, U1.11 (GND), U2.10 (GND), U3.10 (VSS), U3.15 (A0), U3.16 (A1), U3.17 (A2), U4.10 (VSS), U4.27 (GPA6), U5.14 (GND1), U5.20 (GND3), U5.26 (GND2), U6.2 (GND), U7.8 (GND), U7.15 (OE), U8.7 (VSS), U9.7 (VSS), U10.7 (VSS), U11.1 (OE), U11.10 (GND), U12.7 (GND), U13.7 (GND), U14.10 (GND), U16.5 (EI), U16.8 (GND), U17.2 (CS), U17.8 (GND), U17.13 (A3), U18.2 (CS), U18.8 (GND), U18.13 (A3), U19.1 (OE), U19.10 (GND)
unnamed: BZ1.2 (+), D1.2 (A), RV1.3
unnamed: J2.15, R4.1
unnamed: J2.16, R9.1
unnamed: J2.17, R5.1
unnamed: J2.18, R10.1
unnamed: J2.19, R7.1
unnamed: J2.20, R11.1
unnamed: J2.21, R8.1
unnamed: J2.22, R12.1
unnamed: Q1.1 (B), R1.2
unnamed: Q1.3 (C), RV1.2
unnamed: U11.2 (O0), U16.10 (IO)
unnamed: U11.5 (O1), U16.11 (I1)
unnamed: U11.6 (O2), U16.12 (I2)
unnamed: U11.9 (O3), U16.13 (I3)
unnamed: U11.12 (O4), U16.1 (I4)
unnamed: U11.15 (O5), U16.2 (I5)
unnamed: U11.16 (O6), U16.3 (I6)
unnamed: U11.19 (O7), U16.4 (I7)
unnamed: U13.8, U17.3 (WE), U18.3 (WE)

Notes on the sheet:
Buzzer
Enables mem to bus o when read mode (low)
Selects encoded address from pic when read mode (low)
ESP32
Analog switches supply diodes
Screen brightness source selection
Port B to bus for active mode
Columns data memory (SRAM)
SD supply
USB connector
Buttons
CHANGED from v1
SPI I/O expanders
DGT 3000 Jack
RFID
Screen
In version 1 is NC
ESP32 supply
Rows latch and address encoder
Control signals noise reduction pull-downs
Electrical isolation analog switches
Data capture circuit
In version 1 is inhib_inv
Allows to identify v2 passive mode hardware is present
In version 1 are display_control_a-c
Voltage translator 5V<->3.3V
Columns latch

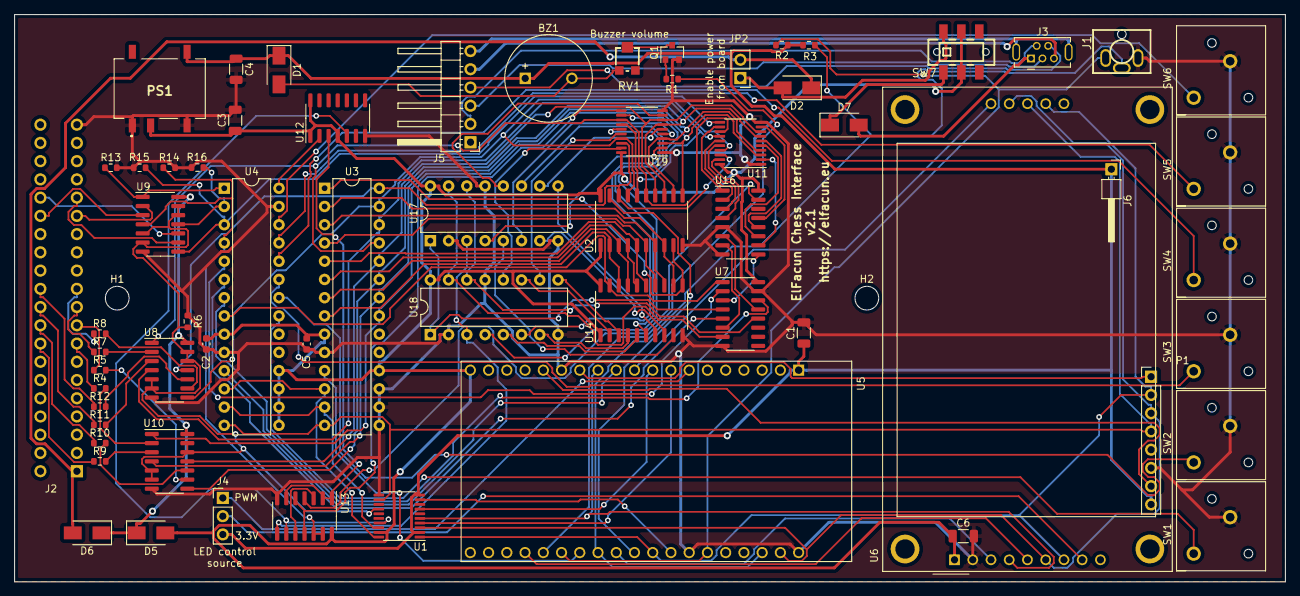
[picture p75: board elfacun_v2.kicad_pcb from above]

Board: 2 copper layers, 177.0 x 79.0 mm, 66 parts (0 on the bottom side), 126 nets.

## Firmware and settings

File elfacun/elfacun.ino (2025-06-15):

/*  
    ElFacun Chess Module software for ESP32
    © 2022 Inmbolmie inmbolmie [at] gmail [dot] com
    Distributed under the GNU GPL V3.0 license
    
    This program is distributed WITHOUT ANY WARRANTY, even the 
    implied warranty of MERCHANTABILITY or FITNESS FOR A PARTICULAR 
    PURPOSE.  See the GNU General Public License for more details.
*/

#define AA_FONT_SMALL "NotoSansBold15"
#define FS_NO_GLOBALS

#include "board.h"
#include "board_a.h"
#include "board_b.h"
#include "rfid.h"
#include "soc/rtc.h"
#include "ble_board_b.h"
#include "ble_board_c.h"
#include "i2c_clock.h"
#include "screen.h"
#include "serial.h"
#include "nvs_conf.h"
#include "system_update.h"
#include "lichess.h"
#include "driver/adc.h"

#define SPI_FREQUENCY  1000000
#define SPI_READ_FREQUENCY 500000


#include <FS.h>
#include "SPIFFS.h"
#include <SPI.h>
#include "soc/soc.h"
#include "soc/rtc_cntl_reg.h"
#include "esp_system.h"
#include "esp_bt_device.h"


#define INCLUDE_vTaskSuspend


// These are used to get information about static SRAM and flash memory sizes
extern "C" char __data_start[];    // start of SRAM data
extern "C" char _end[];     // end of SRAM data (used to check amount of SRAM this program's variables use)
extern "C" char __data_load_end[];  // end of FLASH (used to check amount of Flash this program's code and data uses)

int numloop = 0;

boolean firstScan = true;

boolean evenScan = true;

boolean chess960ModeAlreadySetUp = true; 

boolean positionRestoredFromHoldMode = false;

boolean startLichessConnection = false;

unsigned long timeScanRfid = 0;
unsigned long rfid_scan_interval = 250l;
unsigned long timeUpdateSprites = 0;
unsigned long sprite_update_interval = 50l;
unsigned long timeScan = 0;
unsigned long scan_interval = 25l;
unsigned long timeUpdateButtons = 0;
unsigned long buttons_update_interval = 50l;



//Hardware initialization
void setup() {

  ledbuffer.reserve(167);

  //ENABLE BOARD BUS
  pinMode(EN_BUS, OUTPUT);
  digitalWrite(EN_BUS, false);

  //clear led state boards
  clearAllBoardLeds();

  //disable ESP32 brownout detector, works really bad with non-usb power
  WRITE_PERI_REG(RTC_CNTL_BROWN_OUT_REG, 0);


  //Configure comms to board in default values
  pinMode(CONTROLLER_OUTPUT_DISABLE, OUTPUT);
  //disable PIC to bus
  digitalWrite(CONTROLLER_OUTPUT_DISABLE, true);

  //disable passive mode latches
  //LATCH_ROWS_DISABLE is output in V1 and WRITE_ENABLE_SAFE input in V2 on the same pin, so it is safer as input by default unless we detect V1 hardware
  pinMode(WRITE_ENABLE_SAFE, INPUT);
  pinMode(LATCH_COLUMNS_DISABLE, OUTPUT);
  //digitalWrite(LATCH_ROWS_DISABLE, true);
  //digitalWrite(LATCH_COLUMNS_DISABLE, true);

  pinMode(CONTROLLER_OUTPUT_CHIPSELECT, OUTPUT);
  digitalWrite(CONTROLLER_OUTPUT_CHIPSELECT, true);

  pinMode(CONTROLLER_OUTPUT_CHIPSELECT_BUTTONS, OUTPUT);
  digitalWrite(CONTROLLER_OUTPUT_CHIPSELECT_BUTTONS, true);

  pinMode(RFID_CS, OUTPUT);
  digitalWrite(RFID_CS, true);

  //initialize SPI to communicate with the screen, RFID, SD card and SPI expanders.
  SPI.begin();

  //initialize screen
  initialize_tft();

  SPI.setFrequency(10000000);

  //initialize SPI port expanders
  SPIExpander.begin();
  delay(100);
  SPIExpanderButtons.begin();

  //Set expander ports
  //INPUT PORT
  SPIExpander.pinMode(0, INPUT);
  SPIExpander.pinMode(1, INPUT);
  SPIExpander.pinMode(2, INPUT);
  SPIExpander.pinMode(3, INPUT);
  SPIExpander.pinMode(4, INPUT);
  SPIExpander.pinMode(5, INPUT);
  SPIExpander.pinMode(6, INPUT);
  SPIExpander.pinMode(7, INPUT);

  //OUTPUT PORT
  SPIExpander.pinMode(8, OUTPUT);
  SPIExpander.pinMode(9, OUTPUT);
  SPIExpander.pinMode(10, OUTPUT);
  SPIExpander.pinMode(11, OUTPUT);
  SPIExpander.pinMode(12, OUTPUT);
  SPIExpander.pinMode(13, OUTPUT);
  SPIExpander.pinMode(14, OUTPUT);
  SPIExpander.pinMode(15, OUTPUT);

  //BUTTONS
  SPIExpanderButtons.pinMode(0, INPUT_PULLUP);
  SPIExpanderButtons.pinMode(1, INPUT_PULLUP);
  SPIExpanderButtons.pinMode(2, INPUT_PULLUP);
  SPIExpanderButtons.pinMode(3, INPUT_PULLUP);
  SPIExpanderButtons.pinMode(4, INPUT_PULLUP);
  SPIExpanderButtons.pinMode(5, INPUT_PULLUP);
  //This will be switched to input when hardware detection is finished
  SPIExpanderButtons.pinMode(HARDWARE_V2_DETECT, INPUT_PULLUP);
  //This will be switched to output if V2 hardware is detected
  SPIExpanderButtons.pinMode(7, INPUT);

  //BUS CONTROL SIGNALS
  SPIExpanderButtons.pinMode(8, OUTPUT);
  SPIExpanderButtons.pinMode(9, OUTPUT);
  SPIExpanderButtons.pinMode(10, OUTPUT);
  SPIExpanderButtons.pinMode(11, OUTPUT);
  //These 4 will be switched to outputs if V2 hardware is detected
  SPIExpanderButtons.pinMode(12, INPUT);
  SPIExpanderButtons.pinMode(13, INPUT);
  SPIExpanderButtons.pinMode(14, INPUT);
  SPIExpanderButtons.pinMode(15, INPUT);

  //Put the bus in staeady mode
  busValuesToDefault();


  //Detect V2 hardware with improved passive mode capture hardware
  isV2Hardware = !SPIExpanderButtons.digitalRead(HARDWARE_V2_DETECT);

  if (!isV2Hardware) {
    //disable passive mode latches
    pinMode(LATCH_ROWS_DISABLE, OUTPUT);
    pinMode(LATCH_COLUMNS_DISABLE, OUTPUT);
    digitalWrite(LATCH_ROWS_DISABLE, true);
    digitalWrite(LATCH_COLUMNS_DISABLE, true);

  } else {
    //Set brightness to a medium value
    pinMode(SCREEN_BRIGHTNESS, OUTPUT);
    setTftBrightness(64);
  }

  SPIExpanderButtons.pinMode(HARDWARE_V2_DETECT, INPUT);

  //V2 hardware initialization
  if (isV2Hardware) {

    pinMode(SCREEN_BRIGHTNESS, OUTPUT);

    SPIExpanderButtons.pinMode(MEM_WRITE_ENABLE, OUTPUT);
    SPIExpanderButtons.pinMode(MEM_ADDR_0, OUTPUT);
    SPIExpanderButtons.pinMode(MEM_ADDR_1, OUTPUT);
    SPIExpanderButtons.pinMode(MEM_ADDR_2, OUTPUT);
    SPIExpanderButtons.pinMode(MEM_ADDR_SRC, OUTPUT);

    SPIExpanderButtons.digitalWrite(MEM_WRITE_ENABLE, false);
    SPIExpanderButtons.digitalWrite(MEM_ADDR_0, false);
    SPIExpanderButtons.digitalWrite(MEM_ADDR_1, false);
    SPIExpanderButtons.digitalWrite(MEM_ADDR_2, false);
    SPIExpanderButtons.digitalWrite(MEM_ADDR_SRC, MEM_ADDR_SRC_BUS);

  }


  //initialize nvs keystore to store/read overridden configuration parameters
  initialize_nvs();

  //SD card chipselect
  pinMode(SD_CS, OUTPUT);
  digitalWrite(SD_CS, true);

  //adc_power_off();
  //WiFi.disconnect(true);  // Disconnect from the network
  //WiFi.mode(WIFI_OFF);    // Switch WiFi off
  //setCpuFrequencyMhz(160);

  //tft.println("CHECK SD");

  //Check SD card presence
  //Does not work with ESP 2.0.0-2.0.2 (?)
  if (SD.begin(SD_CS)) {

    uint8_t cardType;
    cardType = SD.cardType();

    if (cardType == CARD_NONE) {
      tft.println("SD card not found");
      delay(500);
    } else {
      //Update system firmware from SD if update.bin is present
      tft.fillScreen(TFT_BLACK);
      tft.setCursor(0, 0);
      updateFromFS(SD);

    }

    //Overwrite nvs config from sd if settings.txt is present in the SD
    read_config_sd_store_nvs();

    checkRemoteUpdateFromFS(SD);

    //Check for new resources
    //Commented out as it is somehow corrupting SPIFFS
    //SPIFFS.begin();
    //load_file_from_sd_to_spiffs("/modea.bmp");
    //load_file_from_sd_to_spiffs("/modeb.bmp");
    //load_file_from_sd_to_spiffs("/modec.bmp");
    //clearScreen();
    //SPIFFS.end();

    SD.end();

  } else {
    tft.println("SD CARD NOT FOUND");
    delay(100);
  }

  //Disable SD card
  digitalWrite(SD_CS, true);


  //setCpuFrequencyMhz(240);
  //adc_power_on();
  //WiFi.disconnect(false);  // Reconnect the network
  //WiFi.mode(WIFI_STA);    // Switch WiFi off

  //Initialize SPIFFS to get bmp files for displaying
  SPIFFS.begin();


  //Clear screen
  tft.fillScreen(TFT_BLACK);
  tft.setCursor(0, 0);
  //tft.setTextColor(TFT_WHITE); tft.setTextSize(1);

  //Read config from NVS if has been stored there at any time from SD card
  read_config_nvs();





  //Load custom base MAC address for BT if defined
  //BT address will be base MAC plus 2
  tft.print("BASE MAC: ");
  tft.println(baseMacAddress);
  if (baseMacAddress != "") {
    uint8_t new_mac[8];
    sscanf(baseMacAddress, "%2x:%2x:%2x:%2x:%2x:%2x", &new_mac[0], &new_mac[1], &new_mac[2], &new_mac[3], &new_mac[4], &new_mac[5]);
    esp_base_mac_addr_set(new_mac);
    tft.printf("Mac assigned: %2x:%2x:%2x:%2x:%2x:%2x\n", new_mac[0], new_mac[1], new_mac[2], new_mac[3], new_mac[4], new_mac[5]);
  } else {
    tft.println("Setting default mac addr");
  }



  //Decide the mode we will initialize in.
  //A-> Serial port @ 9600 bauds + BT
  //B-> Serial port @ 38400 bauds + BT
  //C-> Lichess over WIFI
  //Modes A and B are incompatible over USB as mode a is 9600 bauds and mode B is 38400 bauds.
  //Modes A and B should be compatible over Bluetooth, you can connect either A or B board regardless of the mode we boot on
  //BLE can be used in both A and B modes
  //
  //So the difference between booting in A or B mode is:
  //A mode-> serial speed is 9600, Bluetooth advertised name is mode.a.bt.advertised.name
  //B mode-> serial speed is 38400, Bluetooth advertised name is mode.b.bt.advertised.name

  boolean noButtonsPushed = SPIExpanderButtons.digitalRead(0) && SPIExpanderButtons.digitalRead(1) && SPIExpanderButtons.digitalRead(2);

  boolean forcePassiveMode = !SPIExpanderButtons.digitalRead(3);

  //dim screen to reduce battery draw while initializing
  setTftBrightness(0);

  boolean startBleService = false;

  boolean startBleServiceC = false;

  enableNvsLog = false;

  centerBoardOnScreen = false;

  boolean lichessGameStarted = isLichessGameInProgress();

  if ((noButtonsPushed && strcmp(defaultMode, "L") == 0) || !SPIExpanderButtons.digitalRead(2) || (noButtonsPushed && lichessGameStarted) ) {
    //For Lichess

    isBrightnessAdjustmentDisabled = false;

    displayLichessLogo();

    initializeWifi();

    delay(2000);

    tft.setCursor(0, 0);

    Serial.begin(115200);

    if (isV2Hardware) {
      if (serialLog) Serial.println("V2 hardware lichess mode");
    } else {
      if (serialLog) Serial.println("V1 hardware lichess mode");
    }

    startLichessConnection = true;

    //Disable board scanning until we process the first fen
    disableBoardScanning = true;

  }


  else if ((noButtonsPushed && strcmp(defaultMode, "C") == 0) || (!SPIExpanderButtons.digitalRead(1) && !SPIExpanderButtons.digitalRead(0))) {
    //For type C board

    isBrightnessAdjustmentDisabled = false;

    if (!noButtonsPushed && lichessGameStarted) {
      //abort
      setLichessGameFinished();
    }

    displayModeCLogo();

    Serial.begin(9600);
    if (isV2Hardware) {
      if (serialLog) Serial.println("V2 hardware C mode");
    } else {
      if (serialLog) Serial.println("V1 hardware C mode");
    }

    //Needed to read the mac and not confuse IOS devices with the new mac
    SerialBT.begin(modeABtAdvertisedName);

    //Change mac address for mode C
    const uint8_t* mac;


    mac = esp_bt_dev_get_address();

    if (mac[5] <= 250) {
      modeCmac[5] = mac[5] + 2;
    } else {
      modeCmac[5] = mac[5] - 6;
  }

    modeCmac[4] = mac[4];
    modeCmac[3] = mac[3];
    modeCmac[2] = mac[2];
    modeCmac[1] = mac[1];
    modeCmac[0] = mac[0];

    esp_base_mac_addr_set(modeCmac);

    SerialBT.end();
    SerialBT.begin(modeCBtAdvertisedName);

    initBleC();

    startBleServiceC = true;


  }






  else if ((noButtonsPushed && strcmp(defaultMode, "B") == 0) || !SPIExpanderButtons.digitalRead(1)) {
    //For type B board

    isBrightnessAdjustmentDisabled = false;

    if (!noButtonsPushed && lichessGameStarted) {
      //abort
      setLichessGameFinished();
    }

    Serial.begin(38400, SERIAL_7O1);
    if (isV2Hardware) {
      if (serialLog) Serial.println("V2 hardware B mode");
    } else {
      if (serialLog) Serial.println("V1 hardware B mode");
    }

    displayModeBLogo();

    SerialBT.begin(modeBBtAdvertisedName);
    isTypeBUSBBoard = true;

    centerBoardOnScreen = true;

    initBle();

    startBleService = true;

  } else {

    isBrightnessAdjustmentDisabled = false;

    if (!noButtonsPushed && lichessGameStarted) {
      //abort
      setLichessGameFinished();
    }

    //For type A board
    displayModeALogo();

    Serial.begin(9600);
    if (isV2Hardware) {
      if (serialLog) Serial.println("V2 hardware A mode");
    } else {
      if (serialLog) Serial.println("V1 hardware A mode");
    }

    SerialBT.begin(modeABtAdvertisedName);

    initBle();

    startBleService = true;

  }


  //initialize RFID reader/writer
  rfid_init();

  if (startLichessConnection) {
    rfid_scan_interval = 1000l;
    scan_interval = 50l;
  }


  //Sound will be disabled if we boot pushing the change lever button
  if ((!SPIExpanderButtons.digitalRead(5) && (strcmp(buzzerEnabled, "TRUE") == 0)) || (SPIExpanderButtons.digitalRead(5) && (strcmp(buzzerEnabled, "FALSE") == 0))) {
    if (serialLog) Serial.println("Disabling sound from button");
    soundIsDisabled = true;
  }


  if (!SPIExpanderButtons.digitalRead(5) && (strcmp(buzzerEnabled, "FALSE") == 0)) {
    if (serialLog) Serial.println("Enabling sound from button");
    soundIsDisabled = false;
  }
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
void loop() {

  //if (serialLog) Serial.println("Loop");
  evenScan = !evenScan;

  //Check if Bluetooth is connected
  if (!isLichessConnected && !startLichessConnection) {
    btConnected = SerialBT.connected(10);
  }

  if ((!isLichessConnected && !startLichessConnection && SerialBT.available()) || Serial.available())
  {
    //noInterrupts();
    byte rcv;
    rcv = readSerial();


    //Process incoming opcodes

    //Check if we are connected to a type B board via USB. If so acivate that mode. In any other case we assume the board is type A
    if (firstCharacterReceived && (((rcv & 0x7F) == 0x56) || ((rcv & 0x7F) == 0x57))) {
      isTypeBUSBBoard = true;
      if (serialLog) Serial.println("Mode B activated");
    }

    firstCharacterReceived = false;

    if (!isTypeBUSBBoard) {
      //Type A board, we call type a command loop
      board_a_command_loop(rcv) ;

    } else {
      //Type B board, we call type b command loop
      board_b_command_loop(rcv) ;

    }
  }


  //BLE remote update
  if (sendRemoteUpdateFileOverBLE) {
    performRemoteUpdate();
    sendRemoteUpdateFileOverBLE = false;
    bleDeviceRequestedUpdateFile = false;

  }

  unsigned long now = millis();
  if (now > timeScan) {

    timeScan = now + scan_interval;

    //GET SPI BUS
    boolean isSemaphoreTaken = true;
    if (!xSemaphoreTake( xScreenSemaphore, ( TickType_t ) screenSemaphoreTimeout )) {
      isSemaphoreTaken = false;
      if (serialLog) Serial.println("XXXXXXXXXXXXXXX   ERROR TAKING SEMAPHORE AT (now > timeScan), skipping loop ");

    } else {

      //START OF SPI CRITICAL SECTION

  //Read board state passively reading the bus if on PASSIVE mode. We will loop waiting for data for the eight rows that usually we will get in sequence
  int numRowsScanned = 0;
      if (!holdMode && isPassiveMode && !isV2Hardware && !disableBoardScanning) {

    byte rowsScanned = 0xFF;
    byte scannedRowValue = 0;
    byte scannedColValue = 0;

    //if (serialLog) Serial.println("------------->SCANNING ROWS");

    while (rowsScanned != 0x00) {
      numRowsScanned++;

      //Block until external latch inhibition signal fires to indicate latches are freshly loaded
      while (SPIExpanderButtons.digitalRead(INHIB_INV)) {
        //delay(1);
      }
      delayMicroseconds(20);

      digitalWrite(LATCH_ROWS_DISABLE, false);
      //delay(1);
      scannedRowValue = SPIExpander.readPort(1);
      digitalWrite(LATCH_ROWS_DISABLE, true);
      digitalWrite(LATCH_COLUMNS_DISABLE, false);
      //delay(1);
      scannedColValue = SPIExpander.readPort(1);
      digitalWrite(LATCH_COLUMNS_DISABLE, true);


      byte encodedRowValue = 8;
      if (scannedRowValue == 0b11111110) encodedRowValue = 7;
      if (scannedRowValue == 0b11111101) encodedRowValue = 6;
      if (scannedRowValue == 0b11111011) encodedRowValue = 5;
      if (scannedRowValue == 0b11110111) encodedRowValue = 4;
      if (scannedRowValue == 0b11101111) encodedRowValue = 3;
      if (scannedRowValue == 0b11011111) encodedRowValue = 2;
      if (scannedRowValue == 0b10111111) encodedRowValue = 1;
      if (scannedRowValue == 0b01111111) encodedRowValue = 0;


      if (encodedRowValue > 7) {
        //Error
        //        if (serialLog) Serial.print("ERROR :Invalid row value scanned: ");
        //        if (serialLog) Serial.println(scannedRowValue, BIN);

      }

      else {

        if (!boardInverted) {
          //reverse scan positions
          scannedpos[(8 * encodedRowValue) + 0 ] = !bitRead(scannedColValue, 0);
          scannedpos[(8 * encodedRowValue) + 1 ] = !bitRead(scannedColValue, 1);
          scannedpos[(8 * encodedRowValue) + 2 ] = !bitRead(scannedColValue, 2);
          scannedpos[(8 * encodedRowValue) + 3 ] = !bitRead(scannedColValue, 3);
          scannedpos[(8 * encodedRowValue) + 4 ] = !bitRead(scannedColValue, 4);
          scannedpos[(8 * encodedRowValue) + 5 ] = !bitRead(scannedColValue, 5);
          scannedpos[(8 * encodedRowValue) + 6 ] = !bitRead(scannedColValue, 6);
          scannedpos[(8 * encodedRowValue) + 7 ] = !bitRead(scannedColValue, 7);

        } else {
              scannedpos[ (8 * (7 - encodedRowValue)) + 0 ] = !bitRead(scannedColValue, 7);
              scannedpos[ (8 * (7 - encodedRowValue)) + 1 ] = !bitRead(scannedColValue, 6);
              scannedpos[ (8 * (7 - encodedRowValue)) + 2 ] = !bitRead(scannedColValue, 5);
              scannedpos[ (8 * (7 - encodedRowValue)) + 3 ] = !bitRead(scannedColValue, 4);
              scannedpos[ (8 * (7 - encodedRowValue)) + 4 ] = !bitRead(scannedColValue, 3);
              scannedpos[ (8 * (7 - encodedRowValue)) + 5 ] = !bitRead(scannedColValue, 2);
              scannedpos[ (8 * (7 - encodedRowValue)) + 6 ] = !bitRead(scannedColValue, 1);
              scannedpos[ (8 * (7 - encodedRowValue)) + 7 ] = !bitRead(scannedColValue, 0);
        }

        rowsScanned = rowsScanned & scannedRowValue;

        //        if (serialLog) Serial.print("ROW VALUE: ");
        //        if (serialLog) Serial.print(scannedRowValue, BIN);
        //        if (serialLog) Serial.print(" REMAINING: ");
        //        if (serialLog) Serial.print(rowsScanned, BIN);
        //        if (serialLog) Serial.print(" COL VALUE: ");
        //        if (serialLog) Serial.println(scannedColValue, BIN);

      }

      //3ms is approx the time that long inhibition signal is active so no point in sampling again now
      delay(3);
    }

    if (numRowsScanned > 50) {
      if (serialLog) Serial.print("TOO MANY ROWS SCANNED: ");
      if (serialLog) Serial.println(numRowsScanned, DEC);
    }
  }


      if (!holdMode && isPassiveMode && isV2Hardware && evenScan && !disableBoardScanning) {


        //Read position from memory
        numScansV2++;
        //Switch memory to read mode
        SPIExpanderButtons.digitalWrite(MEM_WRITE_ENABLE, false);
        //wait till it is safe to scan

        unsigned long startTime = millis();
        while (digitalRead(WRITE_ENABLE_SAFE)) {
          if (millis() > startTime + 500) {
            slowMode = true;
            SPIExpanderButtons.digitalWrite(MEM_WRITE_ENABLE, true);
            goto SKIP;
          }
        }


        if (positionRestoredFromHoldMode) {
          //We force WRITE_ENABLE_SAFE to make at least a transition from false to true to check that there is really a module out there
          //needed not to lose the restored position
          SPIExpanderButtons.digitalWrite(MEM_WRITE_ENABLE, true);
          startTime = millis();
          while (!digitalRead(WRITE_ENABLE_SAFE)) {
            if (millis() > startTime + 500) {
              slowMode = true;
              goto SKIP;
            }
          }

          //There is a module out there, resume normal operation
          SPIExpanderButtons.digitalWrite(MEM_WRITE_ENABLE, false);
          startTime = millis();
          while (digitalRead(WRITE_ENABLE_SAFE)) {
            if (millis() > startTime + 500) {
              slowMode = true;
              SPIExpanderButtons.digitalWrite(MEM_WRITE_ENABLE, true);
              goto SKIP;
            }
          }

        }

        slowMode = false;

        delayMicroseconds(1);
        SPIExpanderButtons.digitalWrite(MEM_ADDR_SRC, MEM_ADDR_SRC_PIC);


        boolean piecesOnBoard = false;
        byte scannedColValue = 0;
        while (numRowsScanned < 8) {

          SPIExpanderButtons.digitalWrite(MEM_ADDR_0, numRowsScanned & 0x01);
          SPIExpanderButtons.digitalWrite(MEM_ADDR_1, (numRowsScanned & 0x02) >> 1);
          SPIExpanderButtons.digitalWrite(MEM_ADDR_2, (numRowsScanned & 0x04) >> 2);
          delayMicroseconds(1);
          scannedColValue = SPIExpander.readPort(1);

          for (int i = 0; i < 8; i++) {

            boolean scannedBit;

            int rowIndex;

            if  (!boardInverted)  {
              scannedBit = bitRead(scannedColValue, i);
              rowIndex = numRowsScanned;
            } else {
              scannedBit = bitRead(scannedColValue, (7 - i));
              rowIndex = 7 - numRowsScanned;
            }

            if (scannedBit) {
              piecesOnBoard = true;
            }

            if (scannedBit != scannedposV2[(8 * rowIndex) + i ]) {
              //begin again
              numScansV2 = 0;
            }

            scannedposV2[(8 * rowIndex) + i ] = scannedBit;

          }
          numRowsScanned++;
        }


        //Count changed squares
        int numPiecesScanned = 0;
        int numPiecesPos = 0;
        for (int i = 0; i < 64; i++) {
          if (scannedpos[i]) {
            numPiecesScanned++;
          }
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

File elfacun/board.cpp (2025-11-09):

/*
    ElFacun Chess Module software for ESP32
    © 2022 Inmbolmie inmbolmie [at] gmail [dot] com
    Distributed under the GNU GPL V3.0 license

    This program is distributed WITHOUT ANY WARRANTY, even the
    implied warranty of MERCHANTABILITY or FITNESS FOR A PARTICULAR
    PURPOSE.  See the GNU General Public License for more details.
*/

#include "board.h"

Movement *lastMovement = NULL;

boolean boardIsOutOfSync = false;

SquareChange changes[100];
int numChanges = 0;

byte initpos[64] = {8, 9, 10, 12, 11, 10, 9, 8,
                    7, 7, 7, 7, 7, 7, 7, 7,
                    0, 0, 0, 0, 0, 0, 0, 0,
                    0, 0, 0, 0, 0, 0, 0, 0,
                    0, 0, 0, 0, 0, 0, 0, 0,
                    0, 0, 0, 0, 0, 0, 0, 0,
                    1, 1, 1, 1, 1, 1, 1, 1,
                    2, 3, 4, 6, 5, 4, 3, 2
                   };


byte onlypawnspos[64] = {0, 0, 0, 0, 0, 0, 0, 0,
                    7, 7, 7, 7, 7, 7, 7, 7,
                    0, 0, 0, 0, 0, 0, 0, 0,
                    0, 0, 0, 0, 0, 0, 0, 0,
                    0, 0, 0, 0, 0, 0, 0, 0,
                    0, 0, 0, 0, 0, 0, 0, 0,
                    1, 1, 1, 1, 1, 1, 1, 1,
                    0, 0, 0, 0, 0, 0, 0, 0
                   };



byte lastDrawn[64] = {255, 255, 255, 255, 255, 255, 255, 255,
                      255, 255, 255, 255, 255, 255, 255, 255,
                      255, 255, 255, 255, 255, 255, 255, 255,
                      255, 255, 255, 255, 255, 255, 255, 255,
                      255, 255, 255, 255, 255, 255, 255, 255,
                      255, 255, 255, 255, 255, 255, 255, 255,
                      255, 255, 255, 255, 255, 255, 255, 255,
                      255, 255, 255, 255, 255, 255, 255, 255
                     };


byte lastDrawnBG[64] = {0, 1, 0, 1, 0, 1, 0, 1,
                        0, 1, 0, 1, 0, 1, 0, 1,
                        0, 1, 0, 1, 0, 1, 0, 1,
                        0, 1, 0, 1, 0, 1, 0, 1,
                        0, 1, 0, 1, 0, 1, 0, 1,
                        0, 1, 0, 1, 0, 1, 0, 1,
                        0, 1, 0, 1, 0, 1, 0, 1,
                        0, 1, 0, 1, 0, 1, 0, 1
                       };

boolean lastpos[64] = { true, true, true, true, true, true, true, true,
                        true, true, true, true, true, true, true, true,
                        false, false, false, false, false, false, false, false,
                        false, false, false, false, false, false, false, false,
                        false, false, false, false, false, false, false, false,
                        false, false, false, false, false, false, false, false,
                        true, true, true, true, true, true, true, true,
                        true, true, true, true, true, true, true, true,
                      };

boolean scannedpos[64] = { true, true, true, true, true, true, true, true,
                           true, true, true, true, true, true, true, true,
                           false, false, false, false, false, false, false, false,
                           false, false, false, false, false, false, false, false,
                           false, false, false, false, false, false, false, false,
                           false, false, false, false, false, false, false, false,
                           true, true, true, true, true, true, true, true,
                           true, true, true, true, true, true, true, true,
                         };

boolean scannedposV2[64] = { true, true, true, true, true, true, true, true,
                             true, true, true, true, true, true, true, true,
                             false, false, false, false, false, false, false, false,
                             false, false, false, false, false, false, false, false,
                             false, false, false, false, false, false, false, false,
                             false, false, false, false, false, false, false, false,
                             true, true, true, true, true, true, true, true,
                             true, true, true, true, true, true, true, true,
                           };


boolean transposescannedpos[64];


boolean passivescannedpos[64] = { true, true, true, true, true, true, true, true,
                                  true, true, true, true, true, true, true, true,
                                  false, false, false, false, false, false, false, false,
                                  false, false, false, false, false, false, false, false,
                                  false, false, false, false, false, false, false, false,
                                  false, false, false, false, false, false, false, false,
                                  true, true, true, true, true, true, true, true,
                                  true, true, true, true, true, true, true, true,
                                };
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

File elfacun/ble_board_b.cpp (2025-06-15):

/*
    ElFacun Chess Module software for ESP32
    © 2022 Inmbolmie inmbolmie [at] gmail [dot] com
    Distributed under the GNU GPL V3.0 license

    This program is distributed WITHOUT ANY WARRANTY, even the
    implied warranty of MERCHANTABILITY or FITNESS FOR A PARTICULAR
    PURPOSE.  See the GNU General Public License for more details.
*/

#include "ble_board_b.h"


BLEServer *pServer = NULL;
BLECharacteristic * pTxCharacteristic;
BLEService *pService;

boolean bleDeviceRequestedUpdateFile = false;

boolean isDiablilloConnected = false;



void startAdvertisement() {

  pServer->getAdvertising()->setAppearance(GENERIC_HID);

  BLEAdvertisementData oAdvertisementData = BLEAdvertisementData();

  oAdvertisementData.setShortName(modeBBtAdvertisedName);
  oAdvertisementData.setName(modeBBtAdvertisedName);
  oAdvertisementData.setAppearance(GENERIC_HID);
  oAdvertisementData.setPartialServices(BLEUUID::fromString("31f4"));

  pServer->getAdvertising()->setAdvertisementData(oAdvertisementData);

  pServer->getAdvertising()->setScanResponse(true);

  pServer->getAdvertising()->start();

}

void stopAdvertisement() {

  pServer->getAdvertising()->stop();

}




void ackMB_UPDATE_INFO(uint32_t size, char* crc)
{

  byte responseData1[20];
  byte responseData2[4];
  byte responseData3[11];


  //ack
  for (int i = 0; i < 20; i++) {
    responseData1[i] = 0x33;
  }


  //size
  responseData2[0] = (uint8_t)(size >> 24);
  responseData2[1] = (uint8_t)(size >> 16);
  responseData2[2] = (uint8_t)(size >> 8);
  responseData2[3] = (uint8_t)(size >> 0);


  //crc
  if (size > 0) {
    memcpy(responseData3, crc, 11);
  }

  if ( xSemaphoreTake( xSendDataBLESemaphore, ( TickType_t ) portMAX_DELAY ) == pdTRUE )
  {
    sendDataTypeBBoard(responseData1, 20);
    delay(100);
    sendDataTypeBBoard(responseData2, 4);
    delay(100);
    sendDataTypeBBoard(responseData3, 11);

    xSemaphoreGive( xSendDataBLESemaphore );
  }

}





//Callback for BLE data reception
class MyCallbacks: public BLECharacteristicCallbacks {

    void onWrite(BLECharacteristic *pCharacteristic) {
      std::string rxValueRaw = pCharacteristic->getValue();

      //TBM SPLIT MULTIPLE COMMANDS INSIDE rxValue

      if (rxValueRaw.length() > 0) {

        int chunk = 1;

        if (serialDebug) {

          if (serialDebug) Serial.println(" ");
          if (serialDebug)  Serial.print("RECEIVED DATA LEN: ");
          if (serialDebug)  Serial.print(rxValueRaw.length(), DEC);
          if (serialDebug)  Serial.print(" DATA: ");
          for (int i = 0; i < rxValueRaw.length(); i++) {
            if (serialDebug)  Serial.print(rxValueRaw[i], HEX);
            if (serialDebug)  Serial.print(" ");
          }

          if (serialDebug) Serial.println(" ");

        }


        int bytesToProcess = rxValueRaw.length();
        int indexToProcess = 0;

        while (bytesToProcess > 0) {


          int bytesForCommand = 0;

          //first case: we are in the middle of a LED command
          if (!ledbuffer.empty()) {

            bytesForCommand = min(bytesToProcess, (167 - (int)ledbuffer.size()));

          } else if ((rxValueRaw[indexToProcess] & 0x7F) ==  MB_L_LED) {

            bytesForCommand = min(bytesToProcess, 167);

          } else if ((rxValueRaw[indexToProcess] & 0x7F) ==  MB_V_VERSION) {

            bytesForCommand = 3;

          } else if ((rxValueRaw[indexToProcess] & 0x7F) ==  MB_X_OFFLED) {

            bytesForCommand = 3;

          } else if ((rxValueRaw[indexToProcess] & 0x7F) ==  MB_S_STATUS) {

            bytesForCommand = 3;

          } else if ((rxValueRaw[indexToProcess] & 0x7F) ==  MB_R_READ) {

            bytesForCommand = 5;

          } else if ((rxValueRaw[indexToProcess] & 0x7F) ==  MB_W_WRITE) {

            bytesForCommand = 7;

          } else if ((rxValueRaw[indexToProcess] & 0x7F) ==  MB_ADV_WRITE) {

            bytesForCommand = 3;

          } else if ((rxValueRaw[indexToProcess] & 0x7F) ==  MB_XLED_WRITE) {

            bytesForCommand = 19;

          } else if ((rxValueRaw[indexToProcess] & 0x7F) ==  MB_UPDATE_INFO) {

            bytesForCommand = 3;

          } else if ((rxValueRaw[indexToProcess] & 0x7F) ==  MB_UPDATE_READ) {

            bytesForCommand = 3;

          } else {
            //error
            bytesToProcess = 0;
            if (serialLog) Serial.println("ERROR, BYTES REMAINING WHILE PROCESSING COMMANDS");
            ledbuffer.clear();
            return;
          }

          if (bytesForCommand > bytesToProcess) {
            if (serialLog) Serial.println("ERROR, INCOMPLETE BLE COMMAND PROCESSING COMMANDS");
            ledbuffer.clear();
            return;
          }

          std::string rxValue = rxValueRaw.substr(indexToProcess, bytesForCommand);
          bytesToProcess -= bytesForCommand;
          indexToProcess += bytesForCommand;


          if (extraBLElog && rxValue.length() > 0) {
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

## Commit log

2022-02-23 BLE now working with Grahan O'Neill drivers
2022-03-05 Powering the module section
2022-04-10 Update MANUAL.md
    USB driver install link
2022-07-12 New module and board compatibility reports
2022-09-03 Source code and design files for v1.1 module
    [bottom.stl, buttons_support.stl, elfacun_11.kicad_pcb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]
2023-01-26 Updated documentation for Elfacun module version 2 and Brocoli power module
2023-06-14 Driver attribution
2025-06-15 V2 hardware
    [bottom.stl, buttons_support.stl, elfacun_11.kicad_pcb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]
2025-11-09 Fix first row led flicker
    [board.cpp]

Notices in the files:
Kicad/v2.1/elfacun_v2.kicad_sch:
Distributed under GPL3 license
